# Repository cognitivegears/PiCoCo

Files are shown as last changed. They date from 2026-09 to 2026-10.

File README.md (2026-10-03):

# PiCoCo

A Raspberry Pi Pico 2 (or Waveshare RP2350B-Plus-W) carrier that plugs into
the cartridge slot of a Tandy Color Computer (CoCo 1/2/3). It boots an
HDB-DOS ROM, serves DriveWire disk images through a Becker port at
$FF41/$FF42, and has an output stage for the cartridge sound input (the sound
firmware is not written). Licence: CERN-OHL-S-2.0
(hardware), MIT (firmware), CC-BY-SA-4.0 (docs); see `LICENSE`.

Board revision: **v2.3.1** (98 x 77.2 mm, 2 layers, hard-gold fingers).
Design docs: `docs/hardware-design.md`, `docs/firmware-architecture.md`,
`docs/kicad-workflow.md`. Ordering: `fab/main/READ-BEFORE-ORDERING.txt`.

## If you have a bare board

This is a **bare 98 x 77 mm board with no shell**. It fits no Program Pak
case — the 53.34 x 44.45 mm outline mentioned in the v2.3 spec is the
cased, future-variant footprint, not this board.

1. **Orientation.** The board has no shell and no key. The component side is
   the top; the front silkscreen says `THIS SIDE UP` near the finger tongue
   and the back says `OTHER SIDE UP`. Inserted upside down, +5 V lands on the
   CoCo's /CTS line. There is no reverse protection.
2. **Power off before inserting or removing.** Every insertion.
3. **Module.** Solder a Pico 2 flat on the castellations or on 2x20 headers;
   a Plus-W goes flat (castellations plus the 15 hidden pads; use the
   `stencil-module` paste stencil for the 15 grid pads only and hand-solder
   the castellations). A flat-mounted Pico 2 rests its three underside debug
   pads on grid pads GP29/GP32/GP35: put Kapton tape over those three pads
   first, or use headers. Nothing else goes under the module.
4. **Jumpers (solder bridges, defaults as shipped).**
   - `JP2` 1-2: U10 data-buffer /OE from the hardware decode (default).
     2-3: /OE from firmware GP31 (Plus-W only). Today's firmware holds GP31
     high, so leave JP2 at 1-2 on every build.
   - `JP3` 1-2: audio PWM to header pin 34 (default; sound works on a Pico 2).
     2-3: E clock to header pin 34 instead. Never bridge 2-3 and drive GP34 on
     a Plus-W at the same time.
   - `JP4` open (default): bridge to tie Q to /CART for cartridge autostart of
     ROM images (the classic Program Pak trick). **Bridging JP4 breaks
     HDB-DOS and any DK-signature DOS ROM** — it pulses /CART on every cycle,
     so the CPU jumps to $C000 as code continuously, and a DOS ROM's first
     bytes ("DK") are not a valid instruction. Only bridge it for a
     cartridge-style ROM that expects the classic autostart hookup.
   - `J2` / `J3` (DNP 1x3 pin headers) are twins of JP3 and JP5 on the same
     nets: fit one and use a shunt if you expect to flip the setting often.
     Cut the solder jumper first — a bridged JP and a shunt in the other
     position would short two signals.
   - `JP5` open (default): shares header pin 34 with JP3, so bridge at most
     one of them. 1-2 gives a Pico 2 a firmware-pulsed /CART (the Q4 stage,
     populated); 2-3 gives a firmware-pulsed /NMI instead (the Q3 stage —
     fit R15/R17 too). No firmware drives either position yet.
5. **DNP parts** (not fitted by default): R2 R10 R15 R17 Q3 C12 C15 J1 J2 J3. These
   are all Plus-W provisions or optional stages, by design, not leftover
   indecision — a Pico 2 build works correctly without them. Removing R7
   disables the /HALT boot hold: a blank or dead module then no longer
   halts the CoCo, so a dead Pico presents to the user as a dead CoCo — that
   is the intended failure mode of the hold, not a fault to debug around.
   Fitting C15 (1 uF) and removing R24 gives AC-coupled sound. `J1` ("EXP
   (Plus-W)") breaks out four pad-grid pins that only exist on a Plus-W.
6. **Test points.** TP1 OE_BUS, TP2 RW_BUF, TP3 CTS_BUF, TP4 SCS_BUF, TP5 E_BUF,
   TP6 +3V3, TP7 SND_CART (sound output to the cart), TP8 GND.
7. **Flashing.** Hold BOOTSEL on the module and plug USB in; copy the UF2
   from `firmware/` (see `firmware/README.md`). With the board in the CoCo,
   holding BOOTSEL and pressing the CoCo's own RESET button also enters the
   bootloader, because cart /RESET is tied to the module's RUN pin (R9).
8. **Disk images.** The firmware keeps images in the module's flash and is
   driven from the USB console (`firmware/README.md`). Wi-Fi DriveWire needs
   the Plus-W (`becker net`, `firmware/README.md` "WiFi").
9. **Multi-Pak Interface.** Select the PiCoCo slot for both /CTS and /SCS
   (`POKE &HFF7F` slot value) — the slot register ghosts at `$FF9F` as well
   as `$FF7F`; a CoCo 3 needs the upgraded MPI PAL. The 98 mm body may not
   fit some MPI slot openings; measure first.
10. **Is it alive?** On a CoCo 3, BASIC `PEEK(&HC000)` never reaches the
    cart — check `$FF41`/`$FF42` (the Becker status/data registers) instead.
11. **HDB-DOS.** Not shipped with this board — build it yourself with a
    single `make` from ToolShed's `hdbdos/` tree, or get a prebuilt image
    from Cloud-9 (see `docs/ADDITIONAL_ROADMAP.md` §3 for why binaries
    aren't checked in here). Credit to the DriveWire and HDB-DOS authors and
    maintainers, whose protocol and ROM this board depends on entirely.

## Repository map

```
PiCoCo/        KiCad 10 project (schematic is generated: edit tools/gen_schematic.py)
libraries/     local symbols and footprints (Pico-Carrier, COCO-CART)
tools/         generators and routing/fab tooling (see docs/kicad-workflow.md)
fab/main/      JLCPCB package: Gerber zip, BOM, CPL, module stencil, ordering checklist
breakout/      breadboard-phase boards (cart fingers to 2x20 header, cobbler)
firmware/      RP2350 firmware (host-testable core)
docs/          design documents and roadmap
```

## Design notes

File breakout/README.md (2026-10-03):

# PiCoCo Cartridge Breakout v1.0

A dumb adapter: the 40 fingers of a Tandy Color Computer cartridge slot
brought out 1:1 to a 2x20 0.1" header, so the PiCoCo bus interface can
be breadboarded. It carried the breadboard phase before the main board
existed; `docs/breadboard-plan.md` points to the results.

```
CoCo slot ──[this board]──40-way IDC ribbon──[2x20-to-breadboard adapter]──breadboard
```

Everything here is generated by `tools/gen_breakout.py` (run it with
KiCad's bundled Python). Do not hand-edit the `.kicad_sch`; the `.kicad_pcb`
is also generated, including all routing, and is safe to regenerate.

## What is on the board

| Ref | Part | Purpose |
|---|---|---|
| P1 | 40 gold fingers (`PiCoCo:COCO-CART-FINGERS`) | mates with the CoCo slot |
| J1 | 2x20 shrouded (keyed) IDC box header, vertical | header pin n = cart pin n; the key stops a reversed ribbon |
| F1 | 0.5 A hold polyfuse, 1812 | in series with +5V so a breadboard slip cannot short the CoCo's 5 V rail |
| C1 | 10 uF 0805 X5R, >= 10 V | +5V bulk after the fuse |
| C2 | 100 nF 0805 | +5V bypass |
| R1 + D1 | 1 kΩ 0805 + 0805 LED | power indicator |

Cart fingers 1 and 2 (-12 V and +12 V on CoCo 1/2, unused on CoCo 3) are
**left open**, so ±12 V can never reach the ribbon. Header pins 1 and 2
are tied to GND instead, which gives the ribbon four ground conductors
(1, 2, 33, 34) rather than two.

Board: 52.8 x 99 mm, 2 layer, 1.6 mm. Measured on the CoCo: from the
connector face to the outside of the case is about 1 3/4" (44.5 mm), so
with the 10 mm finger tab the case surface sits about 55 mm from the
finger tip. The header's near row is at 77 mm, its shroud starts at
about 74 mm, so there is a 17 mm bare grip zone outside the case below
the shroud, and the ribbon plugs in with the case on. A silk line at
55 mm marks the approximate case surface. Both copper layers carry a
GND pour that stops 1 mm short of the finger tab.

The shroud of J1 is 58.4 mm long and the board is 52.8 mm wide, so the
plastic overhangs each side edge by about 2.8 mm. That is deliberate:
a keyed header is worth more than a flush one. (An earlier note here
claimed the board could not be wider than the finger tab; measured on
2026-09-18 the CoCo 3 opening is 114.3 x 30.2 mm, so it can.) A
reversed ribbon at an unkeyed header would land +5V on /CTS.

### Finger geometry versus the original cart footprint

Finger width (1.27 mm), pitch (2.54 mm), x positions, layer assignment
(odd on top, even on bottom), and the far end of every pad are identical
to `COCO-CART-2.1X1.75`, the footprint the main PiCoCo board uses. One
thing was changed on purpose: the leading edge of the 39 full-length
fingers was pulled back from 0.44 mm to 1.30 mm from the board edge.
JLCPCB's order form states that a 30° bevel on 1.6 mm stock is 1.13 mm
deep (0.53 mm residual thickness at the tip), so any copper closer than
that sits on the chamfer and gets ground off, leaving bare copper at
the finger tips. 1.30 mm keeps every finger fully on the flat. The
contact wipe zone is millimetres further in, so mating is unaffected.
The +5V finger (9) was already short at the leading edge (mates last)
and is unchanged. The main board's footprint has the same trim.

## Bill of materials

| Ref | Qty | Value | Example part |
|---|---|---|---|
| J1 | 1 | 2x20 shrouded IDC box header, 2.54 mm, vertical, through-hole | any generic "2x20 box header"; overhangs the board edges, see above |
| F1 | 1 | polyfuse 0.5 A hold / 1 A trip, 1812 | Bourns MF-MSMF050-2, Littelfuse 1812L050 |
| C1 | 1 | 10 uF 0805 X5R 10 V | same as the main PiCoCo BOM |
| C2 | 1 | 100 nF 0805 X7R | same as the main PiCoCo BOM |
| R1 | 1 | 1 kΩ 0805 | |
| D1 | 1 | LED 0805, any colour | cathode (pin 1) faces the header |

Off-board, for the breadboard end:

- 40-way IDC ribbon, 15-20 cm, with 2x20 female IDC sockets on both ends
  (sold as "40-pin Raspberry Pi GPIO ribbon cable"). Keep it short; the
  CoCo bus is unterminated.
- The `PiCoCo-Cobbler` board from this directory plus one 2x20 shrouded
  box header and two 1x20 pin headers. Do not substitute a Raspberry Pi
  cobbler; see the note below.

`fab/breakout/PiCoCo-Breakout-BOM.csv` and `-pos.csv` are the machine
readable versions, if you want JLCPCB to place the five SMD parts.

If you would rather not solder SMD: F1 can be replaced by a wire link
(you lose the short-circuit protection), C1/C2/R1/D1 can all be left
off (the board still works, you lose the LED and local bypass).
Everything else is through-hole.

## Ordering

Gerbers, drill and position files are in `fab/breakout/`;
`PiCoCo-Breakout-gerbers.zip` is the upload. Regenerate with:

```
bash tools/gen_fab.sh breakout/PiCoCo-Breakout.kicad_pcb fab/breakout
```

Use the JLCPCB settings in `fab/READ-BEFORE-ORDERING.txt`. The ones that
matter for this board, as the JLCPCB form presents them:

- Layers 2, thickness 1.6 mm (slot fit), 1 oz copper.
- **Surface finish: ENIG.** JLCPCB only offers the gold-finger process
  on an ENIG board; with HASL selected the form warns that the fingers
  will merely be tinned.
- **Gold Fingers: Yes. Beveling: 30°.** The form then shows the bevel
  depth (1.13 mm) and residual thickness (0.53 mm) the finger geometry
  was designed around.
- Confirm Production File: Yes is worth the extra day on a gold-finger
  board; you get to see how they interpreted the fingers and bevel.
- Everything else at defaults: outline tolerance ±0.2 mm, flying-probe
  test, no castellations, no edge plating, no blind slots.
- Minimum quantity is 5. Keep the spares.

Fab-rule check against the published requirements (JLCPCB help
"Gold fingers"; PCBWay "PCB Gold fingers" page):

| Rule | Requirement | This board |
|---|---|---|
| finger to board edge, 30° bevel, 1.6 mm | JLC bevel depth 1.13 mm (order form); help page says >= 0.6 mm; PCBWay >= 0.5 mm | 1.30 mm |
| copper in the bevel zone | none | none: fingers end at 1.30 mm, pours stop 11 mm up, traces leave pads inward |
| pads / plated holes near fingers | >= 1.0 mm | nearest is J1 at ~38 mm |
| board size after bevel | JLC >= 50 x 50 mm, PCBWay width > 45 mm | 52.8 x 99 mm (inside the 100 x 100 mm price tier) |
| fingers on one edge only | yes | yes |

On PCBWay's order form the equivalents are "Gold fingers: Yes",
"Beveling: 30°", surface finish for the fingers is implied by the gold
finger option. The cobbler has no fingers and needs no special options.

When the boards arrive, test-fit one into the slot with the CoCo **off**
before soldering anything.

## Pin map

Header pin n is cart pin n, except 1 and 2 which are GND on the header
and open at the fingers. Odd pins are on the header row nearest the
fingers (top copper), even pins on the far row (bottom copper), which is
also how the fingers are arranged on the card edge. Signal directions
are from the CoCo's point of view.

| Pin | Signal | Dir | Pin | Signal | Dir |
|---|---|---|---|---|---|
| 1 | GND (cart -12 V finger open) | | 2 | GND (cart +12 V finger open) | |
| 3 | /HALT | in, open collector | 4 | /NMI | in |
| 5 | /RESET | out (also driven by reset button) | 6 | E | out |
| 7 | Q | out | 8 | /CART | in (FIRQ) |
| 9 | +5V (after F1) | power | 10 | D0 | bidi |
| 11 | D1 | bidi | 12 | D2 | bidi |
| 13 | D3 | bidi | 14 | D4 | bidi |
| 15 | D5 | bidi | 16 | D6 | bidi |
| 17 | D7 | bidi | 18 | R/W | out |
| 19 | A0 | out | 20 | A1 | out |
| 21 | A2 | out | 22 | A3 | out |
| 23 | A4 | out | 24 | A5 | out |
| 25 | A6 | out | 26 | A7 | out |
| 27 | A8 | out | 28 | A9 | out |
| 29 | A10 | out | 30 | A11 | out |
| 31 | A12 | out | 32 | /CTS | out |
| 33 | GND | | 34 | GND | |
| 35 | SND | in (audio) | 36 | /SCS | out |
| 37 | A13 | out | 38 | A14 | out |
| 39 | A15 | out | 40 | /SLENB | in |

## The cobbler note (read before buying an adapter)

Raspberry Pi "cobbler" style adapters are the obvious 2x20-IDC-to-
breadboard part, and their silkscreen will show Pi names (GPIO2, 5V,
GND...) that mean nothing here; ribbon conductor n still lands on
breadboard position n. The Pi header pin names, for cross-reference when
you are staring at a cobbler:

| Pin | Pi label | Pin | Pi label |
|---|---|---|---|
| 1 | 3V3 | 2 | 5V |
| 3 | GPIO2 | 4 | 5V |
| 5 | GPIO3 | 6 | GND |
| 7 | GPIO4 | 8 | GPIO14 |
| 9 | GND | 10 | GPIO15 |
| 11 | GPIO17 | 12 | GPIO18 |
| 13 | GPIO27 | 14 | GND |
| 15 | GPIO22 | 16 | GPIO23 |
| 17 | 3V3 | 18 | GPIO24 |
| 19 | GPIO10 | 20 | GND |
| 21 | GPIO9 | 22 | GPIO25 |
| 23 | GPIO11 | 24 | GPIO8 |
| 25 | GND | 26 | GPIO7 |
| 27 | ID_SD | 28 | ID_SC |
| 29 | GPIO5 | 30 | GND |
| 31 | GPIO6 | 32 | GPIO12 |
| 33 | GPIO13 | 34 | GND |
| 35 | GPIO19 | 36 | GPIO16 |
| 37 | GPIO26 | 38 | GPIO20 |
| 39 | GND | 40 | GPIO21 |

**The trap, and it is real:** Adafruit's T-Cobbler Plus joins all eight
GND-labelled pins (6, 9, 14, 20, 25, 30, 34, 39) into one net and both
5V pins (2, 4) into another, on the cobbler PCB itself. That is verified
from the Eagle schematic in Adafruit's `Adafruit-Pi-Cobber-PCBs` GitHub
repo. Plugged into this breakout it would short CoCo E, +5V, D4, A1, A6,
A11, GND and A15 together the moment the ribbon is seated. Assume every
Pi cobbler and Pi GPIO breakout does the same unless you have measured
it.

**Use `PiCoCo-Cobbler` instead.** It is the second board in this
directory: a keyed 2x20 IDC box header on top, two 1x20 pin rows
underneath 0.3" apart to straddle the breadboard channel, and forty
straight traces. Nothing is bussed. The shroud key means the ribbon can
only seat one way at that end. Order it in the same JLCPCB batch
(`fab/cobbler/PiCoCo-Cobbler-gerbers.zip`, plain 2-layer, no gold
fingers needed). Parts: one 2x20 shrouded box header, two 1x20 pin
headers, soldered with the pin headers on the bottom.

## Assembly notes

- Cobbler: solder the two 1x20 pin headers on the **bottom** (long pins
  down) and the box header on top. Trim the box header's pin stubs flush
  on the bottom; they sit over the breadboard's centre channel, and on
  breadboards where that channel is not a groove the stubs would rest on
  the plastic.
- Cobbler: the two pin rows are 0.3" apart, so they land in rows e and f
  of a standard breadboard, leaving four free holes per signal on each
  side.
- Breakout: orientation is the same as a Program Pak: component side
  (the side with the "1" finger label and all the parts) faces up in a
  CoCo 3 side slot, i.e. the way the cartridge label would face.
- Ribbon: 40-way, female IDC both ends, red stripe to pin 1 at both
  ends. Shorter is better; 15-20 cm is plenty. The CoCo bus has 5 ns
  TTL edges and only four ground returns in the ribbon, so a 50 cm
  cable will ring.

## Before the first insertion (five minutes with a meter)

1. Breakout, nothing plugged in: no continuity between header pin 9
   (+5V) and any of pins 33/34/1/2 (GND); no continuity between any two
   adjacent header pins except 1-2 and 33-34.
2. Continuity finger 3 to header pin 3, finger 10 to pin 10, finger 39
   to pin 39, finger 40 to pin 40 (spot-check both sides and both rows).
3. Continuity finger 9 to header pin 9 through F1 (a few ohms).
4. Ribbon plus cobbler plugged in: continuity from finger 9 to the
   cobbler pin labelled +5V, and from finger 33 to the cobbler GND pin.
   If +5V lands on /CTS, a ribbon end is reversed.

## Bring-up checks

1. Board alone in the slot, ribbon unplugged: CoCo boots to BASIC, D1
   lights, +5V reads about 5 V at header pin 9.
2. Logic analyzer on E, Q, R/W, /CTS, /SCS at the breadboard:
   `PEEK(&HC000)` pulses /CTS, `PEEK(&HFF41)` pulses /SCS. On a CoCo 3
   BASIC runs from RAM and a `$C000` PEEK never reaches the cart; use the
   `$FF41` PEEK.

Power the CoCo off before inserting or removing the board. The fuse
protects the CoCo's rail from shorts, not the CoCo from hot-plugging.

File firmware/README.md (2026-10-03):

# PiCoCo firmware

Pico 2 <-> Tandy CoCo cartridge firmware. See
`docs/superpowers/specs/2026-09-07-firmware-design.md` for the design.

## Host build (Mac/Linux, for tests and `picoco-host`)

```
brew install cmake ninja
cmake -B build-host -G Ninja -DPICOCO_HOST=ON firmware
ninja -C build-host
ctest --test-dir build-host --output-on-failure
```

## `picoco-host`

A TCP-socket DriveWire server for bring-up/testing on the Mac, built as part
of the host build above.

```
./build-host/picoco-host [--dir DIR] [--port 65504] [--mount N=FILE[,ro]]... \
    [--hdbdos on|off] [--replay FILE]
```

- `--dir DIR`: directory disk images resolve from (default `.`).
- `--mount N=FILE[,ro]`: mount `FILE` (relative to `--dir`) as drive `N`;
  repeat for multiple drives. Add `,ro` to mount read-only.
- `--hdbdos on|off`: HDB-DOS drive-by-LSN addressing (default: whatever
  `dw_init` sets — currently on). The effective value is printed at startup.
- `--replay FILE`: replay a `dw capture` recording (see
  `tests/fixtures/README.md` for the chunk format) — feeds only the dir-0
  (rx) chunks back into the server, ignoring the dir-1 (tx) chunks it
  recorded, prints a stats summary, and exits; no socket is opened. Useful
  for replaying a captured session without XRoar/CoCo hardware attached. A
  malformed (truncated) capture file prints an error and exits 1.
- With no `--replay`, listens on `--port` (default 65504, the standard
  Becker port), serving one client at a time; disconnect and reconnect is
  fine. `Ctrl-C` (SIGINT) prints the stats summary and exits.

### Host integration test

`firmware/tools/dwtest.py` is a stdlib-only DriveWire client that exercises
`picoco-host` end to end: DWINIT, a full-image READEX sector compare, a READ
checksum check, a corrupted READEX/WRITE (expect `E_CRC`), an unmounted-drive
read (expect `E_NOTRDY`), a scratch-drive WRITE/READEX round trip, and TIME.

```
mkdir -p /tmp/pc
python3 -c "open('/tmp/pc/t.dsk','wb').write(bytes([(i>>8)&255 for i in range(161280)]))"
cp /tmp/pc/t.dsk /tmp/pc/s.dsk
./build-host/picoco-host --dir /tmp/pc --mount 0=t.dsk --mount 1=s.dsk --hdbdos off &
python3 firmware/tools/dwtest.py --image /tmp/pc/t.dsk --drive 0 --scratch s.dsk
kill %1
```

Expected: every check prints `ok`, dwtest.py exits 0. Repeat with
`--hdbdos on` on both the server and `dwtest.py --hdbdos` for the second
addressing mode.

A new connection replaces a client already held (log line
`picoco-host: client replaced`), so a rebooted Pico is not blocked by its old
dead socket. The server listens on all interfaces, so any LAN peer can evict
the current client; it is a dev tool.

Note: on macOS under a sandboxed shell, binding the listening socket can
fail with `Operation not permitted`; run the server (and the client) with
the sandbox disabled.

### Manual check: XRoar

Not automated — requires a real HDB-DOS DriveWire ROM, which the user
supplies at `firmware/roms/` (not checked in). With `picoco-host` running
and a drive mounted on 0:

```
xroar -machine coco3 -cart becker -becker-ip 127.0.0.1 -becker-port 65504 \
    -cart-rom firmware/roms/hdbdos_dw.rom
```

(Flags per XRoar's manual for the Becker-port cartridge.) Expected: booting
into HDB-DOS and running `DIR` lists the files on the image mounted on
drive 0.

### `tools/tracedump.py`

Decodes `trace dump [n]` console output (lines of `seq idx R|W data`, e.g.
`1973593 2dc2 R 09`; `seq` counts bus events since boot, there is no
timestamp) into a readable log with CoCo addresses and a running DriveWire
opcode decoder:

```
python3 firmware/tools/tracedump.py trace.txt      # or pipe via stdin
```

Each line becomes `seq  $ADDR  R/W  data  note`, where `$ADDR = 0xC000 +
idx`. Notes: `ROM` for ROM-space reads, `BECKER_STATUS`/`BECKER_DATA` for
Becker-port accesses (status reads add `data avail`/`no data`), and for a
DriveWire request written to `$FF42`, the opcode name plus, once its 4
drive/LSN payload bytes arrive, `drive=N lsn=N` on the completing line.
Non-matching lines (e.g. the console's `ok`/`err ...` replies mixed into the
same log) are skipped.

## Pico build

Cross-builds `build-pico/picoco.uf2` for the Pico 2 (RP2350A) using the Pico
SDK, cloned outside the repo:

```
cd /Users/cognitivegears/projects
git clone --branch 2.3.1 --depth 1 --recurse-submodules --shallow-submodules \
    https://github.com/raspberrypi/pico-sdk.git

cmake -B build-pico -G Ninja -DPICO_SDK_PATH=/Users/cognitivegears/projects/pico-sdk firmware
ninja -C build-pico
```

For a Waveshare RP2350B-Plus-W build instead, add `-DPICOCO_BOARD=plusw`
(default is `pico2`); this selects `firmware/boards/plusw.h` (pin map) and
the SDK board `picoco_plusw` (RP2350B, 48 GPIO, 16 MB flash):

```
cmake -B build-pico-plusw -G Ninja -DPICO_SDK_PATH=/Users/cognitivegears/projects/pico-sdk \
    -DPICOCO_BOARD=plusw firmware
ninja -C build-pico-plusw
```

Both builds run `firmware/tools/check_core1_flash_free.py` as a POST_BUILD
step, failing the build if any code core1's event loop can reach (directly,
or through a read or write hook) lands outside SRAM.

Flash a Pico 2 that's in BOOTSEL mode (hold BOOTSEL while plugging it in):

```
firmware/tools/flash.sh build-pico/picoco.uf2
```

The console appears as the second of two `/dev/tty.usbmodem*` ports; use
`screen /dev/tty.usbmodemXXXX2` or `picocom` to talk to it.

### Console checks

`firmware/tools/pconsole.py` is a stdlib-only serial console driver: it opens
the console port raw at 115200, sends each command, and prints replies until
a line reading `ok` or starting with `err` (or a 6 s timeout). Use the
`/dev/cu.usbmodem*` device, not `/dev/tty.usbmodem*` — opening the `tty`
node non-interactively blocks waiting for carrier detect on macOS.

```
python3 firmware/tools/pconsole.py /dev/cu.usbmodemXXXX2 \
    'fs format' 'fs ls' 'dw selftest'
```

Bus-engine-specific commands: `bus selftest` runs the on-chip fake 6809
self-test (see "Self-test without a CoCo" below); `bus drive on|off`
starts or stops the read path (off = capture-only: nothing is driven, but
writes, the trace and the counters keep working); `bus engine` prints which
PIO state machines and DMA channels the engine and everything else hold;
`cart on|off|auto`
sets the firmware `/CART` pulse policy (`auto`, the default, pulses for
500 ms after `/HALT` release when a loaded ROM is not DK-signature DOS;
Plus-W only today — a Pico 2 build has no `PIN_CART_DRV`, so `cart on`
and `cart off` are refused there with `err cart: needs Plus-W (JP5 on
a Pico 2)`; `auto` and the bare query still work on both boards);
`rom load <file>` accepts a plain
8 KB/16 KB image or a banked Games Master Cartridge image (32 KB, 64 KB
or 128 KB, switched by writes to `$FF40`), refusing any other size with
`err rom load: size must be 8K, 16K, or banked 32K/64K/128K`.

#### Self-test without a CoCo

`bus selftest [stress] [radio] [restarts] [switches]` drives the real PIO
bus engine, core1's event loop and the device hooks from an on-chip PIO1
state machine at 6809 timing — no CoCo needed. Run it on a bare module
only (see `docs/firmware-architecture.md` §3.2.5). **Unplug the Pico from
the CoCo cart edge first; the guard below is a backstop, not a licence to
leave it plugged in.** Before touching any pins the command refuses with
`err bus selftest: bus is live (CoCo attached), refused` if either:
`bus_stats.cycles` moves during a 100 ms sleep (a running CoCo driving
cart cycles), or the address/`R/W` pins (plus `OE_BUS` on a Pico 2, or
`E`/`Q` on a Plus-W) aren't perfectly still for a 10 ms, 50 µs-interval
sample — an idle CoCo running from RAM produces no cart cycles at all, but
those pins still toggle with the CPU clock through always-enabled buffers,
where an unplugged board just sits on its pull-ups.

With no argument it runs every check once (about 2 s) and ends with
`selftest rom cleared; reload with rom load`, then `selftest fast pass`
or `err selftest fast FAIL`. Options:

| Option | Effect |
|---|---|
| `stress` | core0 runs a memcpy load during the bursts |
| `radio` | Plus-W: radio scans and cyw43 polling during the bursts |
| `restarts` | after the first checks, 40 bursts with engine restarts every 50 µs, one summary line, then stop: `fast restarts: 40 bursts, <n> restarts, spurious 0 wrong 0 zero <n>, events missing 0` |
| `switches` | after the first checks, 40 bursts of bank switches at random phases, then stop: `fast switches: <n> in 40 bursts (S=<s>), 0 bursts bad; bad 0, wrong bank 0; next cycle old 0` and a phase histogram |

The gated lines and what a pass shows (`<n>` varies run to run; the
Plus-W differences are in brackets; full verbatim runs per board are in
`TEST_PLAN.md` section K):

| Line starts | Pass |
|---|---|
| `fast drop flag:` | `... RXSTALL yes (set before the drop: no)` |
| `fast 1.79MHz S=36 (240 ns):` x5 [`S=40 (266 ns)`] | `mismatches 0/4096 (zero 0 stale 0 spurious 0 wrong 0) rel_nonzero 4096 lost 0` |
| `fast event rate 1.79MHz:` | `counted 20480 of 20480, lag max 0, drop 0, lap 0` |
| `fast 1.79MHz mixed r/w`, `gaps r/w/unsel`, `writes r/w/io/unsel` | `mismatches 0/4096 ...`, `lost 0` (rel_nonzero 2731, 2048, 3414) |
| `fast writes:` | `0 lost, 0 out of order, 0 wrong data of 1366` |
| `fast events:` (twice) | `0 mismatches of 512 ...; counted 3414 of 3414`, then `... counted 4096 of 4096` |
| `fast 1.79MHz restarts <n> under a gaps burst:` | `spurious 0 wrong 0 (zero <n> = cycles lost to a restart); events 3072 of 3072` |
| `fast 1.79MHz gaps after restarts` | `mismatches 0/4096 ... lost 0` |
| `fast lap:` | `resync 1, next burst events 4096 of 4096` |
| `fast stall:` | `detected 1, pins never driven during the stall, next burst 0 mismatches` |
| `fast 1.79MHz bank switches <n> under a reads burst` / `gaps burst` | `bad 0, wrong bank 0, lost 0; old-bank reads <n>, next cycle old 0` |
| `fast drive off:` | `0 driven, events 3414 of 3414, writes 0 lost` |
| `fast banks:` / `fast io page:` | `8/8 banks read their own pattern, 0 mismatches` / `same in 8 banks` |
| `fast becker 1.79MHz:` and `0.89MHz:` | `2048 bytes, 0 lost, 0 duplicated, 0 phantom; underrun 0, overrun 0, 2049 polls in 12293 cycles, fetches bad 0, stalls 0` |
| `fast event rate with Becker 1.79MHz:` | `counted 12293 of 12293, lag max <n>, drop 0, lap 0` (lag max 1-2) |
| `fast becker back-to-back:` | `ready -> 02,5c; empty -> 00,ff (stable)` |
| `fast bank switch 0.89MHz:` | `new bank at +1 cycles (hook <n>..<n> clk); 512 switches: +0 0, +1 512, ...; bad 0, lost 0` [`+0` on 1-95 of 512, `+1` on the rest]; `+2` or later fails |
| `fast bank switch 1.79MHz:` | as 0.89 MHz, `+1 512`; only `bad`/`lost` are gated |
| `fast 1.79MHz response_clk` | `22 (146 ns after OE_BUS fell)` [`29 after E rose (raw; 193 ns)`, then `corrected 24..24 ...; margin to 36: 12..12`] |
| [`fast 1.79MHz late /CTS`, `late /SCS`, each `+ writes`] | [`mismatches 0/4096 ... lost 0`; `response_clk 33 after E rose (raw; 220 ns)`] |
| `fast 0.89MHz S=72 (480 ns):` [`S=77 (513 ns)`] | `mismatches 0/4096 ... lost 0` |

Information only: the `fast dma`, `fast engine`, `fast test`, `fast
timing`, resource, sweep, `release_clk` (6 clk on a Pico 2, 11 on a
Plus-W), `fast becker data then status` (`02` at both speeds, see
`docs/firmware-architecture.md` §3.4) and, on a Plus-W, `fast fake decode
delay` and `fast realistic point` lines.

**`status` after a full self-test** shows `engine_stall 1`, `event_lap 1`,
`event_dup` around 1000-1100 and Becker `underrun` up by 5. The test causes
all of them on purpose (a forced stall, a forced lap, bursts that re-read an
address back to back, and the empty-port back-to-back reads);
`stats reset` clears them. `restarts` stops before all three checks;
`switches` stops after the lap and stall but before the Becker checks, so
it leaves `underrun` alone.

```
python3 firmware/tools/bench.py [--port /dev/cu.usbmodemXXXX2] [--skip-if-absent]
```

`bench.py` runs `version` then `bus selftest` over the console (auto-
detecting the second `/dev/cu.usbmodem*`/`/dev/ttyACM*` node if
`--port` is omitted), prints every line, and exits 0 on `selftest fast pass`,
1 on any failure or timeout, or 77 with `--skip-if-absent` when no Pico
console is found at all. It is also registered as the `bench` ctest
target, but only opt-in — configure with `-DPICOCO_BENCH=ON` to add it,
since it drives real bus pins and must not run against a plugged-in
board by accident. With `PICOCO_BENCH` off (the default), `ctest
--test-dir build-host` doesn't know about it at all. The self-test
clears whatever ROM was loaded (`rom off`) as part of running, so
`bench.py` sends `reboot` at the end to replay a saved `rom load` from
`picoco.cfg`.

#### `status`: bus counters

```
bus cycles <n> reads <n> writes <n> write_overrun <n>
bus engine_stall <n> event_lag_max <n> event_drop <n> event_lap <n> event_dup <n> start_wait_cap <n>
bus whooks <n>
bus drive on|off
becker reads <n> writes <n> underrun <n> overrun <n>
```

- `cycles`, `reads`, `writes`: selected cycles, counted by core1 as their
  events arrive. Unselected cycles never reach the engine.
- `write_overrun`: writes dropped because core0's write ring was full.
- `engine_stall`: read-path restarts by the stall guard
  (`docs/firmware-architecture.md` §3.3).
- `event_lag_max`: most events waiting for core1, sampled every 256
  events; saturates at 256.
- `event_drop`: 1 ms checks that found the event state machine had
  dropped a cycle (its FIFO was full).
- `event_lap`: times core1 fell a whole ring (2048 events) behind and
  resynced; the events in between are lost.
- `event_dup`: read events identical to the one before them (same
  address, same data). A 6809 never issues the same read twice in a row,
  so on a CoCo each one is an OE_BUS high blip inside a cycle, which splits
  the cycle into two events (a bench CoCo 2 shows ~9 % of reads, a CoCo 3
  none; TEST_PLAN K). The self-test's synthetic bursts do re-read addresses
  back to back, so a full run leaves it at ~1000-1100 by design.
- `start_wait_cap`: Plus-W only, engine starts whose wait for OE_BUS high
  hit its cap. Such a start leaves the read SM stopped, and the next
  millisecond tick retries it.
- `whooks`: write hooks run on core1 (today the `$FF40` bank hook).

After a CoCo session all of `engine_stall`, `event_drop` and `event_lap`
should read 0. `stats reset` clears these, the Becker counters and
`dw stats`. Under traffic it races core1's own counters: `cycles`, `reads`
and the Becker `reads` may miss a reset by a few percent. `engine_stall`,
`event_drop`, `start_wait_cap`, `event_lap` and `underrun` are reliable.

#### Plus-W limits (until the respin)

The PIO engine gives the Plus-W the same bus as a Pico 2 until the next
board revision (`docs/ADDITIONAL_ROADMAP.md` §8):

- JP2 must be at 1-2 (hardware `/OE`, the default). Firmware holds `OE_FW`
  high.
- A14 and A15 are not used: no 32K Program Paks, no Extended BASIC at
  `$8000`.
- No firmware-decoded addresses (`$FF60-$FF7F`): they went with the CPU
  loop (tag `fw-1.4-cpu-loop`).
- `bus selftest net` answers `err bus selftest net: not supported by this
  engine` (a Pico 2 answers `err net: needs Plus-W`).

### Filesystem

The on-flash FAT filesystem (`fs_flash.c`/`dw_store_fatfs.c`) lives at
`PICOCO_FS_OFFSET..` of flash, sized by the board header
(`firmware/boards/*.h`): `0x180000..0x3FFFFF` on a Pico 2 (4 MB flash, 640
FAT12 clusters), `0x180000..0xFFFFFF` on a Plus-W (16 MB flash, 3712
clusters). Reset safety across a CoCo `/RESET` (the Pico reboots on every
one, at any instant) comes
from `dw_server.c` syncing after every successful DriveWire write, and
`fs_flash_write_blocks` skipping the erase/program cycle for any 4 KB block
that didn't actually change (the common case for a resync of the root dir
or FAT). `picoco.cfg` at the root holds the saved console config (see
`save`/`console_run_config`); DriveWire disk images and `dw capture`
recordings also live at the root.

### Export

The on-flash FAT volume can be exported to the Mac (or any USB host) as a
removable drive, e.g. to drag `.dsk` images on/off without a DriveWire
transfer:

1. `dw eject 0`..`dw eject 3` (or whichever drives are mounted) — `fs export`
   refuses with `err eject all drives first` while any DriveWire drive is
   mounted, since FatFS can't be unmounted out from under an open `FIL`.
2. `fs export` — unmounts FatFS and presents the partition over USB MSC as a
   volume named `PICOCO`; the board's LED goes solid while exporting.
3. Drag disk images onto the `PICOCO` volume in Finder, then eject it there
   (or `diskutil eject /Volumes/PICOCO`).
4. `fs import` (or `reboot`) re-mounts FatFS for DriveWire/console use.

macOS writes `.fseventsd/` and `._*` AppleDouble files to the volume; `fs ls`
hides any name starting with `.`, so these don't show up and are harmless.

## Console commands added in 1.2

DW4-compatible disk commands (used by NitrOS-9's `dw` utility and the
`coco/` manager program equally):

- `dw disk show [n]`: with no argument, lists every mounted drive in DW4's
  wire format; with `n`, shows just that drive's file.
- `dw disk insert <n> <file>`: same as `dw mount n file`, but the file
  name is the rest of the line (spaces allowed) and an occupied drive is
  ejected first.
- `dw disk eject <n>`: ejects drive `n`.

`fs new <name>`: creates a blank, formatted 35-track (161,280-byte)
RS-DOS image, byte-for-byte the same as ToolShed's `decb dskini` (all
`$FF` except track 17 sectors 1 and 2, as DSKINI leaves them). Refuses an
existing name, a name 32 characters or longer, a name that fails
`dw_disk_name_ok` (empty, a control byte, a byte $80 and above, or `/`,
`\`, `:`), and `picoco.cfg` (see below).

`rom boot <file>`: records the ROM to load on the *next* boot only (no
live swap under a running DOS); checks the file exists and is 8192 or
16384 bytes. `status` now shows both `rom now` (what's currently driving
`/CTS`) and `rom next` (what `rom boot` + `save` will load at the next
reset).

`rom load manager` loads the manager stub that is built into the firmware
(no file needed). `rom launch <file>` loads a ROM for this session only and
leaves the next-boot choice alone (console only, not available over the
DriveWire command channel); `rom load` also sets the next-boot ROM. `rom off`
is now a saved choice.

A write of `$A5` to `$FF43` hands the Becker port to the manager UI in every
Becker mode, `$5A` returns it; see
`docs/superpowers/specs/2026-10-01-rom-manager-design.md`.

**Upgrading from 1.3.** A `picoco.cfg` with no `rom` line, including one saved
after `rom off` by 1.3 or earlier, now boots the manager. On a machine with
Extended BASIC the manager autostarts. To keep the old behaviour run `rom off`
then `save` once. A config that has a `rom load ...` line is unaffected.

Press RESET twice within 2 seconds to load the manager for that boot only; the
saved ROM is unchanged. On a CoCo 3 nothing needs typing (a hardware RESET
makes the CoCo 3 recopy the cart); on a CoCo 1/2 without Extended BASIC then
type `EXEC 49154`. The marker is a small byte log in one flash sector just
below the filesystem: two single-byte writes per boot and one sector erase
about every 2000 boots. A 150 ms debounce at boot ignores contact bounce. The
boot log shows `boot, reset log N` (odd N means a double RESET was seen) and
`double reset: manager for this boot`. Boot log timestamps are in
microseconds.

`time` now also prints `clock kept|lost`, showing whether the RP2350's
always-on timer carried the clock across the last `/RESET` (see
`docs/superpowers/specs/2026-09-23-coco-manager-design.md` §4.5).

`picoco.cfg` can never be mounted (`dw mount`/`dw disk insert`) or
created (`fs new`) as a disk image, on the console or over DriveWire: it
replays at boot with full USB privilege (`fs format`, `smoke`, `becker
off`, ...), so letting a remote `WRITE` rewrite it would hand that
privilege to whatever wrote the disk. The guard (`dw_disk_name_ok` in
`firmware/src/dw/dw_disk.c`) refuses the name outright rather than
matching only a `picoco.cfg` path component: FatFS's `create_name` ends a
path at any byte below `$20` and silently drops a trailing separator, so
a name like `picoco.cfg\` or `picoco.cfg` followed by a control byte
would still open `picoco.cfg` on the Pico even though a component-based
check sees something else (or nothing) as the last component. Bytes $80
and above are refused too: FatFS's CP437 short-name upcase table (`ff.c`
`TBL_CT437`) folds several of them onto plain ASCII letters (`$A2` folds
to `O`), so `pic\xA2co.cfg` would otherwise open `picoco.cfg` on the Pico
without matching it byte-for-byte. So the guard refuses any name with a
byte below `$20`, `$7F`, or $80 and above, or a `/`, `\`, `:` at all, in
addition to matching `picoco.cfg` itself.

### WiFi (Plus-W)

Firmware 1.3. Plus-W builds only (`PICOCO_HAVE_NET`); a Pico 2 has no radio
and every `net` command that needs one answers `net: needs Plus-W`. The
CoCo reaches a DriveWire server (DriveWire 4, `picoco-host`, FujiNet with
BoIP) over one TCP connection, in place of USB.

Radio pins (verified 2026-09-29 from the Waveshare schematic and a live
scan): WL_ON GP36, WL_D/HOST_WAKE GP37, WL_CS GP38, WL_CLK GP39, LED on
WL_GPIO0, VBUS on WL_GPIO2, VSYS sense GP46.

| Command | Effect |
|---|---|
| `net [status]` | State, SSID, `net psk set\|unset` (never the passphrase), server, IP, bytes, retries, `net radio yes\|no`, `net mode <running> boot <next>`. |
| `net join <ssid>` | Store the SSID (spaces allowed). |
| `net psk [<psk>]` | Store the passphrase; empty clears it (open network). |
| `net server <host> [port]` | Server; port 1-65535, default 65504. DNS names work, `.local` names do not (no mDNS). |
| `net forget` | Clear all settings and stop the radio. |
| `net scan` | One `ssid <name> rssi <n> chan <n>` line per network. Blocks up to 5 s. |
| `net mode net\|native` | Sets the NEXT-BOOT mode only; `save` writes it. |
| `becker net` | Console-only live switch. Refused with `net: needs Plus-W` or `net: set ssid and server first`. |

`save` writes `net join`, `net psk` (if set) and `net server` before the
`becker` line, so replay has them first. Example `picoco.cfg`:

```
net join MyLan
net psk hunter2hunter2
net server 192.168.1.20 65504
becker net
```

Credentials are plain text in `picoco.cfg`. The config-replay error log
redacts `net psk` lines. The remote allowlist has the bare `net` verb.

**Boot.** With `becker net` saved, /HALT stays held until the socket is up
or 10 s pass. Then the board falls back to native mode
(`net failed (<reason>), native fallback`); the saved config still says net
and retries continue every 2 s. `becker net` re-arms after a fallback. After a fallback the link keeps
retrying in the background; `net status` can show `up` while the board is
running native, and `becker net` switches over immediately. A saved
`becker net` on firmware 1.2 is a usage error there and leaves Becker off,
so clear it before downgrading.
Reasons: `no such network`, `bad password`, `dhcp timeout`, `dns failed`,
`refused`, `link lost`, `not configured`, `join rejected`. Rings are cleared on every
reconnect. After joining, WiFi power save is off. Once per boot, on link-up,
SNTP seeds the clock only if none is running (`clock lost`); it never
overwrites a `time set` (SNTP is UTC, `time set` is local).

**Latency rule.** The server must answer within about 200 ms round trip.
Servers abandon a half-finished op after 250 ms (`picoco-host`) or 200 ms
(DW4 `ReadByteWait`). A link drop mid-transfer leaves the CoCo waiting
until reset (accepted limitation; reset reboots the Pico, which reconnects).

**`bus selftest net`** is not supported by the PIO engine: it answers
`err bus selftest net: not supported by this engine`. The WiFi transport is
checked on a CoCo instead (TEST_PLAN G.2); the firmware 1.4 version of the
test (DWINIT and 20 OP_TIME round trips through the fake 6809 and the
socket) is at tag `fw-1.4-cpu-loop` if a bare-module check is ever wanted.

### DriveWire virtual-serial command channel

`firmware/src/dw/dw_vser.c` implements DW4's virtual-serial command mode
(channels 1-13; one session at a time) so any DW4 client — NitrOS-9's
`dw`, DwTerm, or the `coco/` manager program — can run console commands
over the same Becker/DriveWire link used for disk I/O, framed exactly as
DW4 Java 4.3.3p (`OK command successful` / `FAIL nnn <msg>`, both
terminated `\n\r`). Reopening a channel after a reply was already queued
starts a clean session rather than piling onto the stale one.

Remote commands go through a deny-by-default allowlist
(`console_exec_remote` in `firmware/src/console/console.c`); only these
run over DriveWire:

    status version help fs ls fs new dw mount dw eject dw hdbdos
    dw disk rom boot time save

Everything else (`smoke`, `halt`, `bus`, `becker`, `fs
format|rm|export|import`, `rom load|launch|pattern|off`, `trace`, `crash`,
`log`, `stats`, `dw capture|selftest|stats`, `reboot`, `bootsel`, ...)
answers `FAIL 255 console only` — a new console command is USB-only
until someone adds it to the allowlist.

Firmware version is 1.4.

## Bring-up

A new board follows `docs/pcb-bringup.md`; the bench checks are
`TEST_PLAN.md` sections F-K. Before anything else: on macOS, approve the
Pico once under System Settings -> Privacy & Security -> "Allow accessories
to connect", or it enumerates over USB but exposes no serial ports. The
console is the second `/dev/cu.usbmodem*` device, the Becker bridge port is
the first. To reflash: send `bootsel` on the console (see `flash.sh` above,
or `python3 firmware/tools/pconsole.py /dev/cu.usbmodemXXXX2 bootsel`), wait
for `/Volumes/RP2350` to mount, then `cp -X build-pico/picoco.uf2
/Volumes/RP2350/`.

Run commands with `pconsole.py` as shown in "Console checks" above. `fs
export`/`fs import` are the "Export" steps above; use them to move ROM
images and disk images on and off the board.

The quickest check that a board answers, with no ROM needed: `becker loop`,
`bus drive on`, then on the CoCo `POKE &HFF42,65: PRINT PEEK(&HFF41),
PEEK(&HFF41), PEEK(&HFF42)` prints `0 2 65`, and `trace dump` shows
`3f42 W 41` (the first `PEEK(&HFF41)` always returns the pre-POKE status:
core1 refreshes the table only after a read, single-writer rule; the `W`
byte is the bit-order check, a swapped pair still echoes 65).

Three tools to reach for when a check doesn't pass:

- `trace dump [n]` piped through `tools/tracedump.py` (see above): the ring
  freezes by itself at the first Becker underrun (that read is its last
  entry) or DriveWire CRC error; `trace run` thaws it. Reach for
  this when a CoCo-side PEEK/POKE doesn't show the address or data you
  expect.
- `dw capture on <file>` (`dw capture off` stops it) plus
  `picoco-host --replay` (see "picoco-host" above): reach for this when a
  bridge or native DriveWire session is flaky and you want to replay the
  exact byte stream off the CoCo for debugging.
- `status`, and `dw stats`/`stats reset`: a quick health check at any
  point (`engine_stall`, `event_drop`, `event_lap`, `crc_err`, `underrun`).

## Licensing

Firmware code is under the top-level project license. Vendored third-party
code: `third_party/fatfs/` is FatFs R0.15a by ChaN, under the FatFs license
(BSD-style; see `third_party/fatfs/LICENSE.txt`). The Pico build also links
the Raspberry Pi Pico SDK and TinyUSB, each under their own upstream
licenses (BSD-3-Clause and MIT respectively).

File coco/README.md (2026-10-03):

# PiCoCo manager (CoCo side)

Build: `make` (needs CMOC, LWTOOLS, ToolShed `decb`). Host tests: `make test`.

## Toolchain

- **LWTOOLS** (`lwasm`, `lwlink`, `lwar`) and **XRoar** via `brew install lwtools xroar`.
- **CMOC** (0.1.100) built from source from `http://sarrazip.com/dev/cmoc.html`
  and installed to `/opt/homebrew` (`./configure --prefix=/opt/homebrew && make
  && make install`). CMOC's `configure` detects `lwasm`/`lwlink`/`lwar`, so
  LWTOOLS must already be on `PATH`. The tarball's `doc/cmoc-manual.markdown`
  (checked against `--org`, `asm {}`, `inkey()` syntax in later tasks) is kept
  at `/opt/homebrew/share/doc/cmoc/cmoc-manual.markdown`.
- **ToolShed** (`decb`, for building `.DSK` images) built from
  `https://github.com/nitros9project/toolshed.git` via `make -C build/unix`,
  then `decb` and `os9` copied by hand into `/opt/homebrew/bin` (no `sudo`).
  The `cocofuse` and `ToolShed.html` targets fail in that same `make` run
  (missing `fuse_t/fuse.h` and the `markdown` command respectively) — both are
  unrelated to `decb`/`os9` and safe to ignore; the unit tests
  (`librbftest`, `libdecbtest`, `libcecbtest`, `libtoolshedtest`,
  `os9commandtest`, `decbcommandtest`) all pass regardless.

## ROMs

XRoar needs `bas13.rom`, `extbas11.rom` (CoCo 2) and `coco3.rom` (CoCo 3) in
`~/.xroar/roms/` — these are copyrighted and not redistributed with this repo.
HDB-DOS's becker-port ROMs (`hdbdw3bck.rom` for CoCo 2, `hdbdw3bc3.rom` for
CoCo 3) live in `firmware/roms/` (gitignored) and also need copying into
`~/.xroar/roms/`.

### Banked images and `$FF40`

A 32K, 64K or 128K image loads as 2, 4 or 8 banks of 16K; a write to `$FF40`
selects the bank (bits 2-0). The switch takes effect one fetch late at both
CPU speeds: the instruction fetch right after `STA $FF40` still comes from
the old bank, every fetch after that from the new one (firmware
`docs/firmware-architecture.md` §3.2.4). So bank-switching code that runs
from the cart must keep the instruction after the `STA` identical in every
bank — put the switch routine's tail at the same address in each bank, the
usual practice for self-switching paks. Switching from RAM needs nothing.

## Emulate

```
cmake -B build-host -G Ninja -DPICOCO_HOST=ON firmware && ninja -C build-host
mkdir -p /tmp/picoco-pcdisk && cp coco/PICOCO.DSK /tmp/picoco-pcdisk/
build-host/picoco-host --dir /tmp/picoco-pcdisk --mount 0=PICOCO.DSK &
xroar -machine coco2bus -becker -rompath ~/.xroar/roms
```

At the `OK` prompt type `RUN"PICOCO"`. Expect `PICOCO HELLO` then `OK`.

For the CoCo 3 profile, add `-cart-rom hdbdw3bc3` (see below for why):

```
xroar -machine coco3 -cart-rom hdbdw3bc3 -becker -rompath ~/.xroar/roms
```

Same result: `RUN"PICOCO"` prints `PICOCO HELLO` then `OK`. (If a local
sandbox or firewall blocks `picoco-host` or XRoar's becker port from
listening/connecting on localhost, allow local TCP for this session or run
outside it — the exact mechanism depends on your environment.)

Notes on the exact flags, confirmed against this XRoar build (1.12.1):

- There is no cart profile literally named `hdbdos`. The predefined cart
  profile that does what we want is `becker` (`RS-DOS with becker port`,
  `-cart-type rsdos`, ROM list `rsdos_becker` = `hdbdw3bck`).
- **Neither machine needs an explicit `-cart becker`.** Both `coco2bus` and
  `coco3` already default to `machine-cart becker` at runtime (check with
  `xroar -machine coco3 -config-print | grep machine-cart`); the static
  `-machine help`/`-config-print-all` listing doesn't show this because it's
  a runtime default, not a property of the named machine profile itself.
  `-becker` (the boolean "prefer a becker-enabled DOS") is still worth
  passing explicitly for clarity, but isn't strictly required either.
- **CoCo 3 needs its ROM overridden.** The `becker` cart's ROM list
  (`rsdos_becker` = `hdbdw3bck`) is the *CoCo 2* HDB-DOS build regardless of
  which machine you select — nothing switches it automatically for `coco3`.
  Booting `-machine coco3` without an override runs the CoCo 2 ROM under
  CoCo 3 hardware: it happens to still work (boots, becker port answers,
  `RUN"PICOCO"` succeeds), but the banner misleadingly reads "HDB-DOS 1.5
  BECKER COCO 2" and "COLOR BASIC 1.1" on CoCo 3 hardware. Passing
  `-cart-rom hdbdw3bc3` (verified via `xroar -help` → `-cart-rom NAME`, "ROM
  image to load ($C000-)") overrides just the ROM image on whichever cart is
  currently selected (the auto-selected `becker` cart, no explicit `-cart`
  needed first) and correctly boots "COLOR BASIC 2.1" / "HDB-DOS 1.5 BECKER
  COCO 3".
- XRoar's becker port defaults to `127.0.0.1:65504` (`-becker-ip`,
  `-becker-port`), which matches `picoco-host`'s default port — no flags
  needed on either side for the default setup.
- `xroar -machine help` machine names used here: `coco2bus` (Tandy CoCo 2B,
  NTSC, T1 — the CoCo 2 profile) and `coco3` (Tandy CoCo 3).

## Headless XRoar recipe (for scripted/automated verification)

Later tasks need to drive the CoCo and read back the screen without a human
watching a window. Two pieces make that possible:

1. **Keyboard input at startup**: `-type STRING` intercepts ROM keyboard
   calls and types `STRING` into BASIC once it's ready to accept input — no
   window or focus needed. Use `\r` for ENTER, e.g.:
   ```
   xroar ... -type 'RUN"PICOCO"\r'
   ```
   This is a *startup* option only — there is no live "inject these keys into
   the already-running emulator" CLI command. XRoar's own escape table (from
   its texinfo manual, "Escape sequences") covers more than ENTER: `\b`
   (BS/LEFT), `\t` (HT/RIGHT), `\n` (LF/DOWN), `\r` (CR/ENTER), `\f`
   (FF/CLEAR), `\e` (ESC, mapped to BREAK on CoCo/Dragon), `\xHH` / `\uHHHH`
   for an arbitrary byte/codepoint. There's no dedicated UP escape in that
   table; on real CoCo BASIC the up-arrow key is the same code as `^`
   (ASCII 0x5E), so a literal `^` in the `-type` string should produce it —
   not independently verified in this session, sourced from the escape table
   and CoCo keyboard-code convention only. Since `-type` feeds ASCII
   characters (not raw key-down/up events), SHIFT+letter, digits, and
   punctuation just need the right character/case in the string; there's no
   separate "hold shift" step.

   **We could not find a way to send more keystrokes to an already-running
   instance**, including via the GDB stub: this XRoar's GDB target
   (`-gdb`/`-gdb-port`, see its manual's "GDB target" section) implements
   only the standard read-memory/registers/continue/interrupt subset used
   below, with no monitor/`qRcmd`-style custom command and no documented way
   to feed the keyboard through it.

   **Important discovered limitation**: once `xrscreen.py` (or anything
   using the GDB stub) has interrupted the CPU even once, any `-type` text
   still queued past that point reliably never gets typed — confirmed by
   comparing an interrupted run (stuck forever, even given 60+ real seconds)
   against the identical `-type` string left completely undisturbed (finishes
   normally in well under 20s). The safe pattern is: put **everything** the
   session needs typed into the one `-type` string given at launch (e.g. a
   whole numbered BASIC program plus `RUN`, since *storing* program lines
   takes no CPU time worth mentioning), and only start polling with
   `xrscreen.py` once nothing more needs to be typed — from then on you're
   just observing a program that runs and updates the screen on its own,
   which tolerates being repeatedly halted and resumed just fine.

2. **Headless video/audio + screen capture**: `-ui null -ao null` runs XRoar
   with no window and no audio backend (confirmed working on this build,
   1.12.1 macOS/SDL2 build) — no dummy display needed. Combined with `-gdb`
   (default port 65520), `coco/tools/xrscreen.py` (stdlib-only Python 3)
   connects to the GDB remote stub, reads $0400-$05FF (the 32x16 text screen)
   with a `$m400,200#xx` packet, and prints the decoded screen as 16 lines of
   32 characters.

   VDG decode: for each screen byte `b`, `c = b & 0x3F`; the character is
   `chr(c + 0x40)` if `c < 0x20` else `chr(c)`. Bit 6 clear means inverse
   video, marked here by lowercasing the character. Bit 7 set means
   semigraphics, printed as `#`. The blinking text cursor renders as a
   semigraphics block, so a trailing `#` on the last non-blank line is normal
   and just the cursor.

   **One `xrscreen.py` session per XRoar instance — this is not optional.**
   XRoar's GDB stub only tolerates one client connection per run: closing a
   connection (even a clean one that resumed the CPU first with `c`) and then
   opening a second, separate connection from a fresh process reliably hangs
   — the TCP connect succeeds but no reply ever arrives for the first command
   sent. So `xrscreen.py` does all its work — one screenshot, or polling for
   several strings in turn — on a single connection held open for the whole
   invocation, and every exit path (success, timeout, or error) resumes the
   CPU (`c`) before closing that one connection, leaving the emulator running
   for whatever comes next. Never invoke `xrscreen.py` a second time against
   the same still-running XRoar instance; if you need to watch for more than
   one thing, pass `--wait-for` more than once in the same invocation. Also
   note that while `xrscreen.py` is talking to the GDB stub the emulated CPU
   is halted (frozen, including its DriveWire traffic to `picoco-host`) —
   each poll cycle resumes it before sleeping, so it's only paused for brief
   moments, not for the whole invocation.

   Usage:
   ```
   python3 coco/tools/xrscreen.py [--host HOST] [--port PORT]
   python3 coco/tools/xrscreen.py --wait-for TEXT [--wait-for TEXT ...]
                                   [--timeout SECONDS] [--interval SECONDS]
   python3 coco/tools/xrscreen.py --selftest
   ```
   With no `--wait-for`, it connects, takes one screenshot, resumes, and
   prints it — defaults are `127.0.0.1:65520`. With one or more `--wait-for
   TEXT`, it polls (read / continue / sleep / interrupt / read again, all on
   the one connection) until each `TEXT` appears on screen in turn, printing
   the screen at each match, letting the machine keep running between
   matches; exits 0 if every target was found, 1 if any timed out (printing
   the last screen seen for that target first). `--connect-timeout` (default
   5s) retries the initial connect, since a fresh XRoar instance sometimes
   isn't listening on its GDB port for a couple of seconds after launch.
   `--selftest` runs internal checksum/decode asserts with no XRoar
   connection needed — useful as a quick sanity check after editing the
   script.

   Full worked example (CoCo 2, after `picoco-host` is up):
   ```
   xroar -machine coco2bus -becker -rompath ~/.xroar/roms \
         -ui null -ao null -gdb -gdb-port 65520 -type 'RUN"PICOCO"\r' &
   sleep 3
   python3 coco/tools/xrscreen.py
   ```
   Output:
   ```
   DISK EXTENDED COLOR BASIC 1.1
   COPYRIGHT (C) 1982 BY TANDY
   UNDER LICENSE FROM MICROSOFT

   HDB-DOS 1.5 BECKER COCO 2

   OK
   RUN"PICOCO"
   PICOCO HELLO
   OK
   #
   ```

   Worked example of `--wait-for`, watching a self-contained BASIC program
   (typed and `RUN` all in one `-type` string, per the limitation above) run
   two loops and print a distinct, non-literal marker after each — the final
   loop variable value (`PRINT I` after `FOR I=1 TO 2000`, so it prints
   `2001`, a value that doesn't appear anywhere in the source text, unlike a
   literal you `PRINT` yourself):
   ```
   xroar -machine coco2bus -becker -rompath ~/.xroar/roms \
         -ui null -ao null -gdb -gdb-port 65520 \
         -type '10 CLS\r20 FOR I=1 TO 2000:NEXT I\r30 PRINT I\r40 FOR I=1 TO 3000:NEXT I\r50 PRINT I\rRUN\r' &
   sleep 2
   python3 coco/tools/xrscreen.py --wait-for 2001 --wait-for 3001 --timeout 30 --interval 1
   ```
   Output (abridged to the two "found" screens):
   ```
   --- [1/2] wait-for '2001': found ---
    2001
   --- [2/2] wait-for '3001': found ---
    2001
    3001
   OK
   #
   ```
   This demonstrates polling more than once in a single session while the
   machine keeps running unattended, and the screen visibly changing between
   waits. (An earlier attempt at this used two separate top-level commands,
   e.g. `CLS:FOR...\rCLS:FOR...\r`, and hit exactly the limitation described
   above: the second command's text never got typed because the first
   `xrscreen.py` poll had already interrupted the CPU once.)

   Caveat: even with `-ui null -ao null`, XRoar's CPU is *not* dramatically
   faster than a real CoCo's — a 2000-iteration empty `FOR/NEXT` loop takes a
   few real seconds, similar to real hardware. (The near-100% CPU usage you
   see in `ps` while it's running is XRoar's pacing loop spinning, not a sign
   the emulation is running drastically faster than real time.) Size
   `--timeout` accordingly for whatever the target program actually does.

   Caveat: `-ui null` does not react to `SIGTERM` in testing here (it kept
   running); use `kill -9 <pid>` (or `pkill -9 -f 'xroar -machine'`) to stop
   headless instances started this way.

## Manager stub in XRoar

`picoco-host --ui` treats the whole TCP stream as a UI session (XRoar's Becker
cart forwards only `$FF41`/`$FF42`, so the stub's `$FF43` write never arrives).
Install the stub with `cp coco/stub/manager.rom ~/.xroar/roms/manager.rom`,
then (`D` = a scratch dir holding `CARTTEST.ROM` and `HDB.ROM`; add
`-ui null` to run headless). Launch each XRoar with `pkill -9 xroar` first: a
stale instance keeps the GDB port and `xrscreen.py` then hangs. Wait ~12 s
before `xrscreen.py` when `-type` has several keys.

1. No Extended BASIC (proves the first screen, the probe and the diff drawing;
   the highlighted row prints lowercase in `xrscreen.py`, it is inverse video):
   ```
   build-host/picoco-host --dir "$D" --port 65511 --ui &
   xroar -machine coco2bus -no-extbas -becker -becker-port 65511 -cart-rom manager \
         -no-cart-autorun -rompath ~/.xroar/roms -gdb -ao null -type 'EXEC 49154\r' &
   python3 coco/tools/xrscreen.py --wait-for 'PICOCO  32K NO ECB' --wait-for 'carttest.rom'
   ```
2. Keys and launch handshake (`-type 'EXEC 49154\r\n\r'` moves down to `HDB.ROM`
   and ENTER draws `NEEDS EXTENDED BASIC`; `-type 'EXEC 49154\r\r'` runs
   `rom launch CARTTEST.ROM` and the screen returns to the manager). Finding:
   XRoar's `-type` does deliver keys to the stub's `JSR [$A000]` (POLCAT).
3. Extended BASIC autostart (no typing; proves `DK` at `$C000` is found and
   `$C002` called, row 0 reads `32K ECB`):
   ```
   xroar -machine coco2bus -becker -becker-port 65511 -cart-rom manager \
         -rompath ~/.xroar/roms -gdb -ao null &
   python3 coco/tools/xrscreen.py --wait-for 'PICOCO  32K ECB'
   ```

4. CoCo 3 (autostart, no typing; `-machine coco3`, no `-no-cart-autorun`):
   ```
   xroar -machine coco3 -becker -becker-port 65511 -cart-rom manager \
         -rompath ~/.xroar/roms -gdb -ao null -ui null &
   python3 coco/tools/xrscreen.py --wait-for 'COCO 3'
   ```
   Row 0 reads `PICOCO  COCO 3 128K` (`-ram 128`; `512K`, `1M`, `2M` with `-ram 512`, `1024`, `2048`) and the two files are listed. XRoar
   cannot swap its cart ROM, so the `$16`/`$17`/`$18` leave paths are bench
   steps. `-type '\n\r'` (the `$17` restart) was tried but the stub's screen
   never changed (no BASIC prompt exists to take the keys), so that check is
   left to the bench.

   **Super ECB patches a `DK` cart.** On a CoCo 3, Super Extended BASIC copies
   the cart into RAM and patches the copy as if it were Disk BASIC (coco3.rom
   `$C321`): 3 bytes at `$C0D9` and 11 NOPs at `$C8B4`, or at `$C0C6` when the
   byte at `$C004` is `$D6`. The stub therefore keeps only a `jmp` at `$C002`,
   real code from `$C100`, and `coco/stub/Makefile` fails the build if those
   zones are not zero (before this, the patch landed mid-`POLL` and the first
   poll always failed with `PICOCO NOT RESPONDING`).

   Two harness traps: `picoco-host` exits when its stdin hits EOF, so run it
   as `(sleep 3000 | build-host/picoco-host --dir "$D" --port 65511 --ui &)`;
   and XRoar's GDB stub on `coco3` often never answers the first read (a
   timed-out client also uses up the single connection), so restart XRoar
   until `xrscreen.py` gets through.

## On the bench (real hardware)

1. Copy `PICOCO.DSK` to the PiCoCo's flash: `fs export`, drag it onto the
   `PICOCO` volume, `fs import` (see `firmware/README.md` "Export").
2. `dw mount 3 PICOCO.DSK`, then `save`.
3. Needs firmware 1.2 or later, and `becker native` (`becker native` then
   `save` if the board isn't already in that mode).
4. On the CoCo: `DRIVE 3:RUN"PICOCO"`. The `DRIVE 3:` prefix matters —
   the `PICOCO.BAS` loader `LOADM`s from BASIC's default drive.

## Using the manager

On startup the program runs `version` to check the link; if it times out,
it shows `PICOCO NOT RESPONDING` and `(BECKER NATIVE? FIRMWARE >= 1.2?)`,
then `R=RETRY  BREAK=EXIT` — press `R` to try again (e.g. after switching
the board to `becker native`) or `BREAK` to give up and return to BASIC.

Main screen keys:
- `0`-`3`: mount the selected image in that drive.
- `E` then `0`-`3`: eject that drive.
- `N`: prompt for a name (`.DSK` appended if there's no extension),
  `fs new` a blank image. Refused (with the firmware's error text) if the
  name already exists, is 32 characters or longer, is `picoco.cfg`, or
  holds a `/`, `\`, `:` or control byte.
- `B`: boot the selected image (see Boot below).
- `S`: settings screen.
- `V`: save (`save`) — persists mounts, next-boot ROM choice, and
  HDB-DOS drive mode.
- Up/Down arrows: move the selection; `SHIFT`+arrows: page up/down.
- `G` then a letter: jump to the first file name starting with that
  letter (`G`+letter again within a second narrows to the two-letter
  prefix, up to four). Letters are case-folded, so the bindings work in
  either keyboard mode.
- `BREAK`: exit to BASIC (warm start, no hardware reset). If anything
  changed since the last save, offers save-then-exit or stay.

The file list excludes `*.ROM` and `picoco.cfg`. If the firmware's reply
was too big to fit (its `...` truncation marker) or the flash holds more
than 128 matching files, the program shows `LIST TRUNCATED` once after
loading — not every file may be listed.

A CoCo reset after `V` (save) keeps the mounts; a reset without
saving drops them, since every `/RESET` reboots the Pico, which replays
`picoco.cfg` from scratch. `save` writes a `dw disk insert <n> <file>`
line for each read-write mount (so a name with spaces, e.g. "my
disk.dsk", survives the round trip — `dw mount` only takes one token) and
a `dw mount <n> <file> ro` line for each read-only mount.

### Settings screen (S)

- `R`: pick a `.ROM` file for the *next* boot (`rom boot`) — does not
  swap the ROM currently driving `/CTS`. Shows `SAVE, THEN RESET`
  afterward. Hides any `.ROM` file whose name contains a space, since
  `rom boot` takes a single token and couldn't be sent one.
- `Z`: timezone for SNTP (`+HH:MM`, `-HH`, or `OFF`), sent as `net tz <minutes>`.
  With a zone set, WiFi SNTP sets the clock on every update instead of only
  seeding a stopped one. The row shows `OFF` or e.g. `UTC-05:00`.
- `H`: toggle HDB-DOS drive-by-LSN addressing (`dw hdbdos on|off`).
- `T`: set the clock (`YYYY-MM-DD HH:MM`), converted to Unix seconds and
  sent as `time set`. Shows `(LOST AT RESET)` under the current time if
  the firmware reports `clock lost` (see
  `docs/superpowers/specs/2026-09-23-coco-manager-design.md` §4.5; the
  AON bench check is still pending).
- `W`: WiFi screen (below).
- `V`: save. `BREAK`: back to the main screen.

#### WiFi screen (W)

Rows: SSID, PSK (shown as `********` when set), SERVER, MODE (`NET` or
`NATIVE`), then the link STATE, IP and any error.

- `S`: scan and pick a network, then type its passphrase (empty for an
  open network).
- `P`: set the passphrase.
- `H`: server host, then port (empty keeps the default 65504).
- `M`: toggle the NEXT-BOOT DriveWire transport between net and native
  (`net mode` sets the boot mode only). The row shows `(SAVE, THEN RESET)`
  while it differs from the running mode. Press `V`, then reset. Leaving
  net mode live is a USB-console action (`becker native`).
- Entries (SSID, PSK, host) run over two rows, about 57 characters.
- `V`: save. Settings do not survive a reset until saved.
- `BREAK`: back.

`SHIFT+0` toggles lowercase, which SSIDs and passphrases need. On a
Pico 2 board (`net radio no`) the screen shows `NO RADIO ON THIS BOARD` and returns.

### Boot (B)

1. Mounts the selected image to drive 0.
2. Reads track 34 sector 1 (LSN 612).
3. If it starts with `OS`: loads all 18 sectors of track 34 to
   $2600-$37FF and jumps to $2602, as Disk BASIC's `DOS` command does
   (OS-9 boot; not exercised in XRoar — no Becker OS-9 boot disk
   available there — so this path is bench-only).
4. Otherwise: reads the RS-DOS directory (track 17, sectors 3-11), lists
   the `.BAS`/`.BIN` entries, and hands the picked one to BASIC as
   `DRIVE0:RUN"NAME"` or `DRIVE0:LOADM"NAME":EXEC`. Always `DRIVE0:`:
   the booted image is in drive 0, but the manager itself may have been
   launched from another drive (step 4 of "On the bench" above uses
   drive 3), which would otherwise be BASIC's default drive for the
   handoff command.

## Memory layout

- The 2-line `PICOCO.BAS` loader sits at $2601: line 10
  (`CLEAR200:IF PEEK(65534)=140 THEN WIDTH32`) pins string space to 200
  bytes and sets 32-column mode on a CoCo 3,
  line 20 (`LOADM"PICOCO":EXEC`) loads and runs the program.
- The `fs ls` reply buffer (`LSBUF`, 3096 bytes: a 23-byte `OK` header
  plus a 3072-byte body plus a NUL) lives at a fixed $2700-$3317 instead
  of BSS, between the loader and the program. The firmware's `...`
  marker is lost for bodies of 3073-4096 bytes (roughly 100 files at
  30-char names); `ls_cut` drops the cut last line and the list shows
  `LIST TRUNCATED` whenever the buffer fills. Right after it, in the same window, sit `files[]`
  (128 entries x 4 bytes, $3318-$3517) and the command reply buffer
  (736 bytes, $3518-$37F7). All three share one lifetime: they are dead
  by the time boot.c overwrites the window. `ui_run()` refuses to start
  (`BASIC PROGRAM TOO BIG`) if BASIC's array-end pointer (`ARYEND`,
  $001F) already reaches past $2700.
- `PICOCO.BIN` loads at $3800 (`ORG` in `coco/Makefile`) and must end
  below $7B80; the Makefile passes `--limit=7B80`, so an overrun fails the
  build. The loader's `CLEAR 200` pins BASIC's string space to the top 200
  bytes, leaving about 0.9 KB of stack above the program. Current end:
  $7B80. (The $7A00 target did not fit once the timezone row landed.)
- OS-9 boot (track 34 -> $2600-$37FF) and the `RUN"X"`/`LOADM"X"`
  handoff both overwrite $2700-$37FF, but only after the picked file's
  name has already been copied out of `LSBUF`, so the overlap is safe.

## Developer notes

- **CMOC 0.1.100 miscompiles `!func(...)` used as a value** (verified
  on-device): `if (!f())` is fine, but assigning the negation of a
  direct function-call result (e.g. `keep = !ends_with_ci(...)`) is not.
  Write `f() == 0` instead. See the `ponytail:` comment in
  `coco/parse.c`'s `parse_ls`.
- **`cls` clashes with CMOC's `coco.h`**, which already declares one;
  this program's screen-clear function is named `clear_screen` instead.
- Keep using the headless XRoar recipe above for anything that doesn't
  need real hardware. `picoco-host` doesn't exercise the OS-9 boot
  branch or go past what the RVEC4 handoff spike already covers — see
  `docs/superpowers/specs/2026-09-23-coco-manager-design.md` §5.5, which
  passed in XRoar on both the CoCo 2 and CoCo 3 profiles.

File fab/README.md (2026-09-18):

# PiCoCo — Fab Outputs

This directory holds the machine-generated outputs used to order PCBs
from a board house. All artifacts here are produced by
`tools/gen_fab.sh` from the KiCad project in `../PiCoCo/`.

## Regeneration

```bash
bash tools/gen_fab.sh
```

Main board outputs land in `main/` (breakout/cobbler boards keep their
own `breakout/` and `cobbler/` subdirectories). Produces, under `main/`:

- `PiCoCo-*.gbr`/`.gtl`/`.gbl`/etc. — one Gerber per copper/silk/mask layer.
- `PiCoCo-*.drl` — Excellon drill file.
- `PiCoCo-pos.csv` — full pick-and-place (position) file.
- `PiCoCo-gerbers.zip` — zipped Gerbers + drill, ready to upload.
- `PiCoCo-BOM-jlc.csv` / `PiCoCo-CPL-jlc.csv` — JLCPCB assembly BOM and
  CPL (DNP parts and non-BOM footprints excluded).
- `stencil-module/PiCoCo-stencil-module-F_Paste.gbr` — standalone paste
  stencil for U1's 15 hidden grid pads only (Plus-W builds). The 40
  castellation apertures sit over plated holes and paste falls through
  them, so hand-solder the castellations regardless of module.

DRC is **not** run by the script because `kicad-cli pcb drc` crashes
on the current macOS build with a Swift runtime error. Run DRC in the
KiCad GUI before ordering: `Inspect → Design Rule Checker`.

## Ordering

See `main/READ-BEFORE-ORDERING.txt` for the JLCPCB order-form checklist.
The hard-gold finger / 30° bevel / 1 µm plating settings are not
optional — ignoring them will damage the CoCo slot on the first
insertion.

## Zipping for upload

`tools/gen_fab.sh` zips the Gerbers + drill into `main/PiCoCo-gerbers.zip`
automatically. The BOM/CPL CSVs and the module stencil are uploaded
separately for assembly services.

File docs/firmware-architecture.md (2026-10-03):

# PiCoCo — Firmware Architecture

Raspberry Pi Pico 2 (RP2350) firmware that turns the PiCoCo board
into a combined **ROM emulator** and **DriveWire Becker‑port
peripheral**.

This document explains how the firmware is structured. For the
hardware it runs on, see [`hardware-design.md`](hardware-design.md).

---

## 1. Goals

1. Respond to every `/CTS` read cycle (the $C000–$FEFF window; `rom.c`
   serves an 8 KB or 16 KB image, or a banked one, out of idx
   `0x0000-0x3EFF` of it) in ≤ 1 bus cycle — data on D0–D7 before E falls.
2. Respond to Becker‑port reads on $FF41 (status) and $FF42 (data),
   and accept Becker‑port writes to $FF42 (data), implementing the
   DriveWire protocol.
3. Never drive the data bus when the cart is not selected — enforced
   by U15, a 74LVC00 wired NAND-NAND (`OE_BUS` low only while `/CTS` or
   `/SCS` is low and E is high), which enables U10. The engine never
   re-checks the select; it drives only inside an `OE_BUS`-low cycle.
4. Hold the CoCo's `/HALT` low during Pico boot until the PIO
   state machines are armed, so the CoCo's first HDB‑DOS `DOS`
   command can't race the Pico.
5. Keep the ARM cores free of per‑bus‑cycle work: PIO + DMA handle
   the bus, ARM handles DriveWire state and USB/UART diagnostics.

## 2. Toolchain

- **SDK**: Raspberry Pi Pico SDK ≥ 2.1.0 (Pico 2 support).
- **Compiler**: `arm-none-eabi-gcc` ≥ 13.
- **Build**: CMake + Ninja.
- **Flash**: UF2 over BOOTSEL (`bootsel` on the console), or
  `picotool load -x`. The board has no SWD header.
- **Language**: C11 throughout, the DriveWire protocol layer included.

Repo layout. `host/` and the platform-independent parts of `src/` are
covered by `ctest` (14 suites):

```
firmware/
├── CMakeLists.txt          # -DPICOCO_HOST=ON builds host lib + tests + picoco-host
├── pico_sdk_import.cmake
├── boards/                 # pico2_breadboard.h (Pico 2), plusw.h + picoco_plusw.h (Plus-W)
├── ld/                     # linker additions: bus_events + bus_mem region (section 5.1)
├── src/
│   ├── main.c              # Pico target: init, /HALT release, main loop
│   ├── plat.h              # platform functions, resolved at link time
│   ├── plat_pico.c         # RP2350 implementation of plat.h
│   ├── ring.h              # SPSC byte ring, shared by bus and becker
│   ├── log.h / log.c       # ring-buffered leveled logging
│   ├── bus/
│   │   ├── bus.h / bus.c   # response table, write ring, read hooks, trace ring, stats
│   │   ├── bus_engine.pio / bus_engine.c   # PIO + DMA bus engine (section 3.3)
│   │   ├── bus_core1.c     # core1 event loop (section 3.4)
│   │   └── fake6809.pio / fake6809.c       # `bus selftest` (section 3.2.5)
│   ├── dev/
│   │   ├── device.h / device.c   # device registry, write-event dispatch
│   │   ├── rom.h / rom.c         # ROM device
│   │   └── becker.h / becker.c   # Becker port device
│   ├── dw/
│   │   ├── dw_util.h / dw_util.c       # checksum, LSN pack/unpack
│   │   ├── dw_store.h                  # storage ops struct
│   │   ├── dw_store_posix.c            # host implementation (also used by picoco-host)
│   │   ├── dw_store_fatfs.c            # Pico implementation (flash FAT volume)
│   │   ├── dw_disk.h / dw_disk.c       # image format detection, LSN mapping
│   │   ├── dw_vser.h / dw_vser.c       # virtual-serial command channel (section 7.3)
│   │   └── dw.h / dw_server.c          # DriveWire protocol state machine
│   ├── console/
│   │   ├── console.h / console.c  # line parser + commands
│   │   └── mode.h / mode.c        # mode switch (diag/loop/bridge/native/net) + pump
│   ├── net/                # WiFi transport, Plus-W only; net_stub.c elsewhere (section 7.3.1)
│   ├── ui/                 # ROM manager screens; manager_rom.h is the built-in stub
│   ├── fs_flash.c          # FatFS diskio over the flash partition; USB MSC glue
│   ├── crash.c             # hard fault + panic record in noinit RAM
│   └── usb/                # usb_descriptors.c, tusb_config.h
├── host/
│   ├── plat_host.c         # POSIX implementation of plat.h
│   ├── picoco_host.c       # TCP 65504 server + stdin console around dw_server
│   └── sim_bus.h / sim_bus.c   # virtual CoCo for host-side tests
├── tests/
│   ├── test.h              # ~30-line TEST/ASSERT macros
│   ├── test_*.c            # one file per module
│   └── fixtures/           # synthetic images, captured byte streams, trace dumps
├── tools/
│   ├── dwtest.py           # DriveWire client exerciser (TCP)
│   ├── tracedump.py        # decodes `trace dump` output
│   └── ...                 # check_core1_flash_free.py, bench.py, pconsole.py, flash.sh,
│                           # becker_relay.py, eou_becker.py (see firmware/README.md)
└── roms/                   # user-supplied ROM images, gitignored
```

## 3. Runtime architecture

### 3.1 Core split

Reversed from the original proposal: the bus service is the
time-critical job, so it gets its own core with nothing else running
on it.

- **core1** — the bus event loop only (`src/bus/bus_core1.c`).
  Flash-free: never executes from or reads flash, runs with interrupts
  disabled from SRAM (`BUS_HOT` section attribute), so the build sets
  `PICO_FLASH_ASSUME_CORE1_SAFE` (`firmware/CMakeLists.txt`; not
  `PICOCO_FLASH_ASSUME_CORE1_SAFE` — that name never existed in the
  build). Reads are served by PIO and DMA with no CPU in the path
  (section 3.3); core1 walks the event ring after each cycle, runs the
  hooks and pushes write events into the write ring (section 3.4).
- **core0** — everything else: USB (2x CDC + MSC), the console, the
  DriveWire server, storage (flash/FatFS or the host POSIX
  equivalent), and device write dispatch (`device_dispatch_writes()`
  in `mode_pump()`). Core0 is free to touch flash; core1 never is.

Communication is the response table, write ring and read hooks in
`src/bus/bus.h` (SPSC, no locks) — not the Pico SDK `queue_t` mentioned
in the original proposal. The one lock is the engine's spin lock
(`elock`, `bus_engine_lock()`), which serialises bank switches, `rom
load`'s unbank/publish and the engine's start/stop.

### 3.2 Pin map (Pico 2 header numbering)

| GPIO | Header pin | Role |
|---|---|---|
| GP0–GP7 | 1,2,4,5,6,7,9,10 | D0–D7 (bidi via U10) |
| GP8–GP21  | 11,12,14–27 | A0–A13 (input from U11+U12) |
| GP22 | 29 | /R/W (input from U12; also drives U10 DIR) |
| GP26 | 31 | **OE_BUS** — cart‑selected (U15 output) |
| GP27 | 32 | **HALT_GATE** — output; drives Q2 → /HALT |
| GP28 | 34 | AUDIO_PWM by default (JP3 1-2, v2.3.1); E (input from U13) if JP3 is cut to 2-3. Firmware does not initialise this pin (no sound firmware yet, `docs/ADDITIONAL_ROADMAP.md` §5 item 4) — neither driven nor pulled. |
| RUN | 30 | CoCo /RESET (via R9 series; R10 pull‑up footprint is DNP by default) |
| VSYS | 39 | +5V via D2 Schottky |

`OE_BUS` is asserted whenever the cart is selected — i.e., whenever
`/CTS` OR `/SCS` is low AND the E clock is high (E qualifies the
address‑valid window). Firmware disambiguates by **A13**:

- `OE_BUS` low with `A13=0` ⇒ ROM read in the full $C000–$FEFF `/CTS`
  window (`rom.c` covers idx `0x0000-0x3EFF`).
- `OE_BUS` low with `A13=1` ⇒ Becker access in $FF40–$FF5F window.

### 3.2.1 Plus-W pin plan (board v2.3, implemented)

The v2.3 board (`docs/superpowers/specs/2026-09-17-main-board-v2.3-design.md`
§3.2) adds 15 hidden underside pads to the `PiCoCo:Pico-Carrier`
footprint, wired only when a Waveshare RP2350B-Plus-W is soldered flat
instead of a Pico 2 — NC on a Pico 2 build. `firmware/boards/plusw.h`
(select with `-DPICOCO_BOARD=plusw`) implements this table. OE_BUS is
GP40 on this board, outside PIO0's GPIO window, so the bus engine watches
it from a helper state machine in PIO2 (section 3.2.2), and `main.c`'s
`gpio_setup()` inits exactly the pins below plus D0-7/A0-13//R/W/OE_BUS,
from a board-header pin mask. Of GP24-GP30 the engine reads only GP26
(E), the Plus-W event state machine's end-of-cycle pin.

Header pins 31/32/34 carry the same nets on both modules, but the
GPIO number differs: on a Pico 2 those pins are `GP26`/`GP27`/`GP28`;
on a Plus-W the same physical header pins are `GP40`/`GP41`/`GP42`.
`E_BUF` also arrives separately on the Plus-W's own pad-grid `GP26` pin
(a different, lower-numbered GPIO than the header's GP40) — see the
"same net also reaches..." note in the table below.

| Pad-grid pin | Net | Purpose (Plus-W only) |
|---|---|---|
| GP24 | CTS_BUF | capture |
| GP25 | SCS_BUF | capture |
| GP26 | E_BUF | capture (also reaches the module's header pin 34 only if JP3 is cut to 2-3 — header pin 34 carries AUDIO_PWM by default as of v2.3.1; GP40/41/42 mapping: header 31/32/34 = GP40/41/42) |
| GP27 | Q_BUF | capture |
| GP28 | SLENB_BUF | capture |
| GP29 | A14_BUF | capture |
| GP30 | A15_BUF | capture |
| GP31 | OE_FW | Firmware U10 `/OE`, reached only with JP2 at 2-3. The PIO engine holds it high, so **JP2 must stay at 1-2** (hardware `/OE`) until the respin (`docs/ADDITIONAL_ROADMAP.md` §8) |
| GP32 | NMI_DRV | Q3 gate (DNP stage — R15/R17 also DNP); also reachable from a Pico 2 via JP5 2-3 (shares header pin 34, see below); no firmware drives this pin yet |
| GP33 | CART_DRV | Firmware-driven `/CART` pulse (bus-engine spec, §4.5-equivalent in `main.c`): toggled ~500 Hz for 500 ms after `/HALT` release when `rom_cart_wanted()` is true; also reachable from a Pico 2 via JP5 1-2, but no Pico 2 board header defines `PIN_CART_DRV` today, so the pulse is Plus-W only |
| GP34 | AUDIO_PWM | sound output stage |
| GP35 | EXP_GP35 → J1 pin 1 | Plus-W only; on a Pico 2 this is where the module's own SWDIO pad lands instead (see the debug-pad note in `hardware-design.md` §7) |
| GP43, GP44, GP45 | EXP_GP43/44/45 → J1 pins 2-4 | Plus-W only |

GP24..GP30 are contiguous, but A14/A15 (GP29/GP30) are not next to
A13 (GP21), so one PIO `in pins` cannot take A0-A15. The engine uses
A0-A13 on both boards: no 32K paks and no `$8000` window until the
respin.

**JP5** (`docs/hardware-design.md` §4.4a) is the header-pin-34 solder
jumper for the Q3/Q4 drive stages above: pad 1 = `CART_DRV`, pad 2 =
`PICO_P34` (module header pin 34), pad 3 = `NMI_DRV`. Open by default,
and mutually exclusive with JP3 (both bridge onto header pin 34) — a
Pico 2 build picks at most one of audio (JP3), a firmware `/CART` pulse
(JP5 1-2), or a firmware `/NMI` drive (JP5 2-3, needs R15/R17 fitted).
No firmware for either JP5 position exists yet (item 5 of the firmware
backlog, `docs/ADDITIONAL_ROADMAP.md` §5).

**Plus-W board header trap, avoided:** `PICO_DEFAULT_LED_PIN` is `GP25` on
a Pico 2. On a Plus-W, pad-grid `GP25` is `SCS_BUF` — a U13 **output**,
not an LED. The Plus-W has two user LEDs: LED1 on the radio's `WL_GPIO0`
(needs the CYW43 driver) and LED2 on `GP23`, which the module does not bring
out. `firmware/boards/plusw.h` uses LED2 (`PIN_LED 23`). The radio itself
uses GP36-GP39 (REG_ON, DATA/IRQ, CS, CLK), clear of the pad grid,
verified 2026-09-29 from the Waveshare schematic and a live scan
(`firmware/README.md` "WiFi").

### 3.2.2 Plus-W differences

Both state machines sit in PIO0 (GPIO base 0), as on a Pico 2. The read
program is the same, with its three waits patched at load (§4.1); the
event state machine runs its own program, `bus_event_pw` (§4.2), which
starts on helper flag 1 and ends when E falls. OE_BUS (GP40) is outside PIO0's window, so a helper, `bus_sel_pw`
(section 4.3), runs in PIO2 with GPIO base 16. The cyw43 driver puts its
own state machine in PIO2 sm0 and sets that base; `bus_engine_init()`
runs after `net_init()` and sets the base itself only if the driver has
not. On OE_BUS low the helper raises PIO0 flag 0 (read SM: cycle start)
and flag 1 (event SM) with `irq next set`; on OE_BUS high, flag 2 (read
SM: cycle end). PIO2's "next" block is PIO0, which is why the helper must
stay in PIO2. It adds about 3 clk to the read path.

The helper runs from `bus_engine_init()` on and is never stopped, by
`bus drive off` or by a restart, so the event SM never misses a cycle.
While the read SM is stopped, flags 0 and 2 pile up unread. `engine_start`
clears them only between cycles: it waits for OE_BUS (read through SIO)
to be high for 16 clk, clears flags 0 and 2, reads the IRQ register back
so the clear has landed, and checks OE_BUS is still high, else it goes
round again. A start flag cleared while its end flag is still to come
would leave that end flag pending and release every later read at once.
The wait is capped at 64 passes (about 3 µs). At the cap it counts
`start_wait_cap` and leaves the read SM stopped; `bus_engine_tick`
retries the start on its next millisecond while `bus drive` is on.

The radio holds DMA channels 0-1; the engine claims its channels and state
machines through the SDK allocators, never by number (`bus engine` prints
who holds what). Until the respin (`docs/ADDITIONAL_ROADMAP.md` §8) a
Plus-W has the Pico 2's limits: `OE_FW` (GP31) is held high and JP2 must
be at 1-2, A14/A15 are not used, and there are no firmware-decoded
addresses (`$FF60-$FF7F` went with the CPU loop, tag `fw-1.4-cpu-loop`).

### 3.2.3 Write hooks

```c
int bus_add_write_hook(uint16_t idx, void (*fn)(uint8_t data));  /* 0 ok, -1 full */
```

Same shape as the existing read-hook table (`bus_add_read_hook`):
`BUS_MAX_HOOKS` (4) fixed entries, matched by `idx` with a linear scan —
cheap at four entries, no map needed. core1 calls the matching hook from
`bus_event()` when the write's event arrives, after the cycle, as the
first thing it does with it: before the trace store, the counters and
the core0-facing write ring. The `$FF40` bank hook races the next
cycle's `in x, 3` (section 3.2.4), so nothing goes in front of it, and
core0 sees a hook's effect no later than the write itself. core0 still
sees every write; the hook is an early look, not a replacement for the
queued event. `bus whooks` in `status` counts hook invocations. Hooks
are `BUS_HOT` — SRAM-resident, no libc, no flash — the same rule core1's
own loop follows.
`firmware/tools/check_core1_flash_free.py` discovers hook functions by
grepping for `bus_add_(read|write)_hook(...)` call sites (one regex
covers both), so a write hook that branches into flash fails the Pico
build the same way a read hook or the core1 loop itself would.

### 3.2.4 Table and banked ROM

The engine serves `bus_mem[8][16384]` (`bus.h`): eight 16 KB banks in one
128 KB-aligned block, in its own linker region at `0x20060000`
(`firmware/ld/`, section 5.1). Bank 0 is `bus_table`. The read SM builds
the address of the byte as `Y << 17 | X << 14 | A13..A0`, `Y` being
`&bus_mem >> 17` and `X` the bank (section 3.3), so a bank switch is one
register update. The I/O page (`$FF00-$FFFF`, idx `0x3F00-0x3FFF`) comes
from the current bank too. The entries devices own, `0x3F40-0x3F5F`, are
written only through `bus_io_set()`, which stores into all eight banks, so
a device read never changes with the bank; ROM loaders leave them alone.
`bus_peek(idx)` returns `bus_mem[bus_bank][idx]`.

`rom.c` loads three shapes:

- **8192 or 16384 bytes**: unbanked, into bank 0 (the 16 KB case skips
  `0x3F40-0x3F5F`, per the single-writer rule in §6.3).
- **32768, 65536 or 131072 bytes** (2/4/8 x 16 KB, the largest Games
  Master Cartridge size MAME's `coco_gmc` supports): banked, straight into
  banks 0..n-1 of `bus_mem`. `unbank()` (count 0, bank 0) runs first, so
  the `$FF40` hook is inert while banks fill; `rom_publish_banks()` then
  sets bank 0, the mask and the count in one step. Both take the engine
  lock that the hook takes, so a switch racing the loader sees "unbanked"
  or "fully loaded", never a half-filled table.
- Any other size is refused with `-2` and the previous ROM stays loaded;
  the console prints `rom load: size must be 8K, 16K, or banked 32K/64K/128K`.

`rom_init()` registers a `$FF40` write hook (`rom_bank_hook`) once, for
the life of the firmware; it is a no-op while no banks are loaded. On a
write it takes the engine lock and calls `bus_engine_set_bank_locked(data
& mask)`, which stores `bus_bank` and execs `set x, n` into the read SM.
No pause, no PC read, no jump: an exec'd instruction runs at an
instruction boundary, a state machine stalled in a `wait` or `pull` runs
it and stays stalled, a running one loses 1 clk. The read program takes
the bank (`in x, 3`) right after its start trigger, so a switch takes
effect for every cycle whose `in x, 3` has not yet run.

The hook lands 82-93 clk after the write's OE_BUS rises, which is after
the next cycle's `in x, 3` at both speeds. So the first cart fetch after
a `STA $FF40` comes from the old bank and every later one from the new:
`+1` on 512 of 512 switches at both speeds in the self-test. On a Plus-W
at 0.89 MHz the hook sits on the boundary and 1-95 of 512 switches land
at `+0`. No read is ever served from a wrong address. The later fix, if a
real pak needs it, is a PIO decode of `$FF40`
(`docs/ADDITIONAL_ROADMAP.md` §5 item 7).

`rom_is_dos()` (loaded and the first two bytes are `DK`) feeds
`rom_cart_wanted()`'s AUTO mode (the `/CART` pulse in `main.c`).

### 3.2.5 Self-test: fake 6809

`bus selftest` (`firmware/src/bus/fake6809.c`, PIO program in
`fake6809.pio`) runs the real engine, event loop and hooks against
synthetic 6809 bus cycles generated by a PIO1 state machine, clk-exact
(84 clk per cycle at 1.79 MHz, 168 at 0.89 MHz), so the bus path can be
exercised with no CoCo attached. It is the engine's regression gate.

**Unplug the board from the CoCo before running this — the guard below is
a backstop, not a licence to leave it plugged in.** Before touching a
single pin, it samples `bus_stats.cycles`, sleeps 100 ms, and re-checks
it: if the count moved, a CoCo is actually driving the bus, and the test
refuses immediately (`-2`, "bus is live (CoCo attached), refused"). That
check alone misses an idle CoCo: one running from RAM produces no cart
cycles at all, so the count never moves even with the board live. A
second guard covers that case: for 10 ms, sampled every 50 µs, the
address and `R/W` pins (plus `OE_BUS` on a Pico 2, or `E`/`Q` on a
Plus-W) must not move at all — those pins come through always-enabled
buffers and toggle with the CPU clock whenever anything is running them,
where an unplugged board just sits on its pull-ups. Only after both
checks pass does it hand the address/control pins to PIO1 (and back to
SIO when it is done). Write data comes from a test-only state machine in
PIO0, since D0-D7 belong to the engine. `firmware/tools/bench.py`
(below) is registered as the `bench` ctest target only when configured
with `-DPICOCO_BENCH=ON` — it is opt-in, not part of the default `ctest
--test-dir build-host` run, because it drives real bus pins.

On a Pico 2 the fake drives A0-A13 and R/W with `OE_BUS` as a side-set.
A bare Plus-W has no decode chip, so the fake drives E and the selects
and a fake decode generates `OE_BUS`; its own delay (5 clk, against about
1.5 for the real 74LVC00) is measured and taken out (`corrected`).

What it checks, in one run of about 2 s: 4,096-cycle back-to-back bursts
at the realistic sample point (36 clk after OE_BUS falls at 1.79 MHz,
72 at 0.89 MHz), mixed reads and writes, unselected gaps, write capture
with data, event content and rate, engine restarts under a burst, a lap
of the event ring, a forced stall, bank switches at random phases,
capture-only (`bus drive off`), all eight banks, the I/O page across
banks, a Becker byte stream at both speeds, Becker status and data on
consecutive cycles, where a `$FF40` switch first shows, sample-point
sweeps (`response_clk`), the release (`release_clk`), and on a Plus-W
late `/CTS` and `/SCS`. Options: `stress` (core0 memcpy load), `radio`
(Plus-W: scans and cyw43 polling), `restarts` (40 restart bursts, then
stop), `switches` (40 switch bursts with a phase histogram, then stop).
It prints `selftest fast pass` only if every gated line passed; the
expected lines per board are in `firmware/README.md` and
`firmware/TEST_PLAN.md` section K.

By design it should be safe on a PCB powered from USB alone: with no cart
+5 V present the board's +3.3 V rail (an LDO off +5 V) is off, so
U10/U11/U12/U13/U15's outputs sit in their unpowered high-impedance state
(LVC "partial-power-down" `Ioff`) and cannot drive against the PIO. That
has never been run; until someone checks it on a scope, run the self-test
on a bare module only, and never with a CoCo attached (the engine would
drive into a live bus). On success (or failure) it calls `rom_off()` and
prints `selftest rom cleared; reload with rom load` — the synthetic image
does not survive a run either way, which is why `firmware/tools/bench.py`
sends `reboot` at the end of its own run, to replay a saved `rom load`
from `picoco.cfg`. With +5 V on the board (a bench supply or a CoCo),
U11-U13 are powered and their outputs would fight PIO1; the measured
figures in section 8 all come from bare modules.

### 3.3 Bus engine: the read path

Reads are served by PIO and DMA alone (`bus_engine.pio`, `bus_engine.c`):
no CPU sits between OE_BUS falling and the byte on D0-D7, on either
board. The CPU loop of firmware 1.4 is tagged `fw-1.4-cpu-loop`; there is
no build switch back to it. Design spec:
`docs/superpowers/specs/2026-10-02-pio-bus-engine-design.md`.

| Resource | Pico 2 | Plus-W | Role |
|---|---|---|---|
| PIO0 sm0 | read | read | serves the byte (section 4.1) |
| PIO0 sm1 | event | event | one word per selected cycle (section 4.2) |
| PIO2 sm1 | — | helper | watches OE_BUS on GP40 (section 4.3) |
| DMA A | ch 0 | ch 2 | read SM RX (the pointer) → DMA B `READ_ADDR_TRIG`; 32-bit, endless |
| DMA B | ch 1 | ch 3 | that one byte → read SM TX; 8-bit, count 1, re-armed by every A write |
| DMA C | ch 2 | ch 4 | event SM RX → `bus_events`; 32-bit, endless, 8 KB write ring |

The numbers are what `bus engine` printed on the bench modules; every
state machine and channel comes from the SDK allocators. All three DMA
channels are high priority and DMA has bus priority (reads and writes).
Input synchronisers are bypassed on A0-A13 and R/W only; OE_BUS (an
asynchronous strobe) and D0-D7 keep theirs.

**Per read.** On the start trigger the read SM tests R/W (`jmp pin`); a
write is never driven. For a read it shifts the bank (`in x, 3`) and
A0-A13 (`in pins, 14`) into an ISR that already holds `Y`, so the ISR is
the address of the byte, `Y << 17 | X << 14 | A13..A0` (section 3.2.4).
`push noblock` hands it to DMA A, which writes it into DMA B's trigger
register; B copies the byte into the TX FIFO. An 8-bit DMA write reaches
the FIFO replicated across the word (measured), so `out pins, 8` takes the
right byte. The SM sets the output latch and only then enables the
outputs (`mov pindirs, ~null`): a stalled DMA leaves the pins released,
never driving. At the end of the cycle it drives D0-D7 low for 2 clk and
then releases them (RP2350-E9: a pad left high on the pull-down alone
stays high).

Every instruction between the start wait and `push`, or between `pull`
and `mov pindirs`, costs 1 clk of read latency; `in x, 3` is the one
added beyond the minimum (it costs every read 1 clk and saves a bank
switch from touching the program counter). Change either stretch only
with a self-test run on both boards.

**Start and stop.** `engine_stop` and `engine_start` run from SRAM: from
flash, a cache miss once left the pins driven for two cycles. `engine_stop`
runs whole with interrupts off, under the engine's spin lock;
`engine_start` takes the lock only from the `X` load on. Its drain, FIFO
clear, restart and `Y` load run with interrupts on and no lock, which is
harmless because the read SM is stopped. Stop disables the read SM and
execs `mov pins, null` then `mov pindirs, null`. Start waits until the
read SM's RX FIFO is empty and DMA B is idle (a pointer still in flight
would land after the FIFO clear and serve every later read one cycle
late), clears the FIFOs, restarts the SM, loads `Y`, jumps to `top`, sets
`X` to `bus_bank` under the lock, runs the Plus-W flag sequence (section
3.2.2) and enables.

**Capture-only (`bus drive off`).** Only the read SM stops, its pins
discharged and released. The event SM, DMA C and the Plus-W helper keep
running, so writes, the trace and every event still arrive. `bus drive
on` stops and restarts the read path.

**Stall guard.** `bus_engine_tick` runs in core0's main loop once a
millisecond and checks five things: the read SM is enabled, its PC is at
`pull`, DMA B is idle, OE_BUS is high, and the read SM's RX FIFO is
empty. Seen on two ticks in a row, it runs `engine_stop` and
`engine_start` and counts `engine_stall`. A served read also waits at
`pull` with B idle (12-20 % of samples under a reads burst), so without
the OE_BUS term a busy bus restarted the engine on a few per cent of tick
pairs. Detection takes 1-2 ms on an idle bus and about 6 ticks with
OE_BUS cycling, bounded in practice but not hard-bounded. Because the
outputs are enabled only after the pull, a stall means "not answering",
never "driving". The guard covers a lost pointer; a dead DMA A is not
covered.

### 3.4 Event stream and the core1 loop

The event SM samples D0-D7, A0-A13 and R/W (23 pins from GP0) from the
same trigger as the read path (Pico 2: OE_BUS low; Plus-W: flag 1) until
the cycle ends, keeps the last sample taken while the cycle was still on,
and pushes that one word: `[7:0]` data (on a read, what the engine
drove), `[21:8]` index, `[22]` R/W (1 = read), `[31:23]` always 0. Its RX
FIFO is joined (8 deep) and the push is `noblock`: a push into a full
FIFO drops the event and sets `FDEBUG.RXSTALL`, which core0 counts as
`event_drop` on each 1 ms tick. DMA C drains it into `bus_events[2048]`,
whose write address wraps. The event SM and DMA C start once in
`engine_init` and never stop, so DMA C's position and core1's index stay
in step.

core1 (`bus_core1_main`, SRAM, interrupts off) walks the ring by a
sentinel: every empty slot holds `BUS_EV_NONE` (`0xFFFFFFFF`), which no
selected cycle can produce (bits 23-31 read 0, and it would be index
`0x3FFF`, never selected). It reads its next slot until it is not the
sentinel, writes the sentinel back and calls `bus_event(w)`. It never
reads a DMA register per event: a core reading DMA registers back to back
delays DMA A by 1 clk now and then.

`bus_event()` is also what the host simulator calls, so the host tests run
the same hook and queue code. A write runs its hooks first, then the
trace store, the counters and the write ring; a read runs the trace
store, the counters, then its read hook (Becker status and data). The
read path is kept separate and short on purpose: at 1.79 MHz with every
cycle from the cart there are 84 clk per event, and estimates from the
disassembly put a ROM fetch event at about 45-50 clk and a `$FF41`/`$FF42`
read at about 110-120 clk, so the self-test's six-cycle Becker client
pattern costs about 72 of 84 clk. That leaves about 10-15 clk per event;
a shared write/read path once cost enough to lap the ring. Any change to
the read event path or the hooks must re-run the self-test's Becker
event-rate line.

**Lag and laps.** Every 256 events core1 counts the unread slots ahead,
up to 256 (`event_lag_max`, which saturates there). At the cap it checks
for a lap: DMA C's write position, read twice and unchanged, points at a
slot that still holds an unread event. On
a lap it empties every slot forward from the writer, then the ones DMA C
wrote meanwhile, jumps to DMA C's position and counts `event_lap`. A real
lap costs about 12k clk, about 146 events dropped with no hooks run for
them. Before a check finds the lap, up to 255 stale slots (256 more for
each check that leaves a moving writer to the next) are served out of
order. The resync relies on DMA C's `WRITE_ADDR` advancing on write
completion (datasheet wording), so the slot it clears last has landed.

**Hook deadline.** A hook must finish before the CoCo next touches that
device. Two accesses to one device on consecutive cycles see the table as
it was before the first one's hook ran. Measured on both boards: status
then data on consecutive cycles gives `02,5c` with a byte ready and
`00,ff` when empty, stable; a `$FF41` poll on the cycle straight after the
`$FF42` that took the last byte still sees `02` (a phantom `0xFF` read
would follow). HDB-DOS and DW4 leave at least five cycles between the two
reads (inferred from instruction timings, not yet seen on a CoCo).

**Trace.** core1 also stores every event in a separate 512-word trace
ring. `trace dump [n]` prints `seq idx R|W data`, `seq` being the event
count since boot (no timestamp). A Becker underrun freezes it from the
data hook, with that read as the last entry; a DriveWire CRC error
freezes it from core0. `trace run` thaws it.

**Launch order** (`main.c`). `bus_engine_init()` runs after `net_init()`
(the cyw43 driver claims PIO2 first) with the read SM stopped, since
`bus drive` is off until the config replays `bus drive on`. core1 is
launched straight after, before the config replay and the `becker net`
hold, so no event waits unread (more than 2048 would lap the ring). Every
hook is registered before the launch.

## 4. PIO programs

All in `firmware/src/bus/bus_engine.pio`, clock divider 1 (150 MHz).
The listings below drop the source comments; the file has them.

### 4.1 `bus_read` (PIO0)

`in_base` GP8 (A0), `out_base` GP0 (D0, 8 pins), `jmp_pin` GP22 (R/W), ISR
shifting left with no autopush. `Y` and `X` are loaded by `engine_start`
while the SM is stopped; `X` again by every bank switch.

```
.wrap_target
top:   mov isr, y              ; y = &bus_mem >> 17
trig:  wait 0 gpio 26          ; OE_BUS low.   Plus-W: wait 1 irq 0
       jmp pin rd              ; R/W high = CoCo read
wend:  wait 1 gpio 26          ; a write: never driven.   Plus-W: wait 1 irq 2
       jmp top
rd:    in x, 3                 ; bank, as it is now
       in pins, 14             ; isr = &bus_mem[x][A13..A0]
       push noblock            ; -> DMA A -> DMA B
wbyte: pull block              ; the byte from DMA B (stall guard: stuck here)
       out pins, 8
       mov pindirs, ~null      ; drive only once the byte is in the latch
rend:  wait 1 gpio 26          ; end of cycle.   Plus-W: wait 1 irq 2
       mov pins, null [1]      ; RP2350-E9: drive low two clk...
       mov pindirs, null       ; ...then release
.wrap
```

On a Plus-W `engine_init` rewrites the three waits at `trig`, `wend` and
`rend` in instruction memory to the helper's flags (section 4.3).

### 4.2 `bus_event_p2` / `bus_event_pw` (PIO0)

`in_base` GP0 with an input count of 23, so `mov isr, pins` is D0-D7,
A0-A13 and R/W and bits 23-31 read 0. `jmp_pin` is OE_BUS (GP26) on a
Pico 2 and E (GP26) on a Plus-W.

```
.program bus_event_p2               .program bus_event_pw
.wrap_target                        .wrap_target
      wait 1 gpio 26                      wait 1 irq 1     ; helper: cycle start
      wait 0 gpio 26                smp:  mov isr, pins
smp:  mov isr, pins                       jmp pin keep     ; E still high
      jmp pin done  ; OE_BUS high         jmp done
      mov x, isr                    keep: mov x, isr
      jmp smp                             jmp smp
done: mov isr, x                    done: mov isr, x
      push noblock                        push noblock
.wrap                               .wrap
```

A sample that finds the cycle over may be from after its end, so it is
dropped and the one before it (`x`) is pushed.

### 4.3 `bus_sel_pw` (PIO2, Plus-W only)

GPIO base 16, so `gpio 40` is reachable; `irq next` lands in PIO0.

```
.wrap_target
    wait 1 gpio 40          ; a start while OE_BUS is low skips that cycle
    wait 0 gpio 40          ; OE_BUS low: selected and E high
    irq next set 0          ; read SM: cycle start
    irq next set 1          ; event SM
    wait 1 gpio 40          ; OE_BUS high: cycle over
    irq next set 2          ; read SM: release
.wrap
```

## 5. Memory map

### 5.1 RAM layout (relevant sections)

| Address range | Size | Use |
|---|---|-----|
| `0x20000000-0x2005DFFF` | 376 KB | code in SRAM (`BUS_HOT`, engine start/stop), `.data`, `.bss`, heap, stacks |
| `0x2005E000-0x2005FFFF` | 8 KB | `bus_events[2048]` — DMA C's write ring (section 3.4) |
| `0x20060000-0x2007FFFF` | 128 KB | `bus_mem[8][16384]` — the table the engine serves (section 3.2.4) |

The last two are a linker region of their own (`firmware/ld/`,
NOLOAD), so the 128 KB alignment does not pad `.bss`; the linker script
asserts both addresses. SRAM left free below them: 212.6 KB on a Pico 2
and 164.4 KB on a Plus-W (from the ELF when the event stream went in,
2026-10-02).

### 5.2 Flash layout

- Bootloader at the reset vector (Pico SDK stage2).
- Application code + constant ROM images (the manager stub) in flash (XIP).
- The FAT filesystem from `PICOCO_FS_OFFSET` (`0x180000`) to the end of
  flash, and one sector just below it for the double-RESET marker
  (`firmware/README.md` "Filesystem").

**Config:** `picoco.cfg` is a plain list of console commands, replayed
line by line at boot by `console_run_config()`; `save` writes the current
state back out as that command list. Same information, no separate config
parser. On the host it lives at `<dir>/picoco.cfg` next to the disk
images; on the Pico at the root of the flash FAT volume.

## 6. Becker port protocol

The Becker port convention, per CoCo3FPGA / XRoar and used by
DriveWire client code:

| Addr | R/W | Meaning |
|---|-----|---|
| `$FF41` | R | Status byte. Only bit 1 is defined: **1 = byte available to read**. |
| `$FF41` | W | Ignored (write‑through to a "any byte" to trigger something, but per spec, writing does nothing). |
| `$FF42` | R | Next byte from server. Always safe to read; if no byte available, implementation‑defined (we return 0xFF). |
| `$FF42` | W | Byte to server. Pushed into the outgoing queue. |

As built, the filter is not the 5-bit `/SCS` window (A0..A4) described
in earlier drafts of this section — it is the full 14-bit `bus_table`
index, since every device shares one 16384-entry table indexed by
A0..A13. `$FF41` is index `BUS_IDX_BECKER_STATUS` (0x3F41) and `$FF42`
is `BUS_IDX_BECKER_DATA` (0x3F42); the becker device claims the whole
`0x3F40..0x3F5F` range for write dispatch but only reacts to 0x3F42.

### 6.1 Response-table model

There is no per-device state struct or bus snapshot callback. Instead
(spec section 5, `firmware/src/bus/bus.h` and `bus/bus.c`):

- `bus_mem` (section 3.2.4) holds the byte the engine drives for any
  cart-selected read, indexed by bank and A0..A13. Devices call
  `bus_set_read(idx, byte)` (or `bus_io_set` for their I/O entries) to
  publish a value; nothing computes a response inside the cycle.
- `read_hooks[]` run on core1 when the event of a read at a registered
  index arrives, after the cycle (section 3.4). The becker device registers hooks on
  **both** 0x3F41 and 0x3F42 (not just 0x3F42) — see the single-writer
  rule below.
- A single-producer/single-consumer write-event ring carries
  `(idx, data)` pairs from core1 to core0; core0 drains it in its main
  loop (`device_dispatch_writes()`) and calls the owning device's
  `on_write`.

The move from the CPU loop to the PIO + DMA engine changed no device
code beyond the all-banks writer.
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

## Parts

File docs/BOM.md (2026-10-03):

# PiCoCo — Bill of Materials (v2.3.1)

Source of truth: symbol properties (`LCSC`, `MPN`) in `tools/gen_schematic.py`,
looked up 2026-09-17 (revised 2026-09-18 and 2026-09-19, "v2.3.1" in code
comments — see spec §11) and reproduced here from spec §3.3/§11
(`docs/superpowers/specs/2026-09-17-main-board-v2.3-design.md`). If this table
and the generator ever disagree, the generator wins — regenerate this file's
numbers from it, don't hand-patch around a mismatch.

## Active components

| Ref | MPN | Package | LCSC | JLC library | Lifecycle | Notes |
|-----|-----|---|---|---|---|---|
| U1  | Raspberry Pi Pico 2, or Waveshare RP2350B-Plus-W | SMD+TH module | (not stocked — order from authorized resellers: adafruit.com / pishop.us / waveshare.com) | n/a | Active | Not placed by JLC assembly; solder it yourself last |
| U10–U13 | SN74LVC245ADWR (or Nexperia 74LVC245AD if cheaper at order) | SOIC-20W | C571201 | Extended | Active | Same part x4: U10 data bidi (A=Pico, B=cart), U11–U13 address/control in |
| U14 | AMS1117-3.3 | SOT-223 | C6186 | Basic | Active | +5V → +3.3V LDO |
| U15 | SN74LVC00ADR (TI; alt Nexperia 74LVC00AD) | SOIC-14 | C485072 | Extended | Active | NAND-NAND decode, 2 of 4 gates used |
| Q2, Q4 | 2N7002 | SOT-23 | C8545 | Basic | Active | Q2 (/HALT drive), Q4 (/CART drive, reachable from a Pico 2 via JP5 1-2) — both populated |
| Q3 | 2N7002 | SOT-23 | C8545 | Basic | Active | /NMI drive (JP5 2-3 on a Pico 2, or the Plus-W pad grid) — **DNP**, needs R15/R17 fitted too |
| D2  | SS14 | SMA | C2480 | Basic | Active | +5V → VSYS_PICO |

## Passives (all 0805 unless noted)

| Ref | Value | Package | LCSC | JLC library | Notes |
|-----|---|---|---|---|---|
| R1  | 4.7 kΩ 1% | 0805 | C17673 | Basic | /HALT pull-up (required) |
| R2  | 4.7 kΩ 1% | 0805 | C17673 | Basic | /NMI pull-up — **DNP** |
| R3  | 4.7 kΩ 1% | 0805 | C17673 | Basic | /RESET pull-up — populated (no floating /RESET buffer input on the bench) |
| R4  | 10 kΩ 1% | 0805 | C17414 | Basic | 3V3_EN pull-up |
| R7  | 10 kΩ 1% | 0805 | C17414 | Basic | Q2 gate pull-up — 10 k (was 100 k; the RP2350's own reset pull-down beat 100 k) |
| R8, R9 | 100 Ω 1% | 0805 | C17408 | Basic | Q2 gate series, Pico RUN series |
| R10 | 10 kΩ 1% | 0805 | C17414 | Basic | Pico RUN pull-up — **DNP** (held RUN low when the board was USB-only) |
| R11, R12 | 33 Ω 1% | 0805 | C17634 | Basic | OE_BUS / RW_BUF series termination |
| R15 | 100 Ω 1% | 0805 | C17408 | Basic | Q3 gate series — **DNP** |
| R16 | 100 Ω 1% | 0805 | C17408 | Basic | Q4 gate series (populated, v2.3.1) |
| R17 | 100 kΩ 1% | 0805 | C149504 | Basic | Q3 gate pull-down — **DNP** |
| R18 | 100 kΩ 1% | 0805 | C149504 | Basic | Q4 gate pull-down (populated, v2.3.1) |
| R19, R20 | 470 Ω 1% | 0805 | C17710 | Basic | Audio stage (v2.3.1: was 1 kΩ, see hardware-design §4.6) |
| R21, R22 | 1 kΩ 1% | 0805 | C17513 | Basic | Audio level divider (v2.3.1: R21 was 2.2 kΩ, see hardware-design §4.6) |
| R23 | 10 kΩ 1% | 0805 | C17414 | Basic | SLENB_CART pull-up to +5V (pin 40 is cart->CoCo; nothing else drives U13 A5) |
| R24 | 0 Ω | 0805 | C17477 | Basic | AUDIO_F2 -> AUDIO_AC bypass (DC-coupled default; remove + fit C15 for AC coupling) |
| R25 | 10 kΩ 1% | 0805 | C17414 | Basic | U10_OE pull-up to +3V3 (guards an unprogrammed module with JP2 in the firmware position) |
| C1, C2 | 10 µF X5R ≥10V | 0805 | C15850 | Basic | +5V edge bulk / LDO input |
| C3 | 22 µF X5R ≥6.3V | 0805 | C45783 | Basic | LDO output — MLCC-compatible AMS1117 variant required |
| C4, C6–C10 | 100 nF X7R 50V | 0805 | C49678 | Basic | Per-IC decoupling (C5 intentionally unused) |
| C13, C14 | 10 nF X7R | 0805 | C1710 | Basic | Audio 2-pole RC filter |
| C16 | 10 µF X5R ≥10V | 0805 | C15850 | Basic | Local +3V3 bulk at the buffer row, next to U11/U12 (v2.3.1) |
| C12 | 1000 µF 6.3V SMD electrolytic | D8x10 mm | pick at order (C970711 had stock 2026-09-17) | n/a | VSYS_PICO Wi-Fi burst cap — **DNP** on a Pico 2 |
| C15 | 1 µF | 0805 | C28323 | Basic | AC-coupling series cap, AUDIO_F2 -> AUDIO_AC ahead of R21 (fit + remove R24 for AC coupling) — **DNP** |

## Connectors and mechanical

| Ref | Part | Footprint | Notes |
|-----|---|---|---|
| P1  | (custom COCO-CART edge fingers) | `PiCoCo:COCO-CART-2.1X1.75` | PCB fingers only; no connector part |
| JP2 | Solder jumper, 3-pad bridged 1-2 | `Jumper:SolderJumper-3_P1.3mm_Bridged12_RoundedPad1.0x1.5mm` | U10 /OE source select |
| JP3 | Solder jumper, 3-pad bridged 1-2 | (same footprint) | Header pin 34: audio (default, v2.3.1) or E |
| JP4 | Solder jumper, 2-pad open | `Jumper:SolderJumper-2_P1.3mm_Open_RoundedPad1.0x1.5mm` | Q_CART <-> CART_CART autostart tie — open by default |
| JP5 | Solder jumper, 3-pad open | `Jumper:SolderJumper-3_P1.3mm_Open_RoundedPad1.0x1.5mm` | Header pin 34 drive select: 1=CART_DRV (Q4), 2=PICO_P34, 3=NMI_DRV (Q3, DNP) — open by default, mutually exclusive with JP3 (v2.3.1) |
| J1  | 1x5 pin header, 2.54 mm (DNP) | `Connector_PinHeader_2.54mm:PinHeader_1x05_P2.54mm_Vertical` | "EXP (Plus-W)": EXP_GP35/GP43/GP44/GP45 + GND — Plus-W only (v2.3.1) |
| TP1–TP8 | `TestPoint:TestPoint_Pad_1.0x1.0mm` | — | OE_BUS, RW_BUF, CTS_BUF, SCS_BUF, E_BUF, +3V3, SND_CART, GND |
| FID1–FID3 | `Fiducial:Fiducial_1mm_Mask2mm` | — | SMT assembly fiducials, no net, excluded from BOM |

There is no `J_SWD` header and no mounting hole (`MTG1`) on this board — both
were removed in v2.3 (see `CLAUDE.md` and `docs/hardware-design.md` §7, §9).

DNP by default: R2, R10, R15, R17, Q3, C12, C15, J1. Everything else,
including the JP5-reachable /CART stage (Q4/R16/R18), is populated.

## Hobbyist substitutions

- **D2 Schottky**: any 1 A Schottky in SMA/DO-214AC works (SS14, SS24,
  SS34, B150-E3, 1N5819HW). The ~0.3 V drop is what matters; higher-Vf
  parts leave less VSYS_PICO headroom.
- **AMS1117-3.3**: LM1117-3.3 and NCP1117-3.3 drop in on the same
  SOT-223 footprint. If C3 oscillation appears at bring-up, switch to
  TLV755P-33 (SOT-23-5, slightly different footprint) which is
  unconditionally stable with MLCC.
- **2N7002**: any small-signal N-FET with Vgs(th) ≤ 2 V and
  Id ≥ 100 mA in SOT-23: BSS138, ZVN3306A, PMV40UN2. Required: can be
  turned on by a 3.3 V gate drive.
- **SN74LVC245A**: any 3.3V-tolerant octal transceiver in the same
  SOIC-20W pinout (74HCT245 works electrically but is not 5V-tolerant
  on its 3.3V side at speed — stick to the LVC family).
- **SN74LVC00A**: any quad 2-input NAND in SOIC-14, e.g. 74HC00 for a
  3.3V-tolerant bench substitute (used during breadboard bring-up).

## Non-board parts

- **HDB-DOS ROM image (8 KB, Becker build)**: users supply their own
  binary (`hdbdw3bck.rom`, or `hdbdw3bc3.rom` for a CoCo 3). Sources:
  Cloud-9, or build it from ToolShed's `hdbdos/` tree
  (`docs/ADDITIONAL_ROADMAP.md` §3). The firmware's built-in ROM manager
  needs no file.
- **USB cable for the module's port**: for the console, bridge mode and
  flashing (BOOTSEL).
- **DriveWire host software**: optional; the firmware serves disk images
  from flash itself (`becker native`). For bridge or WiFi mode:
  DriveWire 4 (Java, Cloud-9), `picoco-host` (this repo) or FujiNet-PC.

## Ordering

See `fab/main/READ-BEFORE-ORDERING.txt` for the exact JLCPCB order
settings (base material, gold fingers, bevel, DNP list, SMT assembly
files) and the budget variant for bare boards.

## Cost estimate (2026 pricing, 5 PCBs + 2 assembled)

- **Hard gold fingers + 30° bevel (recommended)**: about $90–$130
  shipped, PCB + SMT assembly included, module and hand-soldered
  passives (Q3/R15/R17/C12/C15/J1 DNP by default) not included.
- **ENIG, no gold fingers, no bevel (budget/bare-board variant)**:
  subtract roughly $30–$50 from the above — fine for a lightly used
  cart, but the fingers will wear faster in a well-used CoCo slot.

The LCSC numbers were used for the first JLCPCB-assembled board (v2.3.1
#1, 2026-09-30), which works. The 100 kΩ LCSC number changed from C17407
(discontinued 2026-09) to C149504. Prices drift; check DigiKey/Mouser/LCSC and JLCPCB's
current quote before ordering. Substitute equivalents freely on the
generics (0805 passives, SOIC logic) — the part numbers above are one
known-good source each.

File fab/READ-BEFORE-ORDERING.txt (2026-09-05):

================================================================
PiCoCo — PCB Fabrication Checklist
READ THIS BEFORE SUBMITTING TO ANY BOARD HOUSE
================================================================

The cartridge edge fingers insert into a 40-year-old CoCo slot. Using
JLCPCB's or PCBWay's default plating options WILL destroy the slot's
bronze wipers over time. The settings below are not optional.

-----------------------------------------------------------------
JLCPCB ORDER SETTINGS (verified 2026-04; re-check before ordering)
-----------------------------------------------------------------

  Base material:         FR-4
  Layers:                2
  Dimensions:            ~98 x 55 mm (see Gerber outline)
  PCB thickness:         1.6 mm       (*** critical — matches CoCo slot width)
  PCB color:             Any (green is cheapest)
  Silkscreen:            White (on green) or Black (on other colors)
  Surface finish:        HASL with lead, or ENIG — does NOT affect fingers
  Outer copper weight:   1 oz
  Gold fingers:          YES          (*** critical)
  Gold finger bevel:     30°          (*** critical)
  Gold thickness:        1 µm minimum (*** critical; 2 µm is better)
  Impedance control:     No
  Castellated holes:     No
  Remove order number:   User's choice

-----------------------------------------------------------------
WHY THESE SETTINGS MATTER
-----------------------------------------------------------------

* Hard gold plating on fingers: the CoCo slot uses bronze wipers.
  HASL or ENIG plating will abrade within tens of insertion cycles,
  leaving oxide that ruins signal integrity on /CTS, /SCS, and data.
  Hard gold lasts thousands of cycles.

* 30° bevel on leading edge: a square-cut edge will scrape and lift
  pad material on insertion. The bevel glides into the slot.

* 1 µm gold minimum: thinner plating wears through quickly,
  especially on older CoCo slots where the wipers may already be
  worn to an abrasive surface.

* 1.6 mm board (= 0.062"): the CoCo slot is spec'd for 0.062"
  boards. 1.2 mm is too thin (loose fit, intermittent contact).
  2.0 mm is too thick and won't insert.

-----------------------------------------------------------------
ASSEMBLY (OPTIONAL)
-----------------------------------------------------------------

If ordering JLCPCB PCBA (SMT assembly):
- Enable SMT Assembly, top side only.
- Upload the BOM.csv and CPL.csv from this fab/ directory.
- Confirm U15 (SN74LVC1G11) is available in JLC Extended Library;
  if not, substitute with an equivalent 3-input AND gate in SC-70-6.
- DNP parts (do-not-populate): R2, R3, J_CART, J_LVC. Mark these as
  "Do not place" in the JLC order form or they will be soldered
  unnecessarily.
- Through-hole parts (P1 edge connector, JP1 header, J_SWD header)
  must be hand-soldered after JLC assembly.

-----------------------------------------------------------------
POST-ORDER VERIFICATION
-----------------------------------------------------------------

When boards arrive:
1. Verify edge fingers are plated gold, not silver-tinted (HASL).
2. Verify 30° bevel is present (feel with a fingernail — should
   slope, not square).
3. Test-fit into a CoCo slot BEFORE soldering anything. If the
   board doesn't seat, a light sand on the bevel usually fixes it.

If a board was shipped with HASL fingers or no bevel, CONTACT THE
FAB HOUSE for a replacement — do not insert it into a real CoCo.

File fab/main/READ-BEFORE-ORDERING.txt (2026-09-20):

================================================================
PiCoCo — PCB Fabrication Checklist (main board, v2.3.1)
READ THIS BEFORE SUBMITTING TO ANY BOARD HOUSE
================================================================

The cartridge edge fingers insert into a 40-year-old CoCo slot. Using
JLCPCB's or PCBWay's default plating options WILL destroy the slot's
bronze wipers over time. The settings below are not optional.

-----------------------------------------------------------------
JLCPCB ORDER SETTINGS (v2.3.1, 2026-09)
-----------------------------------------------------------------

  Base material FR-4 / Layers 2 / Dimensions 98 x 77.2 mm overall (67.0 mm body + 10.2 mm finger tongue) / Thickness 1.6 mm (critical)
  Surface finish: ENIG (all pads gold; fingers get hard gold below, never HASL)
  Outer copper 1 oz
  Gold fingers: YES (critical) / Bevel: 30 deg (critical) / Gold thickness: 1 um min (2 um better)
  Order remark: Gold fingers / 30 deg bevel on the protruding bottom tongue edge only (52.8 mm
  wide), not the full board edge.
  Mark on PCB: "Remove Mark" (no order-number placeholder on the board since v2.3.1)
  Castellated holes: No / Impedance: No
  SMT assembly: Top side, Economic. Files: fab/main/PiCoCo-BOM-jlc.csv, fab/main/PiCoCo-CPL-jlc.csv
  Extended parts on this board: SN74LVC245A x4 (one part number), SN74LVC00A x1. Confirm stock.
  Parts NOT placed (by design): U1 module (yours), R2 R10 R15 R17 Q3 C12 C15 J1 J2 J3 (DNP). Q4/R16/R18
  (the JP5-reachable /CART drive stage) ARE placed regardless of module.
  JP2 ships bridged 1-2 (hardware /OE default); JP3 ships bridged 1-2, which now routes
  AUDIO_PWM to header pin 34 by default (Pico 2 sound out of the box) — cut 1-2/bridge 2-3 to
  put E on header pin 34 instead; JP4 (Q_CART<->CART_CART autostart tie) ships open by default;
  JP5 (header-pin-34 /CART or /NMI drive select) ships open by default and shares that header
  pin with JP3 — never bridge both JP3 and JP5. J1 ("EXP (Plus-W)" header) and J2/J3 (1x3 pin-header twins of JP3/JP5) are DNP.
  Check the placement preview: every SOIC/SOT pin-1 dot matches the silkscreen. If any part is
  rotated, fix the ROT table in tools/jlc_post.py, rerun tools/gen_fab.sh, re-upload.
  Look hardest at D2 (SMA diode: cathode band must face U1/VSYS, reversed = board never powers)
  and U14 (SOT-223 AMS1117: tab/pin 2 is +3V3 output; reversed = +5V on the 3.3V rail and every
  logic IC dies). JLCPCB's SMA and SOT-223 zero angles often differ from KiCad's by 180 deg.
  Unverified LCSC numbers, confirm value/voltage in the parts step: C17710 (470R, R19/R20),
  C1710 (10nF), C17513 (1k), C17477 (0R, R24), C28323 (1uF, C15). C45783 (C3, 22uF 25V) was
  verified 2026-09-17 and is no longer on this list. The rest were checked 2026-09-17.
BUDGET VARIANT (bare boards, hobbyist): same Gerbers, ENIG, gold fingers NO, bevel NO.
  ENIG fingers wear after tens of insertions; fine for a lightly used cart.
PLUS-W INSTALL: fab/main/stencil-module/*F_Paste.gbr is a paste stencil for the 15 grid pads
  only — the 40 castellation apertures sit over plated holes and paste falls through them, so
  hand-solder the castellations (hot air or a paste syringe for the 15 grid pads); or mount on
  2x20 headers and forgo the 15 pads.
FIT (measured 2026-09-18 on a CoCo 3): opening 114 x 30 mm, connector face 43 mm inside the case,
  connector slot depth ~6 mm, so the case surface is ~49 mm from the finger tip; the shoulders
  (10.2 mm from the tip) never touch the connector and the USB-C port is ~16 mm outside the case.
MODULE: solder the Pico 2 flat on the castellations, or on 2x20 headers. Nothing under it.
  Pico 2 flat mount: its three underside SWD/debug pads sit on the carrier's GP29/GP32/GP35
  grid pads (they overlap by ~0.05 mm). Put Kapton tape over those three grid pads first, or
  mount the Pico 2 on headers. Not an issue for the Plus-W, which uses the grid.

-----------------------------------------------------------------
WHY THESE SETTINGS MATTER
-----------------------------------------------------------------

* Hard gold plating on fingers: the CoCo slot uses bronze wipers.
  HASL or ENIG plating will abrade within tens of insertion cycles,
  leaving oxide that ruins signal integrity on /CTS, /SCS, and data.
  Hard gold lasts thousands of cycles.

* 30° bevel on leading edge: a square-cut edge will scrape and lift
  pad material on insertion. The bevel glides into the slot.

* 1 µm gold minimum: thinner plating wears through quickly,
  especially on older CoCo slots where the wipers may already be
  worn to an abrasive surface.

* 1.6 mm board (= 0.062"): the CoCo slot is spec'd for 0.062"
  boards. 1.2 mm is too thin (loose fit, intermittent contact).
  2.0 mm is too thick and won't insert.

-----------------------------------------------------------------
POST-ORDER VERIFICATION
-----------------------------------------------------------------

When boards arrive:
1. Verify edge fingers are plated gold, not silver-tinted (HASL).
2. Verify 30° bevel is present (feel with a fingernail — should
   slope, not square).
3. Test-fit into a CoCo slot BEFORE soldering anything. If the
   board doesn't seat, a light sand on the bevel usually fixes it.

If a board was shipped with HASL fingers or no bevel, CONTACT THE
FAB HOUSE for a replacement — do not insert it into a real CoCo.

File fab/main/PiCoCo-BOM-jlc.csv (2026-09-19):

Comment | Designator | Footprint | LCSC Part # | MPN
10uF | C1,C2,C16 | C_0805_2012Metric | C15850 | 0805 10uF
22uF | C3 | C_0805_2012Metric | C45783 | 0805 22uF
100nF | C4,C6,C7,C8,C9,C10 | C_0805_2012Metric | C49678 | 0805 100nF
10nF | C13,C14 | C_0805_2012Metric | C1710 | 0805 10nF
SS14 | D2 | D_SMA | C2480 | SS14
2N7002 | Q2,Q4 | SOT-23 | C8545 | 2N7002
4.7k | R1,R3 | R_0805_2012Metric | C17673 | 0805 4.7k 1%
10k | R4,R7,R23,R25 | R_0805_2012Metric | C17414 | 0805 10k 1%
100 | R8,R9,R16 | R_0805_2012Metric | C17408 | 0805 100 1%
33 | R11,R12 | R_0805_2012Metric | C17634 | 0805 33 1%
100k | R18 | R_0805_2012Metric | C149504 | 0805 100k 1%
470 | R19,R20 | R_0805_2012Metric | C17710 | 0805 470 1%
1k | R21,R22 | R_0805_2012Metric | C17513 | 0805 1k 1%
0 | R24 | R_0805_2012Metric | C17477 | 0805 0 1%
SN74LVC245A | U10,U11,U12,U13 | SOIC-20W_7.5x12.8mm_P1.27mm | C571201 | SN74LVC245ADWR
AMS1117-3.3 | U14 | SOT-223-3_TabPin2 | C6186 | AMS1117-3.3
SN74LVC00A | U15 | SOIC-14_3.9x8.7mm_P1.27mm | C485072 | SN74LVC00ADR

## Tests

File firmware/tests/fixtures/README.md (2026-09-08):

# Replay fixtures

Files here are `dw capture` recordings ("console.c" `console_capture`) of a
real DriveWire transaction: a stream of length-prefixed chunks, one per
`dw_feed`/`dw_send` call while the capture was on:

```
byte 0    dir       0 = bytes the server received (rx), 1 = bytes it sent (tx)
byte 1-2  len       chunk length, little-endian u16
byte 3.. len bytes  the chunk contents
```

`test_replay.c` reads every `*.cap` file in this directory, feeds the dir-0
(rx) chunks through a fresh `dw_server` (mounting `raw.dsk`, a 630-sector
image where sector `n`'s byte 0 is `n & 0xFF` and byte 1 is `n >> 8`, same as
`test_stack.c`), and checks the bytes the server sends back match the dir-1
(tx) chunks recorded in the file, byte for byte. It also requires
`stats.timeouts == 0` and `stats.unknown_op == 0`. This is a regression test:
if a protocol change alters the reply for a request captured here, the test
fails.

`picoco-host --replay <file>` (see `host/picoco_host.c`) plays a capture
file the same way: it feeds the dir-0 chunks into a live `dw_server` (with
`dw_tick` between each) and ignores the dir-1 chunks, then prints stats.

## Fixtures

- `readex_boot.cap`: one READEX (`0xD2`) of drive 0, LSN 9, against
  `raw.dsk`, mounted with `hdbdos off` (matches `coco_readex_sector` in
  `test_stack.c`).
- `trace_readex.txt`: not a capture file, a `trace dump 64` text log (see
  `tools/tracedump.py`) taken right after `coco_readex_sector` sends the
  READEX opcode + drive/LSN bytes (before the 256-byte data phase, whose
  hundreds of status/data polls would otherwise scroll the 5-byte request
  out of a 64-entry dump).

## Adding a fixture

1. In `test_stack.c`, temporarily bracket the transaction you want to
   capture with `console_exec("dw capture on NAME.cap")` /
   `console_exec("dw capture off")`.
2. Build and run `test_stack`; find the temp directory it used (printed by
   `mkdtemp`, or the newest `$TMPDIR/stackXXXXXX` directory) and copy
   `NAME.cap` from there into `tests/fixtures/`.
3. Remove the temporary capture calls from `test_stack.c`.
4. Rebuild; `test_replay.c` picks up any `*.cap` file in this directory
   automatically.

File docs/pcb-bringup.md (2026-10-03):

# PiCoCo v2.3.1 PCB bring-up checklist

First assembled boards arrived 2026-09-30 (JLC assembly, module not fitted).
Do the phases in order; each one is cheap to undo and the next one is not.
Record results in the table at the end.

Bench power: +5 V into finger 9 (front side, 5th from the pin-1 end; silk
"2" is on the back), GND at TP8. Set the supply to 5.0 V, current limit
100 mA for phase 2, 500 mA once the module is on. No bench supply
(2026-09-30): a Mac USB port through a breakout works, or use the CoCo
itself as the supply. The module's USB does not feed +5V (D2 blocks it).
In the CoCo the top 28 mm of the board is outside the case, so TP6, TP8
and the module pads are reachable; finger-side checks (finger 3, 5) move
to the console phase.

## Phase 1: no power, DMM only (10 min)

1. Fingers: gold, not silver; bevel slopes under a fingernail. Test-fit in
   the CoCo slot with the CoCo unplugged, then pull it out.
2. DNP list matches the board: R2 R10 R15 R17 Q3 C12 C15 J1 J2 J3 empty,
   Q4/R16/R18 fitted.
3. No shorts (resistance mode, expect > 1 kΩ, capacitors may ramp):
   finger 9 to TP8, TP6 to TP8, module pad 39 (VSYS) to TP8.
4. D2 polarity, diode mode: red on finger 9, black on module pad 39 reads
   ~0.2-0.3 V; reversed reads open. Reversed D2 = the module never powers.
5. Jumpers: JP2 1-2 and JP3 1-2 read 0 Ω; JP4 open; all three JP5 pads open.

## Phase 2: bench power, no module (10 min)

Clip finger 6 (E) to GND for every bench test without a CoCo. E low forces
OE_BUS high (TP1), so U10 stays disabled while the other cart inputs float.

1. Apply 5.0 V. Current under ~30 mA and steady.
2. TP6 = 3.3 V (3.2-3.4). U14 stays cool after a minute. Reversed U14 would
   put +5 V on TP6: cut power at once.
3. Module pad 39 = ~4.7 V (5 V minus D2). Pad 36 (3V3_OUT) reads 0 V, it
   is NC by design.
4. TP1 (OE_BUS) high with E clipped low. Finger 3 (/HALT) low: R7 pulls Q2
   on with no module, that is the boot-hold default working.
5. Finger 5 (/RESET) ~5 V via R3; module RUN pad (pin 30) ~3.3 V behind
   U13. Short finger 5 to GND: RUN pad falls to 0 V.

## Phase 3: fit the module

Board #1 carries a Pico 2 (results below). Put the Plus-W on the second
board.

- Pico 2 flat mount: Kapton over the carrier grid pads under the Pico's
  three SWD/debug pads (GP29/GP32/GP35) first. See
  fab/main/READ-BEFORE-ORDERING.txt "MODULE".
- Plus-W: paste the 15 grid pads with fab/main/stencil-module, hand-solder
  the 40 castellations.
- Repeat phase 1 step 3 after soldering (a bridged castellation shows up
  as a rail short now).

## Phase 4: bench power + USB, no CoCo (20 min)

Keep the E-to-GND clip on. Bench 5 V on finger 9 plus USB to the Mac.
Do not run `bus selftest` on the PCB: U11-U13 outputs would fight PIO1.

1. USB only first: two serial ports enumerate, `version`, `status`.
   `log dump` shows `core1 up, halt released`.
2. Add bench 5 V: total edge current at idle (expect < 100 mA for a
   Pico 2). This is the number the 300 mA cart budget starts from.
3. /HALT electrical check: finger 3 is high after boot (R1 to +5 V),
   `halt on` pulls it to 0 V, `halt off` releases.
4. RUN path: short finger 5 to GND for a second. The console drops and
   comes back, `status` shows a fresh boot.
5. Cold boot from the edge, no USB: power-cycle the bench 5 V with USB
   unplugged, watch finger 3 on a scope or DMM. It must be low from t=0 and
   go high once (firmware release, ~1.2 s). Never high before that.
6. Plus-W only: `net join` + `net scan` while scoping module pad 39
   (`bus selftest net` is not supported by the PIO engine).
   Log the VSYS droop during the WiFi burst; that decides whether C12 gets
   fitted (TEST_PLAN G.2 "VSYS scope trace", done on the bench first).

## Phase 5: in the CoCo 3

Remove the E clip. CoCo off, insert the board, USB to the Mac for the
console, then power the CoCo on. Boot a saved native HDB-DOS config
(`rom load hdbdw3bck.rom`, `becker native`, `bus drive on`, `save`).

1. HDB-DOS banner on the CoCo screen; `status` shows read cycles and
   `engine_stall 0`, `event_drop 0`. Any garbage or no banner: `status` counters first,
   then TP1/TP5 on a scope (OE_BUS low only inside E high).
2. DIR, LOADM+EXEC DINORUN, SAVE, `DRIVE 3:RUN"PICOCO"` manager.
3. CoCo RESET button: Pico reboots (console reconnects) and HDB-DOS comes
   back. Then a full CoCo power cycle with USB unplugged: the cold-boot
   race for real.
4. Audio: JP3 1-2 default puts AUDIO_PWM on the CoCo speaker; play a
   sound from the console or a game and check TP7.
5. Plus-W: TEST_PLAN G.2 rows (WiFi boot hold, DW4/FujiNet-PC over WiFi,
   fallback, manager WiFi screen) and the K.2 rows.

## Read-path timing: PIO engine (2026-10-02)

Reads are now served by PIO and DMA with no CPU in the path, on both
boards. Measured on bare modules: OE_BUS falls to the byte on D0-D7 in
22 clk (146 ns) on a Pico 2, 14 clk inside the 36 clk realistic sample
point at 1.79 MHz; on a Plus-W 24 clk (corrected for the self-test's fake
decode), 12 clk of margin. The full table is in
`docs/firmware-architecture.md` §8 and the expected self-test lines in
`firmware/TEST_PLAN.md` section K. They are bare-module figures: the
self-test is not run on a PCB (phase 4), so the PCB results are the
TEST_PLAN K.2 bench rows.

The "1.79 MHz fault" section below and items 1 and 4 of "NitrOS-9
bring-up" (with the bare-module follow-ups after them) describe the core1
CPU loop of firmware 1.3 and 1.4 (tag `fw-1.4-cpu-loop`). They are kept
as history; the counters they name (`addr_resample`, `late_precompute`,
`oe_glitch`) and the `pad_hold` line no longer exist.

## 1.79 MHz fault found on the PCB (2026-09-30, CPU loop, history)

Symptom: with hdbdw3bc3.rom (CoCo 3, 1.79 MHz during transfers) a DIR or
SAVE intermittently returned ?IO ERROR and every DriveWire op after it
failed its checksum until the Pico rebooted. Counters: one Becker
underrun, pushes = reads + 1, so the CoCo had taken one phantom byte
while the server was still fetching the sector and the stream was shifted
by one from then on. The trace (now frozen at the first underrun or CRC
error) showed the request bytes, a few not-ready polls, then a $FF42 read
the Pico never announced.

Cause, two parts:
1. The Pico 2 core1 read path drove the data pins ~245 ns after E rose
   (sample, 70 ns resample, lookup). At 1.79 MHz E is high for 279 ns, so
   the drive sat in the 6809E's latch window on timing tails. Adding 33 ns
   (+5 nops) made the very first poll fail, which confirmed the margin.
2. D0-D7 idled with pull-ups, so a late or missed $FF41 poll showed the
   CoCo 0xFF through the hardware-enabled U10, and 0xFF has the Becker
   "ready" bit set. That turned a rare late poll into a phantom byte.

Fix (firmware, uncommitted at the time of writing): core1 precomputes the
response while OE_BUS is high and drives within ~100 ns of it falling
(mismatches redrive and count as addr_resample; back-to-back cycles with
no idle sample count as late_precompute, 4097 per boot from the CoCo 3
ROM copy, benign); D0-D7 idle pulled down so a late poll reads "not
ready" and is retried. The breadboard never showed this because it ran
firmware 1.2 with the lookup inline and with the same pull-ups; the PCB
exposed it on firmware 1.3.

## Results

| Check | Result | Date |
|---|---|---|
| 1 fingers/bevel/slot fit | pass, fits the CoCo 3 slot, bevel good | 2026-09-30 |
| 1 DNP list | pass | 2026-09-30 |
| 1 rail shorts | pass, all open | 2026-09-30 |
| 1 D2 polarity | pass, 0.240 V red finger 9 / black pad 39 | 2026-09-30 |
| 1 jumper defaults | pass, JP2/JP3 1-2, JP4/JP5 open | 2026-09-30 |
| 2 TP6, pad 39, pad 36 (powered from the CoCo, no module) | pass: TP6 3.3 V, pad 39 ~4.7 V, pad 36 0.2-0.4 mV (floating, NC); current not measured, no bench supply | 2026-09-30 |
| 2 /HALT low with no module | | |
| 2 RUN follows /RESET | | |
| 4 USB enumerate + core1 up | pass: Pico 2 flat-mounted, firmware 1.3 flashed via BOOTSEL, two CDC ports, `core1 up, halt released`; files + config loaded (hdbdw3bck.rom, DINORUN.DSK drive 0, PICOCO.DSK drive 3, native) | 2026-09-30 |
| 4 edge current with module | | |
| 4 halt on/off at finger 3 | pass functionally: boot hold works on cart power (row below); no DMM reading taken | 2026-09-30 |
| 4 RUN reboot from finger 5 | pass by inference: Pico uptime restarted when the CoCo powered on with USB already attached (CoCo /RESET pulsed RUN through U13/R9) | 2026-09-30 |
| 4 cold-boot hold from edge power | pass: CoCo power-up with USB unplugged boots straight into HDB-DOS (R7 10k hold wins) | 2026-09-30 |
| 4 Plus-W VSYS droop | | |
| 5 HDB-DOS boots in the CoCo | pass, first try: banner + DIR of DINORUN.DSK. status: 11869 cycles, addr_resample 0, becker 1799 reads underrun 0 overrun 0, dw 7 reads crc_err 0, halt released 2.6 s after boot | 2026-09-30 |
| 5 1.79 MHz ROM (hdbdw3bc3) | FAILED on firmware 1.3 as merged, then fixed (see below): SAVE gave ?IO ERROR, then every sector failed its checksum (crc_err 5, underrun 1, one byte left in the ring = permanent one-byte desync). 0.89 MHz ROM and the write path were clean throughout. After the fix: 4 LOADMs + SAVE at 1.79 MHz, crc_err 0 underrun 0 | 2026-09-30 |
| 5 DIR/LOADM/SAVE/manager | pass: DIR, LOADM+EXEC DINORUN, `DRIVE 3:RUN"PICOCO"` manager (exit is BREAK). SAVE not yet tried. After: 46450 cycles, addr_resample 0, 72 dw reads crc_err 0, becker 18752 reads underrun/overrun 0 | 2026-09-30 |
| 5 RESET button + cold power cycle | pass: RESET reboots the Pico (uptime restarts) and the CoCo warm-starts back into DINORUN, which hooks the reset vector (CoCo behaviour, not the board); cold power cycle boots HDB-DOS | 2026-09-30 |
| 5 audio at TP7 / speaker | open: nothing drives AUDIO_PWM until the sound plan lands | |
| 5 G.2 WiFi rows | | |

## NitrOS-9 bring-up (2026-10-01)

Bench: PCB v2.3.1 #1, Pico 2, CoCo 3 with a 6309 and 2 MB. Test plan
section H. Four faults, in the order they showed up.

1. **Phantom Becker byte after a write (stock NitrOS-9 boot hung at `i2x`).**
   The trace froze on a `$FF41` poll the table answered `00`, 36 us after a
   `$26` write, followed by a `$FF42` read: the CoCo saw bit 1. Working
   explanation: RP2350-E9, a pad left high with only the internal pull-down
   sits near 2.2 V, so the written byte was still on D0-D7 when U10 enabled
   for the next read and a late drive showed it. Fix: core1 drives D0-D7 low
   and releases after every cycle. The E9 thresholds were not verified.
2. **EOU hung after "Coco SDC - Not detected".** Its SDC/GIME-X detection
   writes `64 64 00 64 00 ...` to `$FF42`. The server parsed that as
   SERWRITEM and ate the next ops as payload. Fix: `dw_feed` drops SERWRITEM
   whose channel byte is 0 or `$64`. `COCO3FPGA=1` in EOU's env.file is
   meant to skip the detection but did not on this image.
3. **Bridge mode dropped bytes with no listener.** HDB-DOS reads drive 0 at
   power-on and has no timeout, so a request sent before the relay attached
   hung it at the banner. Fix: the bridge pump takes from the Becker ring
   only what CDC0 can accept.
4. **Bytes read as 0x00 at 1.79 MHz (0.7-4 % of sectors re-read).** Every
   failed checksum was low by the value of one or more bytes. The rate moved
   with unrelated code changes, and a three-sample filter on OE_BUS with a
   counter (`oe_glitch`, since removed) read 0, which ruled out a spike
   on OE_BUS. Cause: the 2026-09-30 loop recomputed on every idle pass
   (~20 clk_sys cycles) and then did three stores, so the drive landed an
   estimated 125-260 ns after OE_BUS fell; E is high for 279 ns. Fix: the
   idle loop keeps the answer in the output latch (outputs off), recomputes
   only when address or R/W change, and enables with one store: estimated
   60-115 ns. Result on an EOU boot: 1 re-read in 1,888 sectors, was 80 in
   1,966. The figures are instruction counts, not scope measurements.

First cut of 4 had `addr_resample` at ~5 % of reads: A7 arrives a few ns
after the other address lines, a sample landed in that gap, the recompute
pass (~33 cycles) ran on it and the next sample was already OE-low. The loop
now looks at the pins a second time before committing a recompute;
`addr_resample` read 0 in 280k reads afterwards.

Review findings applied: the idle loop loads the latch only for a read it
will drive (`bus selftest` keeps its write data there), and the capture-only
branch releases the outputs. `bus selftest` on a bare Pico 2 has not been
rerun since. The bridge pump replays whatever sat in the Becker ring when a
listener attaches; fine for HDB-DOS, untested for a client that retries.

Bare Pico 2 follow-up, same day (`bus selftest`, chip revision A2):

- E9 is confirmed, not just a working explanation: D0-D7 driven high and
  released onto the internal pull-downs still read `ff` after 51 ms; driven
  low and released they read `00`. The CPU-loop self-test printed this as `pad_hold`.
- The self-test now measures three read latencies after OE_BUS falls. Idle
  bus (a Becker poll): 139-146 ns; the 2026-09-30 loop measured 264-286 ns in
  the same sweep, against a 230 ns budget at 1.79 MHz. Back-to-back reads:
  256-286 ns. A read straight after a write: 366-396 ns. The last two only
  occur when the CPU executes from the cart ROM, which a CoCo 3 in fast mode
  does not do; their budget is the 0.89 MHz one (480 ns).
- The old `response_within_300ns` check measured the back-to-back path, and
  the old loop passed "write `$FF40`=1, read back 1" partly because the
  written byte was still on the pads when the PIO sampled.
- The idle loop reloads the latch only when address/RW change, so a table or
  ROM change by core0 while the bus sat on one address left it stale (second
  self-test in one boot read `ff`). The read path now checks the enabled
  value against the table after the fast-path enable and redrives if needed.

Plus-W, same day, bare module (`bus selftest`, chip revision A4, three
fresh boots, all pass): the loop now preloads the latch at Q time (fast path
is two stores) and drives the pads low at the end of every cycle; after a
write it waits for OE_BUS before discharging. Response from idle 132 ns
after E rises (was 139-154), back-to-back burst 381 ns (was 352-366,
budget 480). A three-sample end-of-cycle filter as on the Pico 2 cost too
much there (burst 425-454 ns) and was left out. The A4 chip does not show
E9: `pad_hold` reads `00` 10 us after release. Not covered by a bare
module: anything that depends on JP2 or on a real OE_BUS.

A second `bus selftest` in one boot failed `read_bank0_marker` on the
Plus-W, with the old loop too; `bench.py` reboots after each run.

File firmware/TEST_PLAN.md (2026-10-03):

# PiCoCo firmware bench test plan

Checklist for the manual tests that need hands on the hardware. Run it
with Claude: you do the wiring and meter readings, Claude drives the
console over USB and records results. Each step says what to do, what
Claude will run, and what "pass" looks like.

The console port is the second `/dev/cu.usbmodem*`. The bench board is
PCB v2.3.1 #1 (Pico 2); the Plus-W PCB has not run in a CoCo.

## Already verified on this Pico 2 (no CoCo)

| Check | Result |
|---|---|
| USB enumerates: two serial ports + storage interface | pass (after allowing the accessory in macOS Privacy & Security) |
| `version`, `status`, `log dump`, `help` | pass |
| `smoke` (GP0..GP7 + LED), `halt on` / `halt off` accepted | pass (GP27's electrical check: PCB phase 4, pcb-bringup) |
| `fs format`, `fs ls`, `save`, reboot, config replay | pass |
| `dw selftest` (create, mount, READ, WRITE, READEX, eject) | pass |
| `fs export` mounts as `PICOCO` on the Mac, copy a `.dsk`, eject, `fs import`, file persists across reboot | pass |
| Guards: export/format refused with a drive mounted or capture open; fs/dw commands refused while exporting; import refused before host eject | pass |
| `crash` and `crash panic` leave a record that `status` shows after reboot | pass |
| `reboot` reports `last reset reboot`, hard fault reports `hardfault pc=...` | pass |
| core1 running: `log dump` shows `core1 up, halt released` | pass |
| Address decode, data byte on the pins, /HALT drive | `bus selftest` (K.1) and the PCB rows (F) cover them |

## F. PCB bring-up (v2.3.1): two boards, real CoCo hardware

One board built with a Pico 2, one with a Waveshare RP2350B-Plus-W
(`-DPICOCO_BOARD=plusw`). Test both on CoCo 1, CoCo 2, CoCo 3, bare and
through a Multi-Pak Interface (MPI).

### F.1 Pre-power checks (both boards)

- JP2 at 1-2 (hardware /OE), JP3 at 1-2 (audio on header pin 34), JP4 open
  (no autostart tie), JP5 open (no firmware /CART or /NMI drive yet).
- R7 = 10 kΩ (the v2.3.1 value; 100 kΩ loses to the RP2350's own reset
  pull-down and never releases /HALT).
- Plus-W builds only: the radio's GP36-GP39 are verified (2026-09-29,
  `firmware/README.md` "WiFi"). Firmware blinks LED2 on GP23; after
  flashing, check the LED blinks. Also confirm 16 MB flash on the module (no
  runtime JEDEC ID check exists; `PICO_FLASH_SIZE_BYTES` in
  `firmware/boards/picoco_plusw.h` is a build-time assumption, not verified
  against the part actually on the board).

### F.2 Per-build bring-up steps

1. Build and flash:
   - Pico 2: `cmake -B build-pico -G Ninja -DPICO_SDK_PATH=... firmware &&
     ninja -C build-pico`, then `flash.sh build-pico/picoco.uf2`.
   - Plus-W: same with `-DPICOCO_BOARD=plusw` into `build-pico-plusw`.
2. Power up with the cart seated; /HALT should hold (CoCo dead) until
   `log dump` shows `core1 up, halt released`.
3. `status`: check cycle counts are moving and `bus engine_stall 0`,
   `event_drop 0`, `event_lap 0`.
4. Becker loop, no ROM needed: `becker loop`, `bus drive on`, then on the
   CoCo `POKE &HFF42,65: PRINT PEEK(&HFF41), PEEK(&HFF41), PEEK(&HFF42)` →
   `0 2 65`.
5. `rom load <rom>` (see F.3 for which file), `save`, power-cycle: HDB-DOS
   boots, `DIR` lists the test disk, `LOADM"DINORUN":EXEC` runs it.
6. `SAVE` a program from BASIC, power-cycle, `DIR` still lists it.
7. `dw stats`: `crc_err 0` throughout.

### F.3 ROM notes

- CoCo 1 and CoCo 2: `hdbdw3bck.rom` (`rom load hdbdw3bck.rom`, then `save`).
  `hdbdw3bc3.rom` (bc3, 1.79 MHz during transfers) is CoCo 3 only.
- CoCo 1 needs Extended Color BASIC (not plain Color BASIC) for HDB-DOS to
  hook in.
- On CoCo 1/2, BASIC `PEEK(&HC000)` reaches the cart directly (unlike a
  CoCo 3, which runs BASIC from RAM) — they execute the DOS ROM as code from
  the cart, so an address-decode error crashes immediately instead of
  showing up as a stray PEEK. Watch `engine_stall` and `event_drop` closely
  on these two.
- Confirm the test disk image is readable from CoCo 1/2 DOS before blaming
  the hardware for a failed `DIR`.

### F.4 Through an MPI

- Set both the /CTS and /SCS slot-select switches to PiCoCo's slot.
- An unmodified Tandy 26-3024 MPI needs the CoCo 3 upgrade to work with a
  CoCo 3; a 26-3124 works as shipped.
- The MPI's own buffers add delay, so the CoCo 3 fast-mode (bc3) row through
  the MPI is the read path's timing-margin test.
- A working MPI row is also the first data point for the unverified /SLENB
  item in `docs/hardware-design.md` §9 (deferred to v2.4).
- Also try a second cart in another MPI slot, and switch PiCoCo between
  slots, to rule out a slot-specific fault.

### F.5 Test matrix

Rows: CoCo model / mode. Columns: board. Cells: pass/fail + date, or blank
until run.

| CoCo | Pico 2, bare | Pico 2, MPI | Plus-W, bare | Plus-W, MPI |
|---|---|---|---|---|
| CoCo 1 (`hdbdw3bck`) | | | | |
| CoCo 2 (`hdbdw3bck`) | electrical pass 2026-10-01 (section I); cart test ROM 55 min clean after the read-path fix (I.5); HDB-DOS not run, the 26-3026 has no ECB | | | |
| CoCo 3, 0.89 MHz (`hdbdw3bck`) | | | | |
| CoCo 3, 1.79 MHz (`hdbdw3bc3`) | | | | |

## G. WiFi (Plus-W)

Firmware 1.3, Plus-W build. Server: `picoco-host` on the Mac unless noted.

### G.1 Bare module over USB (no CoCo)

Run 2026-09-30, results in G.3 (scan, join, errors, fallback, SNTP).
`bus selftest net` is not supported by the PIO engine: it answers `err
bus selftest net: not supported by this engine`.

### G.2 On the PCB with a CoCo

- Boot hold with a real CoCo: HDB-DOS boots over WiFi with /HALT released at link-up.
- DIR and LOADM from DW4 over WiFi.
- DIR and LOADM from FujiNet-PC over WiFi (BoIP).
- Fallback with the server stopped: CoCo boots native after 10 s.
- Manager WiFi screen end to end (scan, PSK, server, mode, save).
- VSYS scope trace during a LOADM over WiFi, against the 300 mA cart budget.

### G.3 Results

| Check | Result | Date |
|---|---|---|
| G.1 join + DHCP + connect at boot | 5.3 s (`net up in 5327 ms`) | 2026-09-30 |
| G.1 OP_TIME round trip | 8-13 ms typical, worst 23-30 ms over 20 | 2026-09-30 |
| G.1 `bus selftest net` | pass (CPU loop, firmware 1.3). Not supported by the PIO engine (G.2 on a CoCo covers the transport) | 2026-09-30 |
| G.1 bad SSID / closed port / bad DNS name | `no such network` / `refused` / `dns failed`, ~10 retries in 22 s each | 2026-09-30 |
| G.1 server down at boot | `net failed (refused), native fallback` after 10 s; `becker net` re-arms | 2026-09-30 |
| G.1 `net scan` | 21 networks | 2026-09-30 |
| G.1 cold-boot SNTP seeding | pass 2026-09-30: after a USB power cycle the boot log shows `net: sntp seeded 1790778946`, `time` reports it with `clock kept`, `net up in 8329 ms` | |
| G.1 `net tz` (firmware 1.3, 25517de) | pass 2026-09-30: `net tz -240` + `save` + reboot logs `net: sntp set 1790765675 (utc 1790780075 tz -240)`, exactly Mac UTC minus 14400; `net tz 0` then `net tz -240` move `time` at once, no hourly wait | |
| G.1 reconnect after a Pico reboot with picoco-host (af12f4d) | pass 2026-09-30: the server replaces the stale client on the new accept; `bus selftest net` passes right after the reboot (dwinit 5 ms, worst 19 ms) without restarting the server. `bus selftest net` is not supported by the PIO engine | |
| G.2 boot hold with CoCo | | |
| G.2 DIR/LOADM from DW4 | | |
| G.2 DIR/LOADM from FujiNet-PC | | |
| G.2 fallback, server stopped | | |
| G.2 manager WiFi screen | | |
| G.2 VSYS scope trace | | |

## H. NitrOS-9 over Becker

CoCo 3 only (Level 2). Two disks, easiest first: a stock NitrOS-9 Becker
boot floppy served from flash, then Ease of Use (EOU) from a server.
NitrOS-9 L2 runs the CoCo 3 at 1.79 MHz, so every row here is also a
fast-mode Becker test whichever HDB-DOS ROM started it.

### H.0 What is needed

- **CPU match.** The EOU zip in the repo root is the 6309-only build. On a
  stock 68B09E CoCo 3 it will not boot; that needs the 6809
  build (`68SDC.VHD`) instead. Same rule for the stock disk (`6809l2` vs
  `6309l2`).
- **512 K RAM** for EOU. The stock disk runs in 128 K.
- **Stock disk:** a `*coco3_becker.dsk` from a NitrOS-9 release (here
  `nos96309l2v030300coco3_becker.dsk`; the `_headless` variant puts the
  console on a DriveWire virtual terminal and is not wanted). Its kernel track carries
  `boot_dw_becker` and `/DD` is `/X0`, so it boots with nothing but
  DriveWire. Small enough for the flash filesystem on either board.
- **EOU:** `63SDC.VHD` (or `68SDC.VHD`) does **not** boot on PiCoCo as
  shipped: its kernel track is `boot_sdc` and every boot set has the CoCo
  SDC as `/DD`; `OS9Boot.dw` uses the bitbanger `dwio`. `63EMU.DSK` is the
  emulator hard-disk boot and has no DriveWire at all. Everything for a
  Becker boot is on the VHD, so H.1 remasters it.
- **EOU needs a server.** The VHD is 128 MB; the flash filesystem is 2.5 MB
  (Pico 2) or 14.5 MB (Plus-W). Serve it from `picoco-host` over
  `becker bridge` + `tools/becker_relay.py` (either board) or `becker net`
  (Plus-W). Round trip must stay under 200 ms.

### H.1 Prep: EOU Becker image

`python3 firmware/tools/eou_becker.py 63SDC.VHD 63BECKER.VHD` (needs
toolshed `os9`). It copies the image, then:

- Kernel track (LSN 612): `KERNEL_TRACKS/kernel.dw` with `Boot` swapped for
  `boot_dw_becker`.
- Boot file: `BOOTS/OS9Boot.dw` with `dwio` -> `dwio_becker.sb`, `DD` ->
  `ddx0.dd`, and `RBSuper`, `llcocosdc`, `H1` removed (the SDC registers
  overlap the Becker port at `$FF41/$FF42`). Written over `OS9Boot.dw`'s
  own extent (`os9 gen` fragments a new file there) and LSN 0
  `DD.BT`/`DD.BSZ` pointed at it.

So SWAPBOOT's "dw" set is now the Becker one; picking any other set
un-does the boot pointer (re-run the script).

**HDB-DOS translation must be off before `DOS`** on any hard-disk image:
`picoco-host --hdbdos off`, or `dw hdbdos off` for a native mount. The
NitrOS-9 Boot module sends no DWINIT, and with translation on its boot-file
reads (LSN 47253 here) resolve to an unmounted drive 75: the screen shows
`KREL Boot Krn tb0....bt*j` then `NITROS9 6309 FAILED`, and the server
counts `notrdy`. The stock floppy is unaffected (everything below LSN 630).

### H.2 Emulator gate (no hardware)

1. `./build-host/picoco-host --dir <dir> --mount 0=<image> --hdbdos off`
   (pick another `--port` if 65504 is taken, and match `-becker-port`).
2. `xroar -machine coco3 -machine-cpu 6309 -ram 512 -cart becker
   -becker-ip 127.0.0.1 -becker-port 65504 -cart-rom firmware/roms/hdbdw3bc3.rom
   -type 'DOS\r'` (drop `-machine-cpu` for a 6809 image).
3. Pass: stock disk reaches the shell prompt; EOU reaches its banner with
   `DriveWire - (Installed) (Active)`. `Ctrl-C` on `picoco-host`: no CRC
   errors, `notrdy=0`.

`picoco-host` answers OP_TIME with Mac local time (since 2026-10-01; the
XRoar runs above predate that and stopped at EOU's `Time ?` prompt).

### H.3 Stock disk on the CoCo (native, from flash)

`fs export`, copy the `.dsk`, `fs import`, `dw mount 0 <file>`, then:

1. `DOS` from HDB-DOS: "NITROS9 BOOT", module list, shell prompt.
   `status`: `crc_err 0`, `becker underrun 0`, `dw hdbdos off` (DWINIT
   cleared it).
2. `date -t` matches the Pico's `time` (Clock2 over OP_TIME).
3. `dir -e /dd`; `dir /x1` with a second image on drive 1.
4. Write: `copy /dd/startup /dd/t1`, `list /dd/t1`, `del /dd/t1`. `status`
   writes count moves, no error; file survives a reboot if left in place.
5. `dw disk show` inside NitrOS-9 lists the mounts (virtual channel,
   `dw_vser.c`); `dw disk insert 1 <file>` then `dir /x1`.
6. Tick loss (`docs/ADDITIONAL_ROADMAP.md` §5 item 2): note `date -t`, run
   `dir -e -r /dd >/nil` in a loop for 10 minutes, compare with the Pico's
   `time`. Record the drift in seconds.
7. CoCo RESET returns to HDB-DOS and `DOS` boots again; same after a
   power cycle with `dw mount` saved in `picoco.cfg`.
8. Manager: `B` on the OS-9 disk boots it (never bench-tested; the plan
   skipped it for lack of a disk).

### H.4 EOU on the CoCo (served)

Transport per H.0; `picoco-host --mount 0=63BECKER.VHD --hdbdos off`.

1. `DOS`: boots to the EOU prompt; `startup` loads all fonts with no
   retry stall. Record the boot time.
2. `date -t` matches the server (with `picoco-host`: answer `Time ?` by
   hand, see H.2); `free /dd` and `dir -e /dd/cmds` work.
3. `gshell`: desktop draws, mouse or keyboard moves, launch one app and
   quit back.
4. Write: copy a >100 K file, `dcheck /dd` reports no errors.
5. 30-minute soak in gshell with a second window running `dir -e -r /dd`:
   `status` still `crc_err 0`, `underrun 0`; relay or `net status` shows
   no reconnect.
6. `swapboot` runs and lists the sets; quit without selecting (only the
   current boot works here, see H.1).
7. Plus-W: repeat 1, 2 and 5 over `becker net`.

Not in scope until the sound/MIDI work lands: `/MIDI`, `/P`, `/N` channels.

### H.5 Results

Firmware fixes that came out of this section (2026-10-01), details in
`docs/pcb-bringup.md` "NitrOS-9 bring-up":
- core1 Pico 2 read path: latch preloaded during idle, one store on OE_BUS
  low; pad discharge after every cycle. Sector checksum failures over the
  bridge went from 80 in 1,966 to 1 in 1,888 on an EOU boot.
- DriveWire server drops the CoCo SDC probe (`64 64 00 64 00 ...` on `$FF42`).
- Bridge mode holds the CoCo's bytes until CDC0 has a listener (HDB-DOS
  reads drive 0 at power-on with no timeout).
- `bus selftest` on a bare Pico 2 (chip rev A2), six runs in one boot, all
  pass: read answered ~139-146 ns after OE_BUS falls from idle (the
  2026-09-30 loop measured 264-286 ns with the same sweep, budget 230),
  256-286 ns back to back, 366-396 ns straight after a write.
- RP2350-E9 confirmed on that Pico: D0-D7 driven high then released onto the
  internal pull-downs still read `ff` after 51 ms; driven low then released
  read `00` (`selftest pad_hold` line).
- `bus selftest` on a bare Plus-W (chip rev A4), three fresh boots, all
  pass with the ported loop (latch preload at Q time, pad discharge):
  response 132 ns after E rises, burst 381 ns (old loop 139-154 / 352-366).
  `pad_hold` reads `00`: no E9 on A4.
- Open: Plus-W on a PCB with a CoCo (section G.2 and F.5), including a
  scope look at JP2 2-3; a second `bus selftest` in one boot fails
  `read_bank0_marker` on the Plus-W (old loop too).
  Closed 2026-10-02: the JP2 2-3 scope look is moot (the PIO engine needs
  JP2 at 1-2), and `read_bank0_marker` went with the old self-test.

Bench CoCo 3 CPU: 6309  RAM: 2 MB

| Check | Pico 2 | Plus-W | Date |
|---|---|---|---|
| H.1 EOU Becker image built | n/a | n/a | 2026-10-01: `63BECKER.VHD`, 64 modules, boot file 35361 bytes at LSN 47253 |
| H.2 XRoar, stock disk | n/a | n/a | pass 2026-10-01: shell prompt (6309, hdbdw3bc3) |
| H.2 XRoar, EOU | n/a | n/a | pass 2026-10-01 to the `Time ?` prompt: 512k, 6309 native, DriveWire active; `reads=1383 crc_err=0 notrdy=0`. gshell not run |
| H.3.1 stock boot | pass 2026-10-01 after the E9 discharge fix in `bus_core1.c`: shell prompt, `dw reads 308 crc_err 0`, `becker reads 79457 underrun 0`, `dw hdbdos off`. Before the fix: hung at `i2x`, underrun 1, crc_err 84 (phantom byte after a `$26` write) | | 2026-10-01 |
| H.3.2 clock | pass: startup prints the 2014 build date (before the first OP_TIME is applied), `date -t` then shows 2026-10-01 10:38:51 matching the Pico | | 2026-10-01 |
| H.3.3 read, two drives | `dir -e /dd` pass; `/x1` not run | | 2026-10-01 |
| H.3.4 write | pass: copy, list, del; `dw reads 364 writes 16 crc_err 0`, `underrun 0` | | 2026-10-01 |
| H.3.5 `dw` utility | | | |
| H.3.6 tick loss in 10 min | | | |
| H.3.7 reset / power cycle | RESET inside NitrOS-9 restarts the NitrOS-9 boot, not HDB-DOS; power cycle returns to HDB-DOS (mounts need `save`) | | 2026-10-01 |
| H.3.8 manager `B` | | | |
| H.3 through an MPI | | | |
| H.4.1 EOU boot (bridge) | pass 2026-10-01 (third try): 2048k, 6309 native, boots to the prompt; 2409 sectors, 21 re-read after a checksum failure (0.9 %, open). Needed: the server dropping EOU's SDC probe (`64 64 00 64 00 ...` on `$FF42`), `COCO3FPGA=1` in the image. Still prompts for the time: root `startup` is the `.sdc` one | | 2026-10-01 |
| H.4.2-4 clock, gshell, write | gshell loads and launches apps (trackpad), no time prompt with the `.dw` startup, saved `becker bridge` survives a power cycle; ~7935 sectors, 42 re-reads (0.5 %, open), 0 phantom reads. `dcheck` not run | | 2026-10-01 |
| H.4.5 30 min soak | pass: copy + `dcheck /dd` + del over the bridge, no reconnect, no phantom reads. dcheck reports 117 lost and 129 shared clusters: both are in the untouched `63SDC.VHD` as shipped (kernel track, old boot extents; 5 files with two directory entries), so no damage from this session | | 2026-10-01 |
| H.4.6 swapboot | | | |
| EOU boot after the read-path rework | 1 re-read in 1,888 sectors (was 80 in 1,966), `oe_glitch 0`, `addr_resample` 70,314 of 1.3 M reads, `underrun 52` (all the SDC probe) | | 2026-10-01 |
| Re-sample before recompute (final build, 370603b) | EOU boot: 0 re-reads in ~1,880 sectors, `addr_resample 0` in 1.3 M reads, `oe_glitch 0`, `underrun 52` (the SDC probe) | | 2026-10-01 |
| H.4.7 EOU over WiFi | n/a | | |

## I. CoCo 2 (PCB v2.3.1 #1, Pico 2)

First run on a machine that executes the DOS ROM straight from the cart:
a CoCo 3 copies `$C000-$FEFF` to RAM once at boot, a CoCo 2 fetches every
HDB-DOS opcode through U10 at 0.89 MHz. One wrong ROM read crashes instead
of showing up as a retry. Bare slot only; the MPI rows stay in F.4.

### I.0 Before the board goes in (USB only, no CoCo)

The config saved after section H is wrong for a CoCo 2. Fix it first:

1. `status`: note `rom next` and the `becker` mode.
2. `becker native`. A saved `becker bridge` holds the CoCo at power-on
   until CDC0 has a listener.
3. `rom load hdbdw3bck.rom`. `hdbdw3bc3` pokes `$FFD9`, which on a CoCo 2 is
   the SAM rate bit: 1.79 MHz on a machine that cannot run it.
4. `dw mount 0 DINORUN.DSK`, `dw hdbdos on`, `bus drive on`, `save`,
   `reboot`, `status` again: `rom now hdbdw3bck.rom`, `becker` native.
5. Record the CoCo 2 in I.4: model number (26-3026/3027, 26-3127, 26-3134
   ...), RAM (16K/64K), BASIC versions from the power-on banner without the
   cart. Extended BASIC is required; 16K is enough for HDB-DOS but not for
   the manager or DINORUN.
6. Optional emulator pre-check, same ROM and disk:
   `xroar -machine coco2bus -becker -rompath ~/.xroar/roms` against
   `picoco-host` (`coco/README.md`).

### I.1 Boot and ROM path

CoCo off, board in, USB to the Mac, CoCo on.

1. Banner `HDB-DOS 1.5 BECKER COCO 2` over `EXTENDED COLOR BASIC`.
   `log dump` has `core1 up, halt released`. No banner: `status` first
   (cycles moving? `engine_stall`, `event_drop`), then TP1/TP5 on the scope.
2. `PRINT PEEK(&HC000);PEEK(&HC001)` → `68 75` ("DK"). On a CoCo 2 this
   reads the cart itself.
3. ROM checksum from BASIC, twice, same number both times:
   `S=0:FOR A=&HC000 TO &HDFFF:S=S+PEEK(A):NEXT:PRINT S`
   Expected `903857` (byte sum of `firmware/roms/hdbdw3bck.rom`). Takes
   about a minute.
4. `status`: `engine_stall 0`, `event_drop 0`, `event_lap 0`. (The
   2026-10-01 row below used the CPU loop's counters.)

### I.2 Becker and DriveWire

1. `POKE &HFF42,65:PRINT PEEK(&HFF41);PEEK(&HFF41);PEEK(&HFF42)` under
   `becker loop` → `0 2 65`; back to `becker native` after.
2. `DIR`, `LOADM"DINORUN":EXEC`, a `SAVE` + power cycle + `DIR`.
3. `DRIVE 3:RUN"PICOCO"`: manager draws in uppercase (no inverse-video
   garbage), E/N/V/S/B keys work, BREAK exits. First real-hardware run of
   the CoCo 2 path; only XRoar so far.
4. `status` / `dw stats`: `crc_err 0`, `underrun 0`, `event_drop 0`.
5. Soak: `10 DIR:GOTO 10` for 10 minutes, counters unchanged.

### I.3 Reset and power

1. RESET button: Pico reboots, HDB-DOS banner returns.
2. Cold power cycle with USB unplugged, five times: banner every time
   (the /HALT hold against a different power-on reset circuit).
3. `+5V` at the cart (TP or pad 39) with the board running: record it. The
   CoCo 2 supply is the weakest of the three.

Not in scope today: MPI, Plus-W board, NitrOS-9 Level 1 (needs 64K and a
`nos96809l1...coco1_becker.dsk`), 1.79 MHz (CoCo 3 only).

### I.4 Results

CoCo 2 model: 26-3026  RAM: 16K (`PRINT MEM` 14631)  BASIC: Color BASIC 1.2  ECB: none

No Extended BASIC, so HDB-DOS cannot start on this machine (only ECB looks
for `DK` at `$C000`): I.1.1 is the plain Color BASIC banner, and I.2.2-I.2.5
wait for an ECB ROM or another CoCo 2. Color BASIC has no `&H`; the decimal
forms are `PEEK(49152)`, `FOR A=49152 TO 57343`, `POKE 65346,65`,
`PEEK(65345)`, `PEEK(65346)`.

| Check | Result | Date |
|---|---|---|
| I.0 config: bck ROM, native, DINORUN on drive 0 | done: firmware 1.3; saved config had `hdbdw3bc3.rom` (mode already native), now `rom now load hdbdw3bck.rom`, drive 0 DINORUN.DSK, drive 3 PICOCO.DSK, `bus drive on`, `dw hdbdos on` after reboot | 2026-10-01 |
| I.1.1 banner, halt released | pass: `COLOR BASIC 1.2` banner and `OK` with the cart in (no HDB-DOS, see above); `core1 up, halt released` at 2.7 s | 2026-10-01 |
| I.1.2 `PEEK(&HC000)` = 68 75 | pass: `68 75` four times. One earlier `68 196` not reproduced (49193 holds 196; taken as a typo) | 2026-10-01 |
| I.1.3 ROM checksum x2 | pass: `903857` twice | 2026-10-01 |
| I.1.4 `addr_resample` / `oe_glitch` / `late_precompute` | 0 / 0 / 0; `bus reads 8205 writes 2`, exactly the PEEKs and POKEs typed (Color BASIC never touches the cart on its own) | 2026-10-01 |
| I.2.1 Becker loop `0 2 65` | pass | 2026-10-01 |
| I.2.2 DIR / LOADM / SAVE | | |
| I.2.3 manager | | |
| I.2.5 10 min DIR soak | | |
| I.3.1 RESET | pass: CoCo back to `OK`, Pico rebooted (uptime restarted, counters zeroed, `core1 up, halt released` at 2.7 s) | 2026-10-01 |
| I.3.2 cold boot x5, no USB | pass: banner and `OK` five of five; `PEEK(49152)`/`(49153)` = `68 75` on cart power alone | 2026-10-01 |
| I.3.3 +5V at the cart | pass: module pad 39 (VSYS, after D2) 4.8 V, TP6 3.27 V, measured against TP8. No +5V test point; finger 9 is inside the slot | 2026-10-01 |

### I.5 Without Extended BASIC: the cart test ROM

`coco/carttest.asm` (`make -C coco carttest.rom`, 8 KB) stands in for
HDB-DOS on a machine with no ECB. It runs from the cart, so every opcode is
a ROM read, and reads drive 0 LSN 0-629 with DriveWire OP_READ in a loop.

1. Copy `carttest.rom` to the flash volume (`fs export` / `fs import`),
   `rom load carttest.rom`. Never swap the ROM under a running test: power
   the CoCo off first (RESET is a warm start and keeps scribbled RAM).
2. Sum to expect, from the copy on the board (it changes with every SAVE):
   `python3 -c "print('%04X' % (sum(open('/Volumes/PICOCO/DINORUN.DSK','rb').read()) & 0xFFFF))"`
   while the volume is exported.
3. `EXEC 49152`. One line per pass (~14 s): `PASS nnnn SUM ssss ERR eeee`.
   A bad sector prints `Ecc llll` and the test carries on after a 0.5 s
   quiet wait. Any key stops it within one sector (a warm restart, back to BASIC).
4. `status` after: `underrun 0`, `engine_stall 0`, `event_drop 0`,
   `dw stats` clean. `trace dump` is frozen at the first underrun.
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

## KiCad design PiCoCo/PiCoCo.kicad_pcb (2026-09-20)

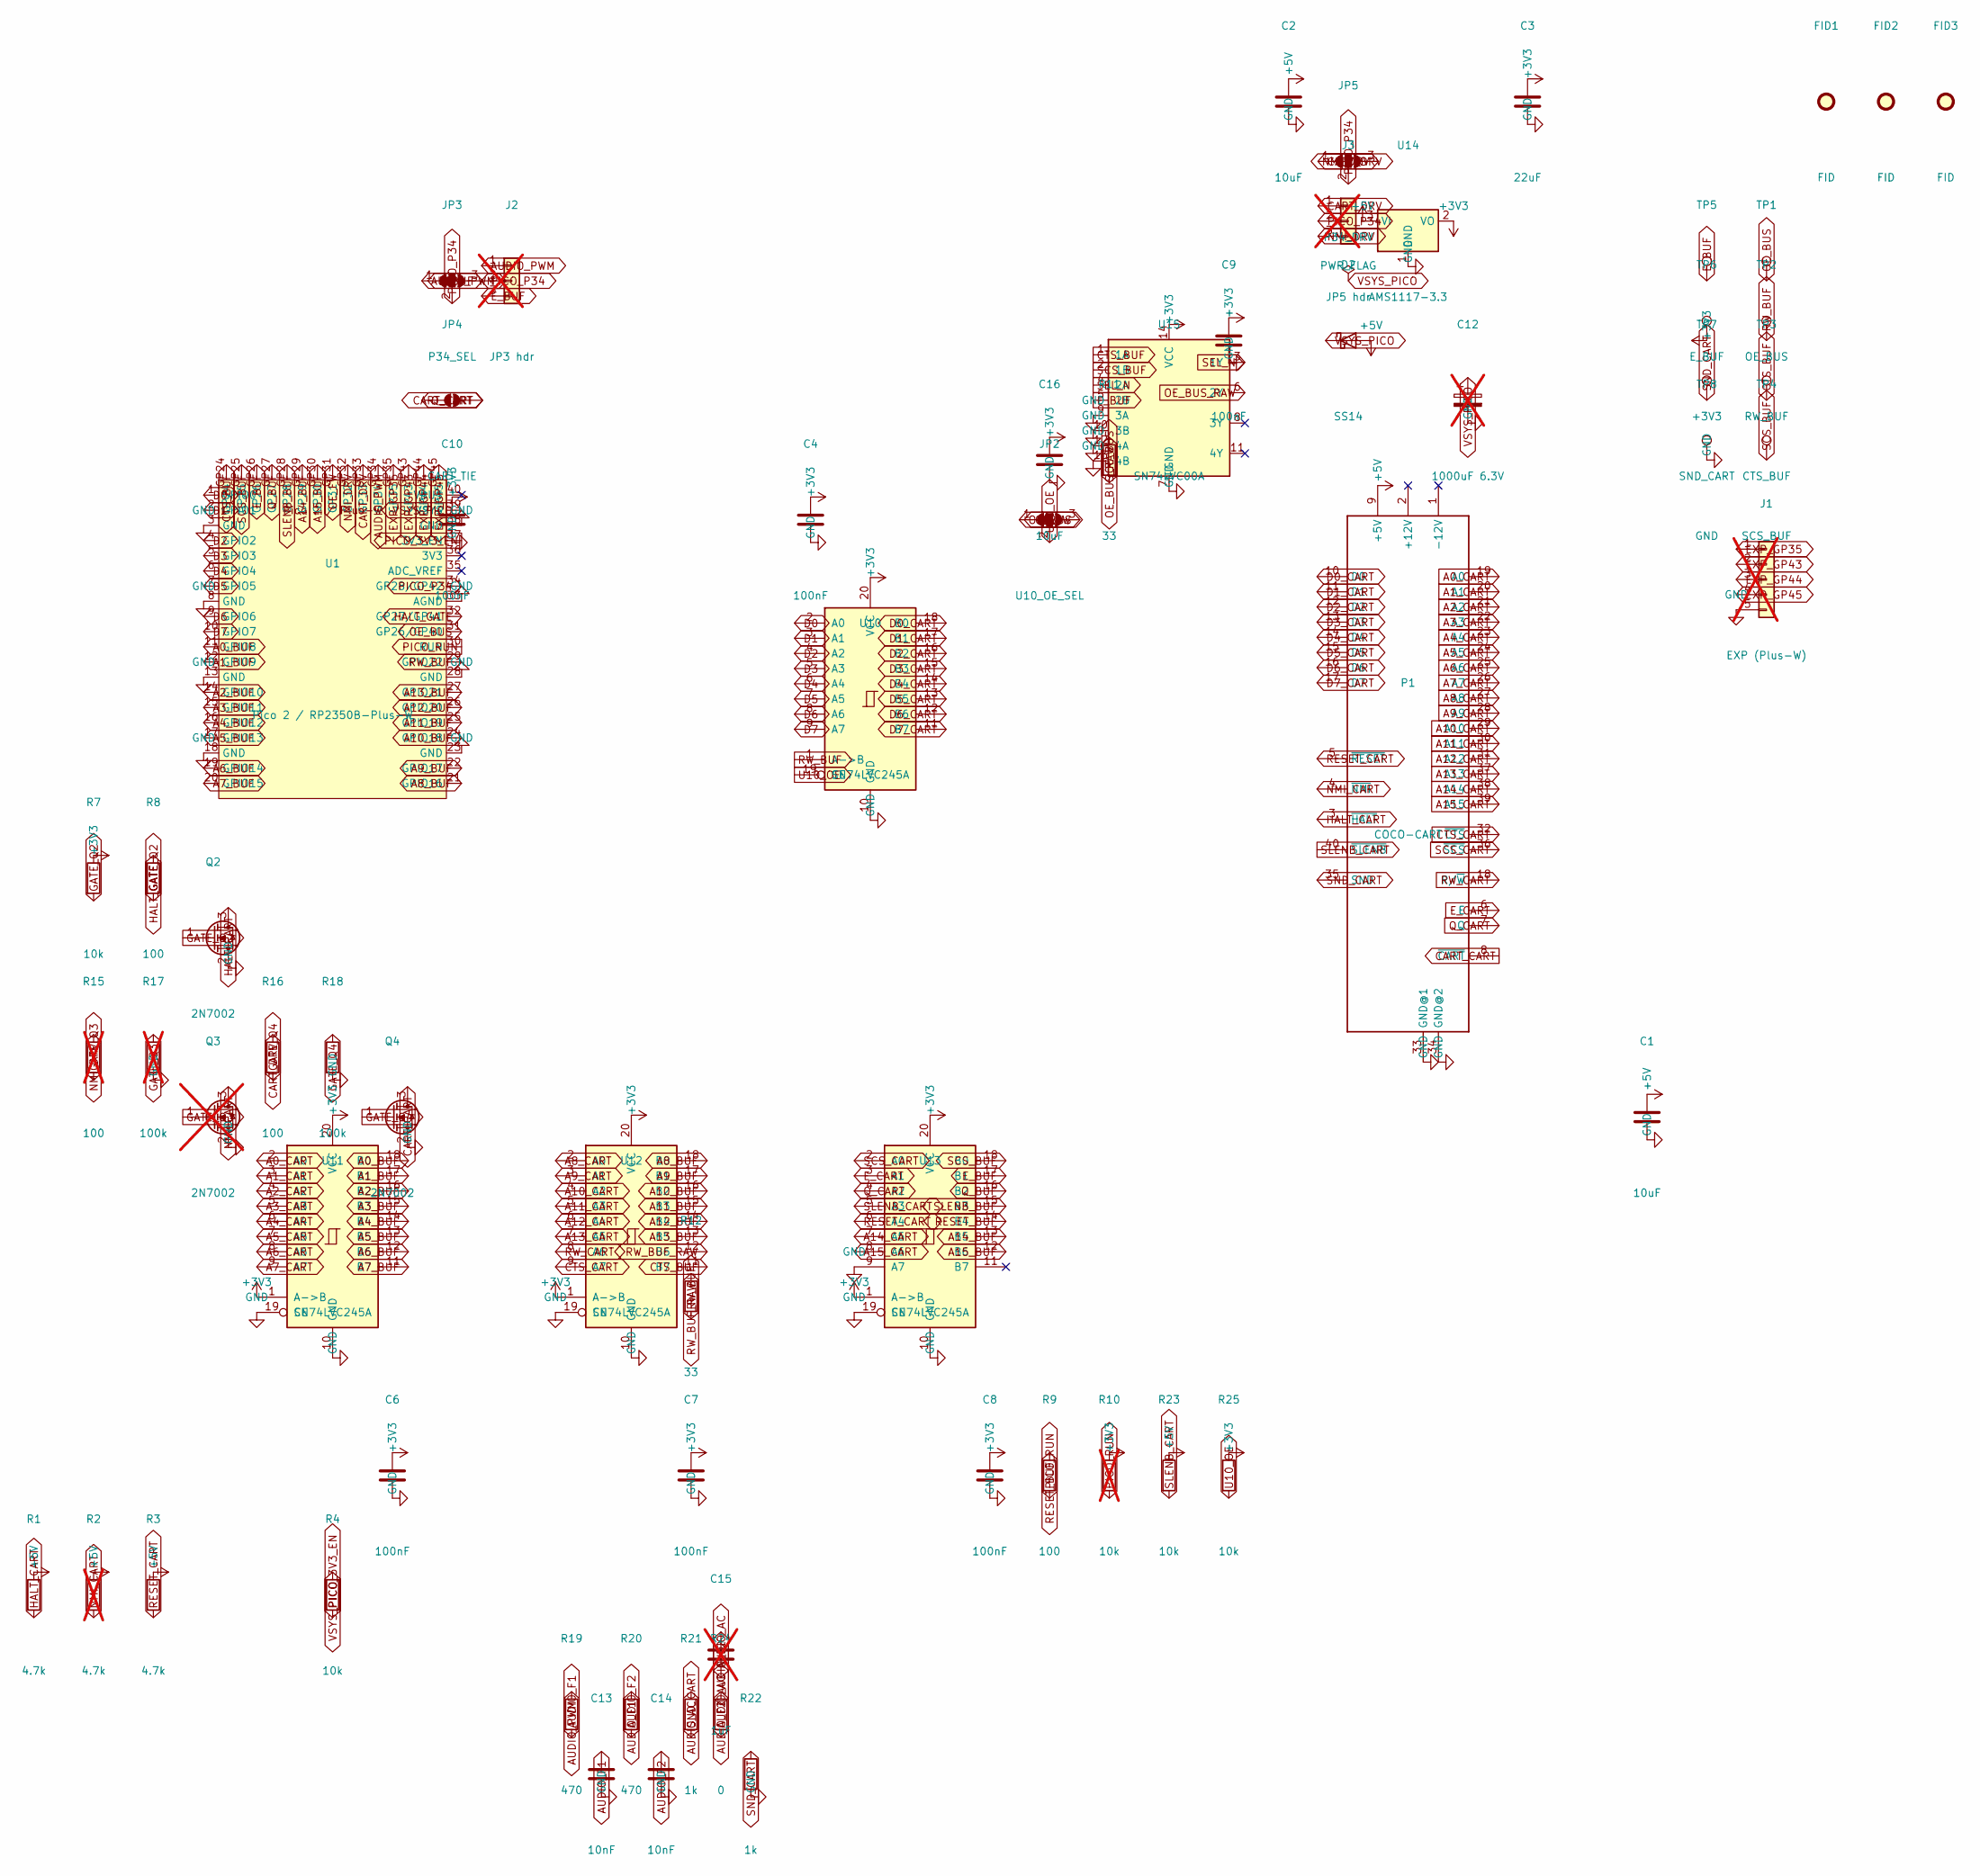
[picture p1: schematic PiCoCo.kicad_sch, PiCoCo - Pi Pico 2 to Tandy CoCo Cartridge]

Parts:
C1, C2, C16: 10uF; C_0805_2012Metric; MPN 0805 10uF; LCSC C15850
C3: 22uF; C_0805_2012Metric; MPN 0805 22uF; LCSC C45783
C4, C6, C7, C8, C9, C10: 100nF; C_0805_2012Metric; MPN 0805 100nF; LCSC C49678
C12: 1000uF 6.3V; CP_Elec_8x10; MPN 1000uF 6.3V SMD electrolytic D8x10; not fitted
C13, C14: 10nF; C_0805_2012Metric; MPN 0805 10nF; LCSC C1710
C15: 1uF; C_0805_2012Metric; MPN 0805 1uF; LCSC C28323; not fitted
D2: SS14; D_SMA; MPN SS14; LCSC C2480
FID1, FID2, FID3: FID; Fiducial_1mm_Mask2mm
J1: EXP (Plus-W); PinHeader_1x05_P2.54mm_Vertical; not fitted
J2: JP3 hdr; PinHeader_1x03_P2.54mm_Vertical; not fitted
J3: JP5 hdr; PinHeader_1x03_P2.54mm_Vertical; not fitted
JP2: U10_OE_SEL; SolderJumper-3_P1.3mm_Bridged12_RoundedPad1.0x1.5mm
JP3: P34_SEL; SolderJumper-3_P1.3mm_Bridged12_RoundedPad1.0x1.5mm
JP4: CART_TIE; SolderJumper-2_P1.3mm_Open_RoundedPad1.0x1.5mm
JP5: P34_DRV; SolderJumper-3_P1.3mm_Open_RoundedPad1.0x1.5mm
P1: COCO-CART; COCO-CART-2.1X1.75
Q2, Q4: 2N7002; SOT-23; MPN 2N7002; LCSC C8545
Q3: 2N7002; SOT-23; MPN 2N7002; LCSC C8545; not fitted
R1, R3: 4.7k; R_0805_2012Metric; MPN 0805 4.7k 1%; LCSC C17673
R2: 4.7k; R_0805_2012Metric; MPN 0805 4.7k 1%; LCSC C17673; not fitted
R4, R7, R23, R25: 10k; R_0805_2012Metric; MPN 0805 10k 1%; LCSC C17414
R8, R9, R16: 100; R_0805_2012Metric; MPN 0805 100 1%; LCSC C17408
R10: 10k; R_0805_2012Metric; MPN 0805 10k 1%; LCSC C17414; not fitted
R11, R12: 33; R_0805_2012Metric; MPN 0805 33 1%; LCSC C17634
R15: 100; R_0805_2012Metric; MPN 0805 100 1%; LCSC C17408; not fitted
R17: 100k; R_0805_2012Metric; MPN 0805 100k 1%; LCSC C149504; not fitted
R18: 100k; R_0805_2012Metric; MPN 0805 100k 1%; LCSC C149504
R19, R20: 470; R_0805_2012Metric; MPN 0805 470 1%; LCSC C17710
R21, R22: 1k; R_0805_2012Metric; MPN 0805 1k 1%; LCSC C17513
R24: 0; R_0805_2012Metric; MPN 0805 0 1%; LCSC C17477
TP1: OE_BUS; TestPoint_Pad_1.0x1.0mm
TP2: RW_BUF; TestPoint_Pad_1.0x1.0mm
TP3: CTS_BUF; TestPoint_Pad_1.0x1.0mm
TP4: SCS_BUF; TestPoint_Pad_1.0x1.0mm
TP5: E_BUF; TestPoint_Pad_1.0x1.0mm
TP6: +3V3; TestPoint_Pad_1.0x1.0mm
TP7: SND_CART; TestPoint_Pad_1.0x1.0mm
TP8: GND; TestPoint_Pad_1.0x1.0mm
U1: Pico 2 / RP2350B-Plus-W; Pico-Carrier
U10, U11, U12, U13: SN74LVC245A; SOIC-20W_7.5x12.8mm_P1.27mm; MPN SN74LVC245ADWR; LCSC C571201
U14: AMS1117-3.3; SOT-223-3_TabPin2; MPN AMS1117-3.3; LCSC C6186
U15: SN74LVC00A; SOIC-14_3.9x8.7mm_P1.27mm; MPN SN74LVC00ADR; LCSC C485072

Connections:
+3V3: C3.1, C4.1, C6.1, C7.1, C8.1, C9.1, C10.1, C16.1, R7.1, R10.1, R25.1, TP6.1 (1_1), U10.20 (VCC), U11.1 (A->B), U11.20 (VCC), U12.1 (A->B), U12.20 (VCC), U13.1 (A->B), U13.20 (VCC), U14.2 (VO), U15.14 (VCC)
+5V: C1.1, C2.1, D2.2 (A), P1.9 (+5V), R1.1, R2.1, R3.1, R23.1, U14.3 (VI)
A0_BUF: U1.11 (GPIO8), U11.18 (B0)
A0_CART: P1.19 (A0), U11.2 (A0)
A1_BUF: U1.12 (GPIO9), U11.17 (B1)
A1_CART: P1.20 (A1), U11.3 (A1)
A2_BUF: U1.14 (GPIO10), U11.16 (B2)
A2_CART: P1.21 (A2), U11.4 (A2)
A3_BUF: U1.15 (GPIO11), U11.15 (B3)
A3_CART: P1.22 (A3), U11.5 (A3)
A4_BUF: U1.16 (GPIO12), U11.14 (B4)
A4_CART: P1.23 (A4), U11.6 (A4)
A5_BUF: U1.17 (GPIO13), U11.13 (B5)
A5_CART: P1.24 (A5), U11.7 (A5)
A6_BUF: U1.19 (GPIO14), U11.12 (B6)
A6_CART: P1.25 (A6), U11.8 (A6)
A7_BUF: U1.20 (GPIO15), U11.11 (B7)
A7_CART: P1.26 (A7), U11.9 (A7)
A8_BUF: U1.21 (GPIO16), U12.18 (B0)
A8_CART: P1.27 (A8), U12.2 (A0)
A9_BUF: U1.22 (GPIO17), U12.17 (B1)
A9_CART: P1.28 (A9), U12.3 (A1)
A10_BUF: U1.24 (GPIO18), U12.16 (B2)
A10_CART: P1.29 (A10), U12.4 (A2)
A11_BUF: U1.25 (GPIO19), U12.15 (B3)
A11_CART: P1.30 (A11), U12.5 (A3)
A12_BUF: U1.26 (GPIO20), U12.14 (B4)
A12_CART: P1.31 (A12), U12.6 (A4)
A13_BUF: U1.27 (GPIO21), U12.13 (B5)
A13_CART: P1.37 (A13), U12.7 (A5)
A14_BUF: U1.GP29, U13.13 (B5)
A14_CART: P1.38 (A14), U13.7 (A5)
A15_BUF: U1.GP30, U13.12 (B6)
A15_CART: P1.39 (A15), U13.8 (A6)
AUDIO_AC: C15.2, R21.1, R24.2
AUDIO_F1: C13.1, R19.2, R20.1
AUDIO_F2: C14.1, C15.1, R20.2, R24.1
AUDIO_PWM: J2.1, JP3.1 (A), R19.1, U1.GP34
CART_CART: JP4.2 (B), P1.8 (~CART), Q4.3 (D)
CART_DRV: J3.1, JP5.1 (A), R16.1, U1.GP33
CTS_BUF: TP3.1 (1_1), U1.GP24, U12.11 (B7), U15.1 (1A)
CTS_CART: P1.32 (~CTS), U12.9 (A7)
D0: U1.1 (GPIO0), U10.2 (A0)
D0_CART: P1.10 (D0), U10.18 (B0)
D1: U1.2 (GPIO1), U10.3 (A1)
D1_CART: P1.11 (D1), U10.17 (B1)
D2: U1.4 (GPIO2), U10.4 (A2)
D2_CART: P1.12 (D2), U10.16 (B2)
D3: U1.5 (GPIO3), U10.5 (A3)
D3_CART: P1.13 (D3), U10.15 (B3)
D4: U1.6 (GPIO4), U10.6 (A4)
D4_CART: P1.14 (D4), U10.14 (B4)
D5: U1.7 (GPIO5), U10.7 (A5)
D5_CART: P1.15 (D5), U10.13 (B5)
D6: U1.9 (GPIO6), U10.8 (A6)
D6_CART: P1.16 (D6), U10.12 (B6)
D7: U1.10 (GPIO7), U10.9 (A7)
D7_CART: P1.17 (D7), U10.11 (B7)
EXP_GP35: J1.1, U1.GP35
EXP_GP43: J1.2, U1.GP43
EXP_GP44: J1.3, U1.GP44
EXP_GP45: J1.4, U1.GP45
E_BUF: J2.3, JP3.3 (B), TP5.1 (1_1), U1.GP26, U13.17 (B1), U15.5 (2B)
E_CART: P1.6 (E), U13.3 (A1)
GATE_Q2: Q2.1 (G), R7.2, R8.2
GATE_Q3: Q3.1 (G), R15.2, R17.1
GATE_Q4: Q4.1 (G), R16.2, R18.1
GND: C1.2, C2.2, C3.2, C4.2, C6.2, C7.2, C8.2, C9.2, C10.2, C12.2, C13.2, C14.2, C16.2, J1.5, P1.33 (GND@1), P1.34 (GND@2), Q2.2 (S), Q3.2 (S), Q4.2 (S), R17.2, R18.2, R22.2, TP8.1 (1_1), U1.3 (GND), U1.8 (GND), U1.13 (GND), U1.18 (GND), U1.23 (GND), U1.28 (GND), U1.33 (AGND), U1.38 (GND), U10.10 (GND), U11.10 (GND), U11.19 (CE), U12.10 (GND), U12.19 (CE), U13.9 (A7), U13.10 (GND), U13.19 (CE), U14.1 (GND), U15.7 (GND), U15.9 (3A), U15.10 (3B), U15.12 (4A), U15.13 (4B)
HALT_CART: P1.3 (~HALT), Q2.3 (D), R1.2
HALT_GATE: R8.1, U1.32 (GP27/GP41)
NMI_CART: P1.4 (~NMI), Q3.3 (D), R2.2
NMI_DRV: J3.3, JP5.3 (B), R15.1, U1.GP32
OE_BUS: JP2.1 (A), R11.2, TP1.1 (1_1), U1.31 (GP26/GP40)
OE_BUS_RAW: R11.1, U15.6 (2Y)
OE_FW: JP2.3 (B), U1.GP31
PICO_3V3_EN: R4.2, U1.37 (3V3_EN)
PICO_P34: J2.2, J3.2, JP3.2 (C), JP5.2 (C), U1.34 (GP28/GP42)
PICO_RUN: R9.2, R10.2, U1.30 (RUN)
Q_BUF: U1.GP27, U13.16 (B2)
Q_CART: JP4.1 (A), P1.7 (Q), U13.4 (A2)
RESET_BUF: R9.1, U13.14 (B4)
RESET_CART: P1.5 (~RESET), R3.2, U13.6 (A4)
RW_BUF: R12.2, TP2.1 (1_1), U1.29 (GPIO22), U10.1 (A->B)
RW_BUF_RAW: R12.1, U12.12 (B6)
RW_CART: P1.18 (R/~W), U12.8 (A6)
SCS_BUF: TP4.1 (1_1), U1.GP25, U13.18 (B0), U15.2 (1B)
SCS_CART: P1.36 (~SCS), U13.2 (A0)
SEL_N: U15.3 (1Y), U15.4 (2A)
SLENB_BUF: U1.GP28, U13.15 (B3)
SLENB_CART: P1.40 (~SLENB), R23.2, U13.5 (A3)
SND_CART: P1.35 (SND), R21.2, R22.1, TP7.1 (1_1)
U10_OE: JP2.2 (C), R25.2, U10.19 (CE)
VSYS_PICO: C12.1, D2.1 (K), R4.1, U1.39 (VSYS)

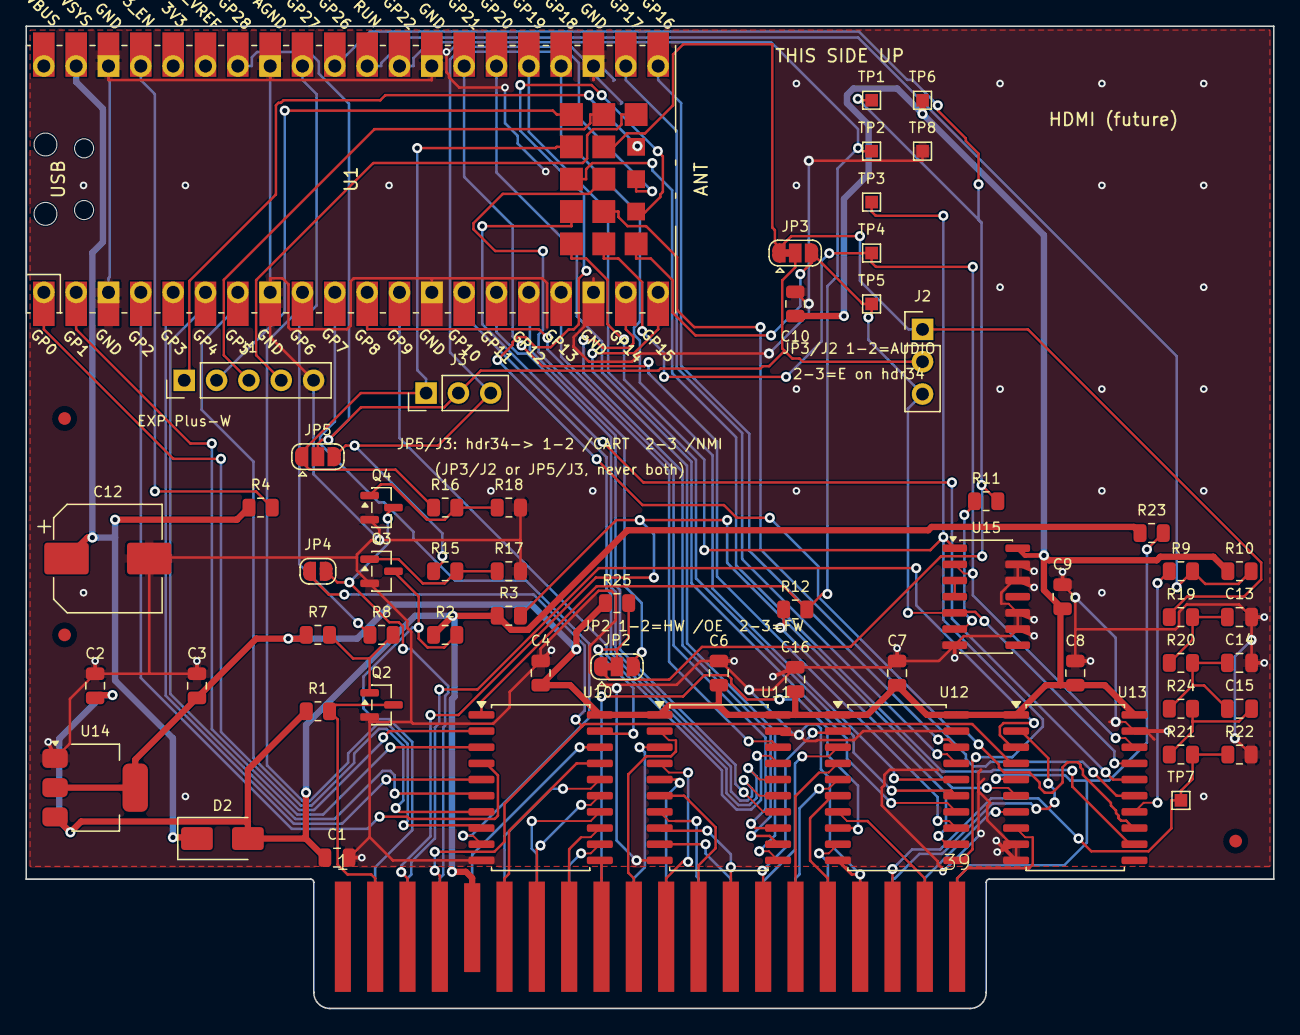
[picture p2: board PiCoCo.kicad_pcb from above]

Board: 2 copper layers, 98.0 x 77.2 mm, 65 parts (0 on the bottom side), 93 nets.

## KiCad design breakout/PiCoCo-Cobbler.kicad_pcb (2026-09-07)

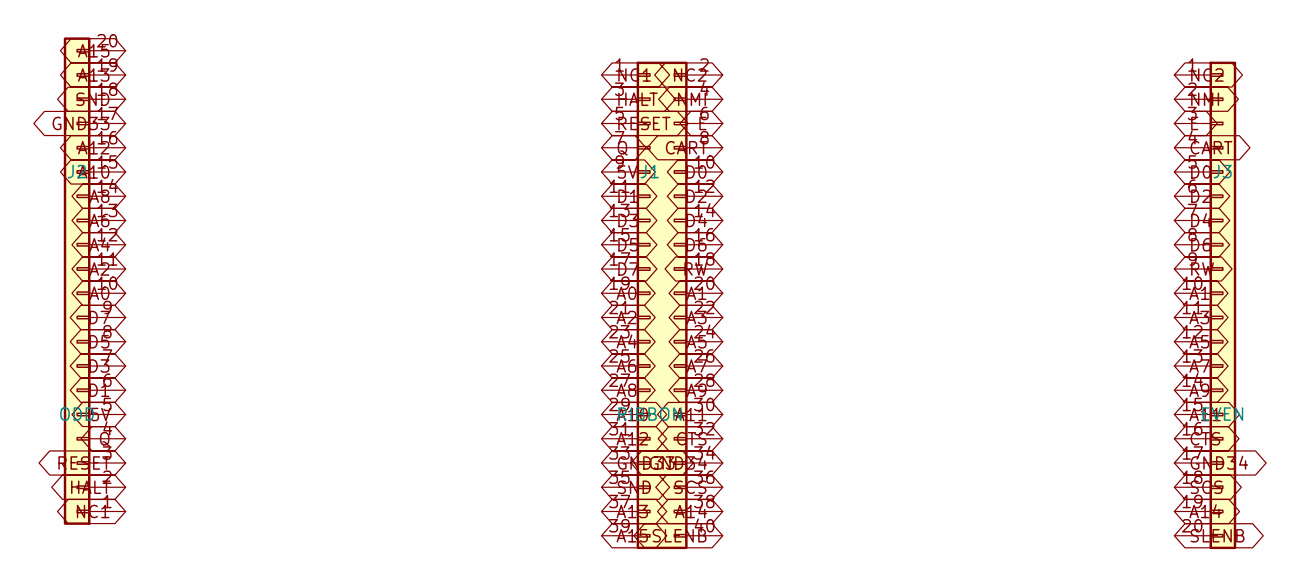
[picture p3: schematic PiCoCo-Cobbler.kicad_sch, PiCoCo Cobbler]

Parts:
J1: RIBBON; IDC-Header_2x20_P2.54mm_Vertical
J2: ODD; PinHeader_1x20_P2.54mm_Vertical
J3: EVEN; PinHeader_1x20_P2.54mm_Vertical

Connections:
5V: J1.9, J2.5
A0: J1.19, J2.10
A1: J1.20, J3.10
A2: J1.21, J2.11
A3: J1.22, J3.11
A4: J1.23, J2.12
A5: J1.24, J3.12
A6: J1.25, J2.13
A7: J1.26, J3.13
A8: J1.27, J2.14
A9: J1.28, J3.14
A10: J1.29, J2.15
A11: J1.30, J3.15
A12: J1.31, J2.16
A13: J1.37, J2.19
A14: J1.38, J3.19
A15: J1.39, J2.20
CART: J1.8, J3.4
CTS: J1.32, J3.16
D0: J1.10, J3.5
D1: J1.11, J2.6
D2: J1.12, J3.6
D3: J1.13, J2.7
D4: J1.14, J3.7
D5: J1.15, J2.8
D6: J1.16, J3.8
D7: J1.17, J2.9
E: J1.6, J3.3
GND33: J1.33, J2.17
GND34: J1.34, J3.17
HALT: J1.3, J2.2
NC1: J1.1, J2.1
NC2: J1.2, J3.1
NMI: J1.4, J3.2
Q: J1.7, J2.4
RESET: J1.5, J2.3
RW: J1.18, J3.9
SCS: J1.36, J3.18
SLENB: J1.40, J3.20
SND: J1.35, J2.18

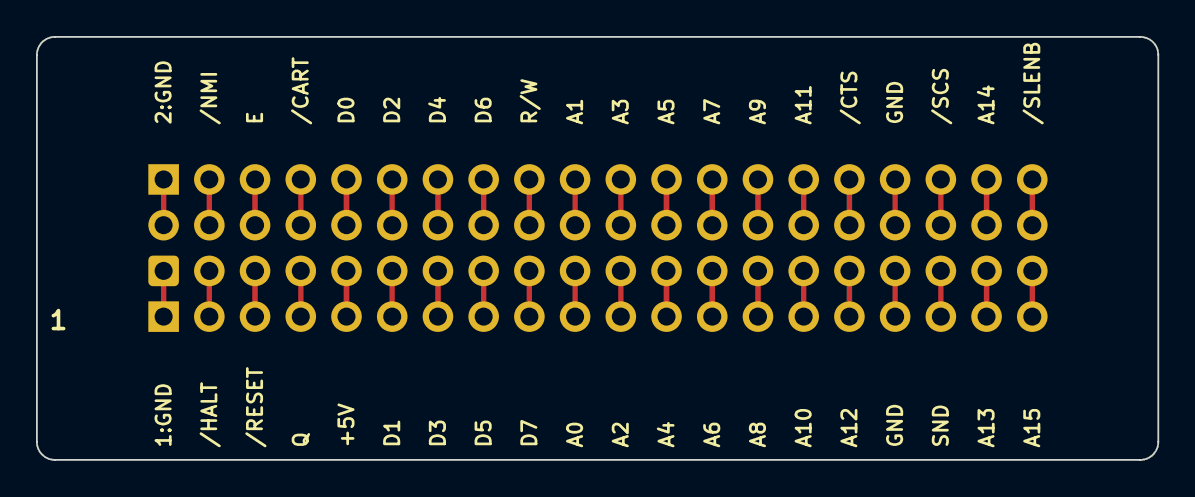
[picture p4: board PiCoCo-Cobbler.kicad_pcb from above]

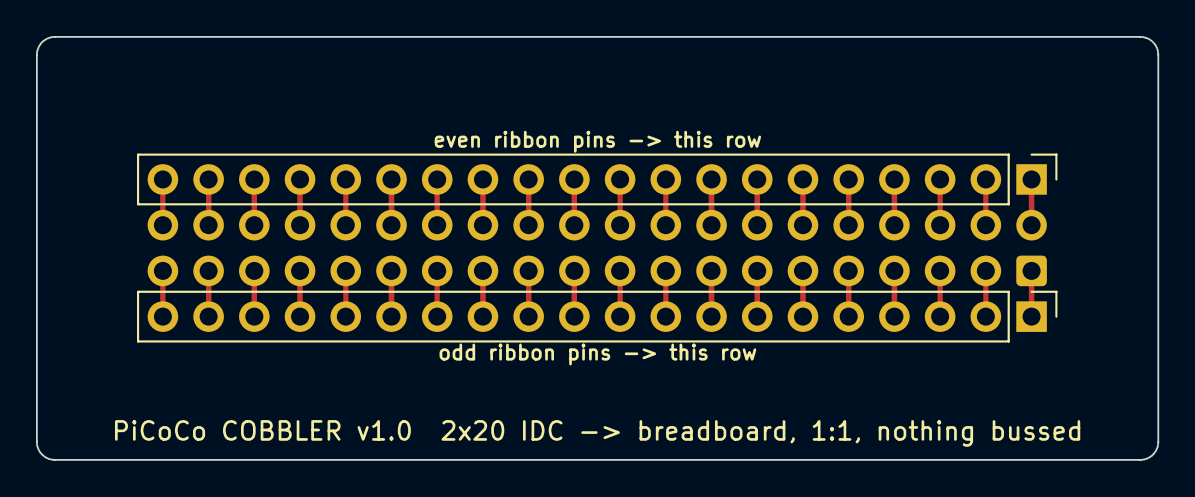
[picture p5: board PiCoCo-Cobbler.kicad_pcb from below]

Board: 2 copper layers, 62.3 x 23.5 mm, 3 parts (2 on the bottom side), 40 nets.

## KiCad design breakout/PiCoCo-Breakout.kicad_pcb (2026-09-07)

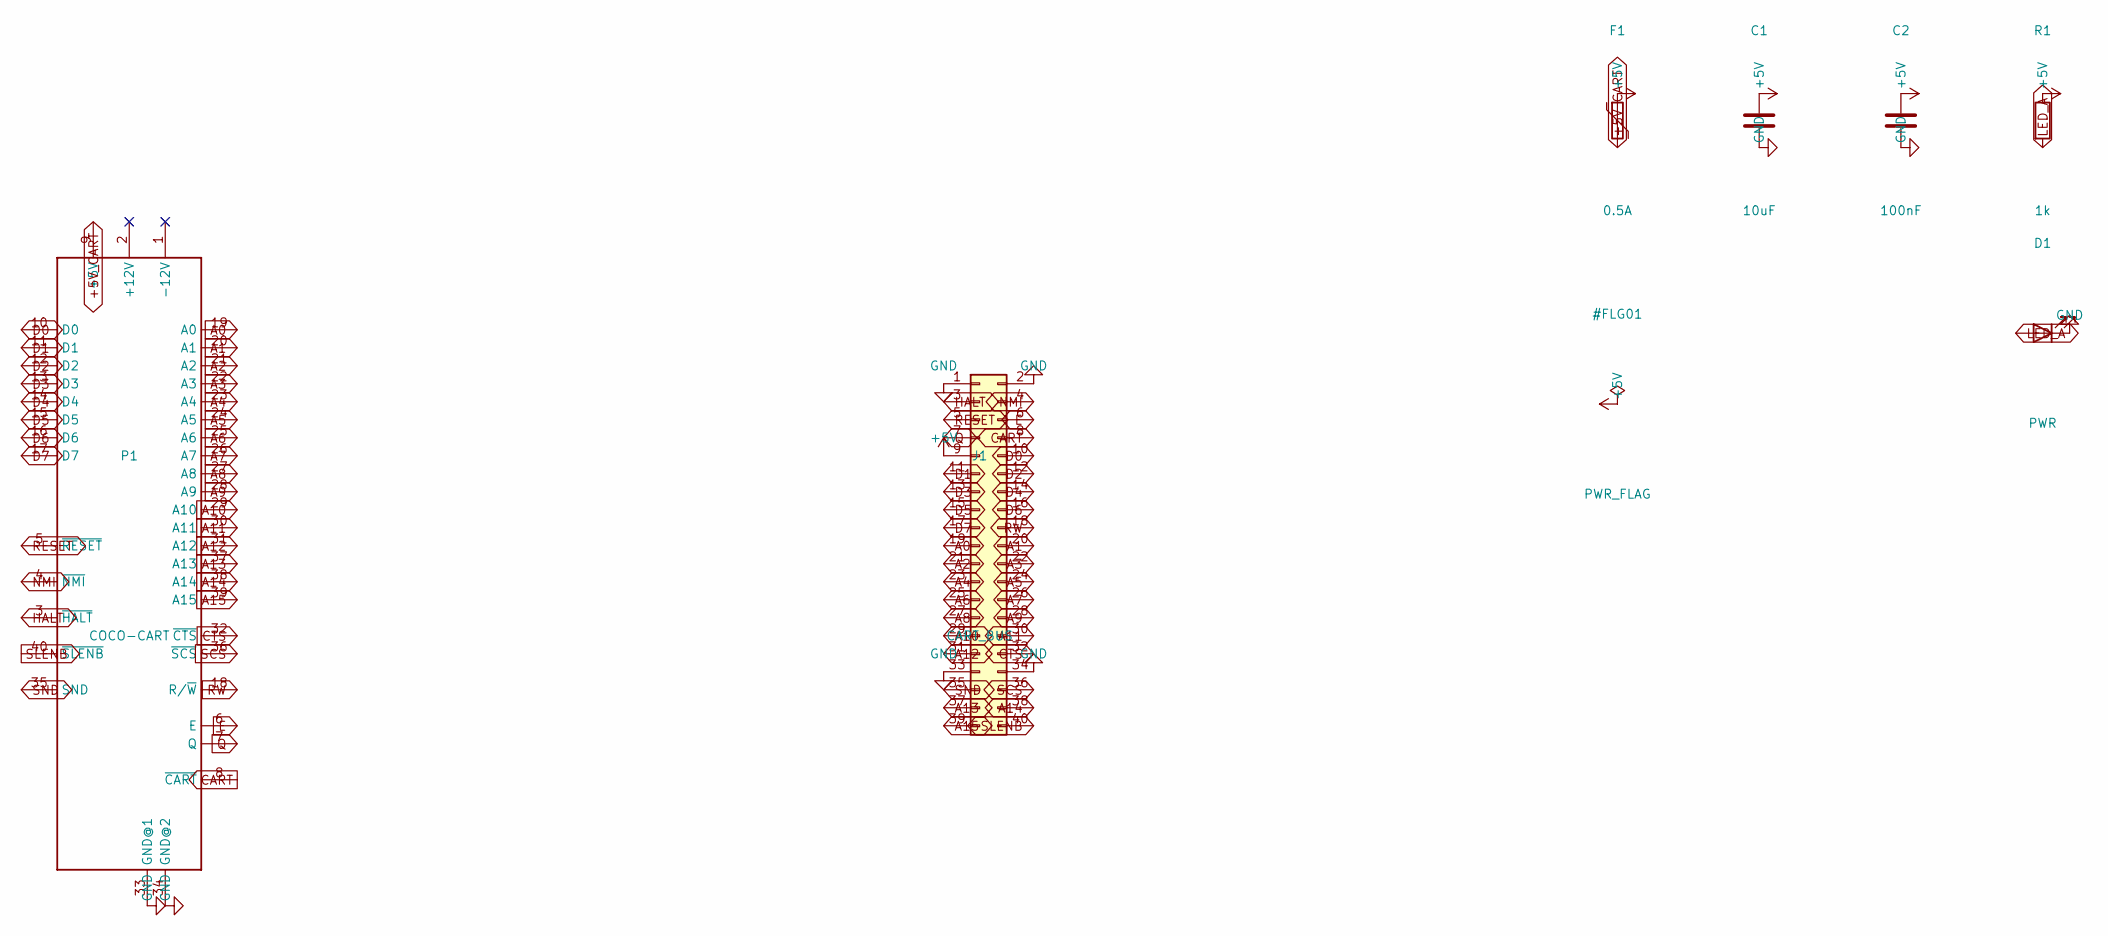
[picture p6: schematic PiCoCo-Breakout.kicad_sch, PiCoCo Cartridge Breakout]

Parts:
C1: 10uF; C_0805_2012Metric
C2: 100nF; C_0805_2012Metric
D1: PWR; LED_0805_2012Metric
F1: 0.5A; Fuse_1812_4532Metric
J1: CART_BUS; IDC-Header_2x20_P2.54mm_Vertical
P1: COCO-CART; COCO-CART-FINGERS
R1: 1k; R_0805_2012Metric

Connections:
+5V: C1.1, C2.1, F1.1, J1.9, R1.1
+5V_CART: F1.2, P1.9 (+5V)
A0: J1.19, P1.19 (A0)
A1: J1.20, P1.20 (A1)
A2: J1.21, P1.21 (A2)
A3: J1.22, P1.22 (A3)
A4: J1.23, P1.23 (A4)
A5: J1.24, P1.24 (A5)
A6: J1.25, P1.25 (A6)
A7: J1.26, P1.26 (A7)
A8: J1.27, P1.27 (A8)
A9: J1.28, P1.28 (A9)
A10: J1.29, P1.29 (A10)
A11: J1.30, P1.30 (A11)
A12: J1.31, P1.31 (A12)
A13: J1.37, P1.37 (A13)
A14: J1.38, P1.38 (A14)
A15: J1.39, P1.39 (A15)
CART: J1.8, P1.8 (~CART)
CTS: J1.32, P1.32 (~CTS)
D0: J1.10, P1.10 (D0)
D1: J1.11, P1.11 (D1)
D2: J1.12, P1.12 (D2)
D3: J1.13, P1.13 (D3)
D4: J1.14, P1.14 (D4)
D5: J1.15, P1.15 (D5)
D6: J1.16, P1.16 (D6)
D7: J1.17, P1.17 (D7)
E: J1.6, P1.6 (E)
GND: C1.2, C2.2, D1.1 (K), J1.1, J1.2, J1.33, J1.34, P1.33 (GND@1), P1.34 (GND@2)
HALT: J1.3, P1.3 (~HALT)
LED_A: D1.2 (A), R1.2
NMI: J1.4, P1.4 (~NMI)
Q: J1.7, P1.7 (Q)
RESET: J1.5, P1.5 (~RESET)
RW: J1.18, P1.18 (R/~W)
SCS: J1.36, P1.36 (~SCS)
SLENB: J1.40, P1.40 (~SLENB)
SND: J1.35, P1.35 (SND)

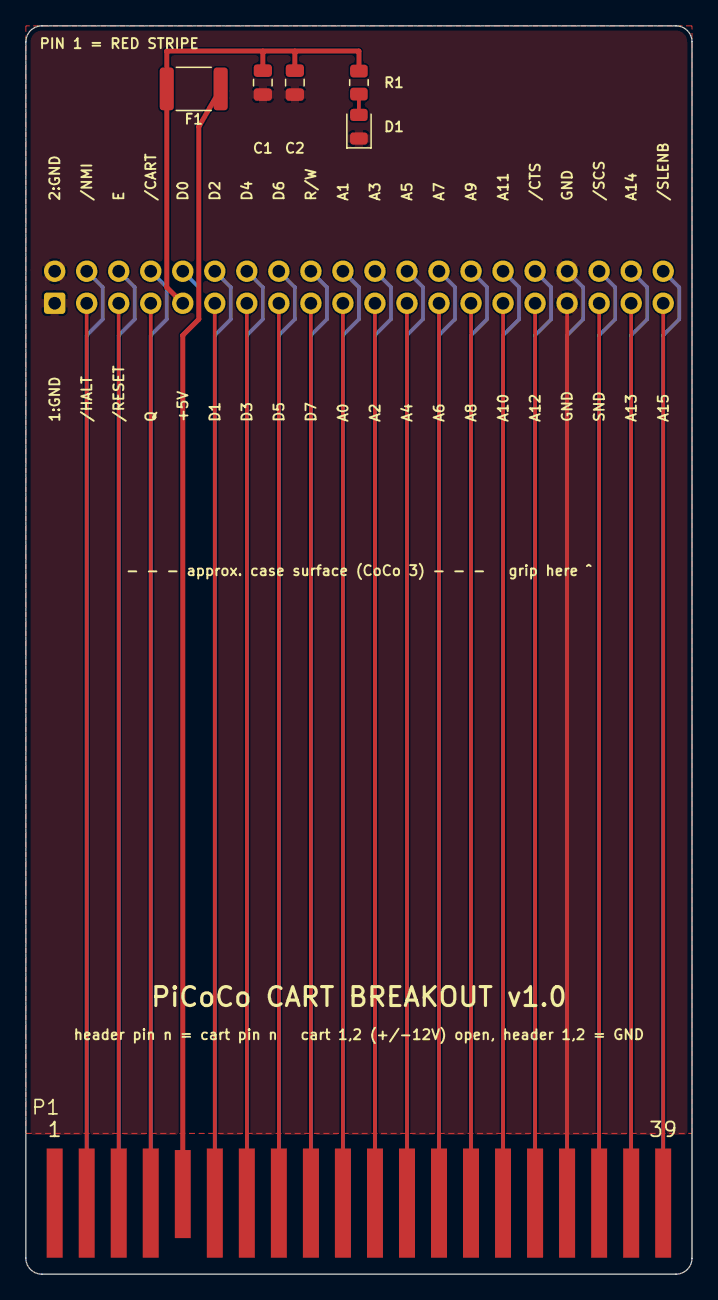
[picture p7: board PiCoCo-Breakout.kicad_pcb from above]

Board: 2 copper layers, 52.8 x 99.0 mm, 7 parts (0 on the bottom side), 39 nets.

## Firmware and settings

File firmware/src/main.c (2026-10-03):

#include "pico/stdlib.h"
#include "pico/multicore.h"
#include "hardware/watchdog.h"
#include <string.h>
#include "tusb.h"
#include PICOCO_BOARD_H
#include "bus.h"
#include "bus_engine.h"
#include "device.h"
#include "rom.h"
#include "becker.h"
#include "dw.h"
#include "dw_store.h"
#include "log.h"
#include "console.h"
#include "mode.h"
#include "plat.h"
#include "fs_flash.h"
#include "crash.h"
#include "net.h"

static dw_server g_dw;
static dw_store  g_store;

static uint32_t mode_get_u32(void) { return (uint32_t)mode_get(); }

static void console_out(void *ctx, const char *s) {
    (void)ctx;
    if (!tud_cdc_n_connected(1)) return;              /* drop when nobody is listening */
    size_t len = strlen(s), off = 0;
    while (off < len) {
        uint32_t avail = tud_cdc_n_write_available(1);
        if (avail == 0) {
            /* ponytail: bounded 50 ms wait for the host to drain its FIFO
             * (status/stats/trace dump can exceed the 512-byte TX buffer in
             * one console_feed call); past the deadline drop the rest rather
             * than block the main loop indefinitely. */
            uint32_t deadline = plat_now_ms() + 50;
            // ponytail: re-enters tud_task(); safe only while no TinyUSB callback prints or logs-with-drain
            do { tud_task(); watchdog_update(); avail = tud_cdc_n_write_available(1); }
            while (avail == 0 && plat_now_ms() < deadline);
            if (avail == 0) break;
        }
        uint32_t chunk = avail < (uint32_t)(len - off) ? avail : (uint32_t)(len - off);
        off += tud_cdc_n_write(1, s + off, chunk);
        tud_cdc_n_write_flush(1);
    }
}
static void gpio_setup(void) {
    for (int g = 0; g < 48; g++) {
        if (PICOCO_INPUT_MASK & (1ULL << g)) { gpio_init(g); gpio_set_dir(g, GPIO_IN); gpio_pull_up(g); }
    /* D0-D7 idle LOW, not high: U10 is enabled by hardware (E-qualified /OE) from the
     * start of every cart read, so whatever the Pico's data pads hold before core1
     * drives them is what the CoCo sees if the drive lands late. Pulled up that was
     * 0xFF, whose bit 1 reads as Becker "data ready": one late $FF41 poll made the
     * CoCo read a phantom byte and desynced the whole stream (PCB bench 2026-09-30,
     * 1.79 MHz). Pulled down a late poll reads 0x00, not ready, and is retried. */
    for (int g = PIN_D0; g < PIN_D0 + 8; g++) gpio_pull_down(g);
    }
    gpio_init(PIN_HALT); gpio_put(PIN_HALT, 1); gpio_set_dir(PIN_HALT, GPIO_OUT);   /* latch the value before enabling the output so /HALT never glitches low; keep it asserted until released after core1 launch, below */
#ifdef PIN_CART_DRV
    gpio_init(PIN_CART_DRV); gpio_set_dir(PIN_CART_DRV, GPIO_OUT); gpio_put(PIN_CART_DRV, 0);   /* keep /CART released (Q4 off) */
#endif
#ifdef PIN_OE_FW
    gpio_init(PIN_OE_FW); gpio_put(PIN_OE_FW, 1); gpio_set_dir(PIN_OE_FW, GPIO_OUT);   /* buffer disabled until core1 selects a cycle */
#endif
#ifdef PIN_LED
    gpio_init(PIN_LED);  gpio_set_dir(PIN_LED, GPIO_OUT);
#endif
}
int main(void) {
    gpio_setup();
    bool dbl_reset = plat_double_reset();
    tusb_init();
    log_init();
    bus_init(); device_reset(); rom_init(); becker_init(); device_init_all();
    dw_store_fatfs_init(&g_store);
    dw_init(&g_dw, &g_store, mode_dw_send, NULL);
    console_init(console_out, NULL, &g_dw, &g_store);
    net_init();
    bus_engine_init();   /* after net_init: the cyw43 driver claims PIO2 (GPIO base 16) first */
    /* core1 straight after the event stream starts, so no event waits unread
     * through the config replay and the net hold (more than 2048 would lap
     * the ring). Every hook is registered above; the config's rom load and
     * bank changes take the engine lock (rom.c). /HALT stays held until below. */
    multicore_launch_core1(bus_core1_main);
#ifdef PICOCO_HAVE_NET
    net_dw = &g_dw;
#endif
    crash_init();
    crash_mode_hook = mode_get_u32;
    plat_reset_latch();   /* before watchdog_enable() below clobbers the marker it reads */
    watchdog_enable(8000, true);
    LOG_I(LOG_M_MAIN, "boot, reset log %u", (unsigned)plat_double_reset_seen());
    if (fs_flash_mount() == 0) {
        int n = console_run_config();
        if (n < 0) LOG_I(LOG_M_MAIN, "fs ok, config: none");
        else LOG_I(LOG_M_MAIN, "fs ok, config lines %d", n);
    } else {
        LOG_E(LOG_M_FS, "fs mount failed");
    }
    if (dbl_reset) {
        console_boot_manager();
        LOG_I(LOG_M_MAIN, "double reset: manager for this boot");
    }
    /* becker net in the config: hold /HALT (already asserted by the boot
     * pull-up) until the server socket is up, at most NET_BOOT_HOLD_MS, so a
     * CoCo never sees a half-connected board. Fall back to native otherwise:
     * the saved config still says net and the next boot tries again. */
    if (mode_get() == MODE_NET) {
        uint32_t t0 = plat_now_ms();
        while (net_state() != NET_UP && plat_now_ms() - t0 < NET_BOOT_HOLD_MS) {
            plat_double_reset_tick(plat_now_ms());
            tud_task();
            net_poll(plat_now_ms());
            watchdog_update();
        }
        if (net_state() == NET_UP) {
            LOG_I(LOG_M_MAIN, "net up in %u ms", (unsigned)(plat_now_ms() - t0));
        } else {
            LOG_I(LOG_M_MAIN, "net failed (%s), native fallback", net_last_error()[0] ? net_last_error() : "timeout");
            mode_set(MODE_NATIVE);
            console_set_boot_mode(MODE_NET);   /* keep the saved intent */
        }
    }
    int64_t rtc;
    if (plat_rtc_get(&rtc)) dw_time_set(&g_dw, rtc, plat_now_ms());
    gpio_put(PIN_HALT, 0);   /* release /HALT: spec 8.1 */
    LOG_I(LOG_M_MAIN, "core1 up, halt released, bus cycles %u", (unsigned)bus_stats.cycles);   /* nonzero: selects during the hold */
#ifdef PIN_CART_DRV
    /* Autostart paks expect /CART pulsing after reset (a real pak ties it to
     * Q). Toggle Q4 for 500 ms after the /HALT release so Color BASIC's
     * cart check sees an edge after it has initialised the PIA; DOS ROMs
     * ("DK") never get this, they would jump to $C000 as code. /RESET drives
     * the Pico's RUN pin through U13/R9 (hardware-design.md §4.5), so a CoCo
     * reset-button press reboots the Pico too and repeats this whole boot
     * sequence, pulse included — this is not power-on/Pico-reboot only. */
    /* Not after a double RESET: the manager is a DK image, and /CART would send BASIC to $C000. */
    uint32_t cart_until = (rom_cart_wanted() && !dbl_reset) ? plat_now_ms() + 500 : 0;
#endif
#ifdef PIN_LED
    uint32_t last_blink = 0; bool led = false;
#endif
    for (;;) {
        tud_task();
        uint32_t now = plat_now_ms();
        plat_double_reset_tick(now);
        mode_pump(&g_dw, now);
        bus_engine_tick(now);
        net_poll(now);
#ifdef PIN_CART_DRV
        if (cart_until) {
            if (now < cart_until) gpio_put(PIN_CART_DRV, now & 1);
            else { gpio_put(PIN_CART_DRV, 0); cart_until = 0; }
        }
#endif
        if (tud_cdc_n_available(1)) { uint8_t b[64]; uint32_t n = tud_cdc_n_read(1, b, sizeof b); console_feed(b, n); }
        if (tud_cdc_n_connected(1)) {
            /* Only drain (i.e. pop) log lines with a host attached, so boot
             * lines survive a reboot's reconnect gap for "log dump". */
            char lb[256]; size_t ln = log_drain(lb, sizeof lb - 1);
            if (ln) { lb[ln] = 0; console_out(NULL, lb); }
        }
#ifdef PIN_LED
        if (fs_flash_exporting()) {
            gpio_put(PIN_LED, 1);   /* solid while the USB drive is exported */
        } else {
            uint32_t period = mode_get() == MODE_NATIVE || mode_get() == MODE_NET ? 250 : 500;  /* 2 Hz native, 1 Hz otherwise */
            if (now - last_blink >= period) { last_blink = now; led = !led; gpio_put(PIN_LED, led); }
        }
#endif
        watchdog_update();
    }
}

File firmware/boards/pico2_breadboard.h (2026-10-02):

#pragma once
/* PiCoCo wiring for a Raspberry Pi Pico 2 (RP2350A module) — the breadboard
 * bring-up rig and also the v2.3.1 PCB's Pico 2 build.
 * See docs/firmware-architecture.md sec 3.2 for the pin table and PIO rationale. */
#include "pico/stdlib.h"   /* pulls in the SDK's boards/pico2.h, defining PICO_DEFAULT_LED_PIN */

#define PIN_D0      0    /* D0..D7  = GP0..GP7 */
#define PIN_A0      8    /* A0..A13 = GP8..GP21 */
#define PIN_RW      22
#define PIN_OE_BUS  26
#define PIN_HALT    27   /* HALT_GATE: HIGH holds /HALT low (Q2 on) */
#define PIN_LED     PICO_DEFAULT_LED_PIN
/* GP28 is AUDIO_PWM by default as of v2.3.1 (JP3 1-2) — no sound firmware yet
 * (roadmap item 11), so it is left uninitialised: neither driven nor pulled.
 * GP26/GP8-22 are taken over by PIO1 during `bus selftest` only (fake6809.c). */

/* Pull-up input pins for main.c's gpio_setup(): D0-7, A0-13, /R/W, OE_BUS. */
#define PICOCO_INPUT_MASK ((0xFFULL << PIN_D0) | (0x3FFFULL << PIN_A0) | (1ULL << PIN_RW) | (1ULL << PIN_OE_BUS))


/* On-flash FAT filesystem: firmware occupies 0x000000..0x17FFFF, this
 * partition is the rest of the Pico 2's 4 MB flash (see fs_flash.h). */
#define PICOCO_FS_OFFSET 0x180000u
#define PICOCO_FS_SIZE   0x280000u   /* FAT12, 640 clusters at 4 KB each */

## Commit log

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2026-09-07 firmware: DriveWire server core (parser, control ops, READ, WRITE)
    Adds dw.h/dw_server.c implementing the DriveWire wire protocol state
    machine: byte-at-a-time parser (dw_feed) driven by a per-opcode
    payload-length table, dispatch for NOP/TERM/RESETx/INIT/DWINIT/TIME/
    READ/REREAD/WRITE/REWRITE, HDB-DOS drive-by-LSN splitting, mount/eject,
    and a 250ms payload timeout via dw_tick. Recognizes but defers the
    READEX/serial/NAMEOBJ opcode family for Task 4 to extend without
    reshaping the parser.
    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
2026-09-08 firmware: USB composite device, console over CDC1, platform basics, watchdog
    Adds the TinyUSB composite device (CDC0 DriveWire bridge, CDC1 console,
    MSC stubbed as no-medium until Task 4), plat_pico.c implementing every
    plat_* hook, and main.c wiring bus/device/dw/console/mode together with
    a watchdog and LED heartbeat. dw_store gets a static none_ops backend
    (open/create/read/write/size/sync all fail cleanly) so DriveWire mount
    and ROM/capture load paths error out instead of touching a NULL store
    until Task 3 lands FatFS. CMake shares CORE_SRC between the host and
    Pico targets and version-stamps both builds.
    Claude-Session: https://c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
    [main.c, pico2_breadboard.h, plat_pico.c]
2026-09-08 firmware: fix HALT-gate and console drain bugs from Task 2 review
    plat_smoke's GPIO restore loop left PIN_HALT (GP27) as an input, which
    silently no-ops plat_halt() until reboot; it now skips PIN_HALT in the
    restore and re-asserts it as an output driven high, matching the boot-time
    invariant. The same loop never toggled PIN_LED (GP25, excluded as
    "internal" for bus purposes but also the on-board LED) so smoke gave no
    visible feedback; it now blinks the LED alongside the bus toggle.
    console_out (CDC1) wrote the whole reply in one non-chunked call, so any
    console output past TinyUSB's 512-byte TX FIFO (status/stats/trace dump)
    was silently dropped. It now writes in FIFO-sized chunks and, when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
    [main.c, pico2_breadboard.h, plat_pico.c]
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2026-09-08 firmware: fix FatFS lock cap, flash n=0 underflow, core0 stack, pconsole.py
    Review fixes for the FatFS/dw_store_fatfs/dw-selftest task:
    - FF_FS_LOCK raised 4->8 (pool of 6 FIL slots + an open dir was already
    over the old cap, so dw capture/fs ls could fail with 4 disks mounted).
    - fs_flash_read_blocks/fs_flash_write_blocks reject n==0 before the bounds
    check, which otherwise underflowed and could erase the whole partition.
    - Core0 stack raised 2 KB->4 KB via PICO_STACK_SIZE, plus static'd a few
    console buffers that were still on that stack; verified from the link
    map, not just the define.
    - pconsole.py opens the port O_NONBLOCK so it doesn't hang waiting for
    carrier detect on macOS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
    [plat_pico.c]
2026-09-08 firmware: USB mass storage export of the flash FAT volume
    fs export unmounts FatFS and presents the flash partition as a PICOCO
    volume over USB MSC (refused while any DriveWire drive is mounted); fs
    import re-mounts. LED goes solid while exporting; status reports "usb
    ejected" after the host ejects the volume. Verified end to end on target:
    export, drag a .dsk on, import, dw mount + selftest, reboot persistence.
    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
    [main.c, plat_pico.c]
2026-09-08 firmware: fix capture hole in fs export/format, guard commands during export
    fs format/export now also refuse while a "dw capture" file is open, not
    just while a DriveWire drive is mounted (fs_busy_reason() covers both).
    fs/dw commands other than "fs import" now refuse outright while exporting,
    so nothing can race FatFS mid-USB-transfer. Minor cleanups from review:
    plat_fs_export clears the ejected flag on both directions, fs_flash_export
    reuses fs_flash_unmount(), and MSC read10/write10 share one scratch buffer.
    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
    [plat_pico.c]
2026-09-08 firmware: core1 bus loop, halt release, crash record, bus drive
    Adds the flash-free core1 cart-bus polling loop (bus_core1_main), releases
    /HALT once it's running, records HardFault/panic info in uninitialized SRAM
    so it survives the watchdog reboot, and gates driving D0..D7 behind a new
    bus drive on|off console switch so bring-up can start capture-only.
    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
    [main.c]
2026-09-08 firmware: fix Task 5 review findings (panic pc, watchdog vs reboot, SRAM fault path)
    Two correctness bugs from review: picoco_panic recorded the SDK's assembly
    thunk address instead of the real panic() caller (needed
    PICO_PANIC_FUNCTION_DOES_NOT_RETURN=1 + noreturn), and plat_last_reset
    always reported "watchdog" for any reset because main.c's own
    watchdog_enable() call re-stamps the marker before any console command can
    read it - now latched before that call so a commanded reboot correctly
    reads "reboot". Also moves the hardfault path into SRAM, only drains the
    log ring when a host is attached so boot lines survive a reconnect, narrows
    plat_smoke to the pins the Pico actually owns, adds a h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
    [main.c, plat_pico.c]
2026-09-08 firmware: final review fixes (import eject guard, stack guards, name length, version, minors)
    Applies the whole-branch review's fix list before merge: fs import now
    refuses until the PICOCO volume is ejected on the host, the Pico build
    enables SDK 2.3.1 per-core MPU stack guards, dw_disk_open rejects
    over-long mount names at mount time instead of truncating them, and
    the version bumps to 0.3-pico. Plus one-line fixes: crash record magic
    written last so a partial record self-invalidates, rom_load_mem's 16K
    path never touches becker's two bus_table indices, a smoke-duration
    comment fix, a watchdog pet per flash block outside the interrupts-off
    window, a clearer "config: none" boot log, rom loa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
    [main.c, plat_pico.c]
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2026-09-17 kicad: v2.3 placement, antenna and HDMI rule areas, silkscreen
    Placement table for the v2.3 refresh (Pico-Carrier module, LVC245/LVC00
    buffers, sound stage, JP2/JP3, fiducials), antenna and HDMI-reserve
    keepout zones, and silkscreen texts via place_pcb.py's add_board_extras().
    Deviations from the task-4 brief, found via measured courtyard/pad
    geometry after placement (not guessed):
    - U14/C1 moved +/-3mm in x; D2's 7mm-wide courtyard didn't fit the
    brief's gap between them.
    - Decoupling caps C4/C6/C7/C8 moved from y=84.0 to y=83.0; the buffer
    ICs' courtyard starts at y=85.35, so y=84.0 clipped it by ~0.35mm.
    - JP3/C10 moved +8mm in x; at the brief's x=152 both sat inside U1's
    courtyard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
    [PiCoCo.kicad_pcb]
2026-09-17 kicad: place_pcb rotates pad/text angles with the footprint; drop MTG1; strip debug silk; board text fixes
    F1: place_pcb.py's PLACEMENT-driven rotation only updated a footprint's own
    (at X Y rot); KiCad stores every pad/fp_text/property (at x y [angle]) as an
    ABSOLUTE angle, so pad copper/text shapes went stale relative to the newly
    rotated footprint (the 76 U1-only shorting_items and every rotated 0805's
    DRC noise). Added _rotate_child_angles() (adds the rotation delta to every
    child's angle, inserting one where absent; positions are untouched, they're
    footprint-local and KiCad reinterprets them under the new rotation itself)
    and an assert-based self-check that every pad's absolute angle ma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
    [PiCoCo.kicad_sch]
2026-09-17 kicad: v2.3 placement on the re-synced board, DRC error-free before routing
    Ruling (b) applied: place_pcb.py now SETS every placed footprint's pad,
    fp_text and property angles to the footprint's own target rotation directly
    (not delta-added to whatever was on file), since every part on this board
    has zero relative pad rotation in its library copy. This self-heals stale
    angles regardless of whether the footprint's own rotation is changing this
    run (the R10/C10 concern from the prior round), while leaving
    already-correct footprints byte-identical (angle only rewritten when it
    differs from the target). Verified with unit tests covering all four cases:
    already-at-target no-op, stale-angle self-h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
    [PiCoCo.kicad_pcb]
2026-09-17 kicad: placement fixes from review (text angles by delta, legends off the module, FID1, text replace)
    F1 IMPORTANT: ruling (b) from the prior round was wrong for fp_text/property
    angles. Pico-Carrier's 40 pin labels are 45deg relative to the footprint,
    and reference/value auto-text is 180deg relative on some parts; setting
    every child to the footprint's absolute target angle flattened those
    relative offsets (most of the prior round's silk warnings). New rule:
    pads -> SET to the target rotation (unchanged, correct for pads on this
    board). fp_text/property -> ADD (target - old_footprint_rotation) mod 360,
    preserving whatever relative angle KiCad wrote them with at sync time. Pad
    self-check kep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
    [PiCoCo.kicad_pcb, PiCoCo.kicad_sch]
2026-09-17 kicad: place_pcb takes text angles from the library; U1 pin labels restored
    F1 re-review finding: the prior round's ADD-delta rule computed delta from
    the footprint's rotation as read from the FILE, which cannot heal a board
    an earlier run already flattened -- if the file's rotation already equals
    the target, delta is 0 and a stale value stays stale forever. On the real
    (round-2-then-round-3) board this manifested as U1's 45 fp_text pin labels
    sitting at 90 instead of 135.
    Replaced the delta rule: for every fp_text/property child, look up its
    own angle in the footprint's LIBRARY .kicad_mod file (not the placed
    instance) and compute `(target_rot + library_relative_angle) mod 360`
    directly. _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
    [PiCoCo.kicad_pcb]
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2026-09-18 kicad: v2.3 fully routed, GND pours, DRC clean
    - Default netclass 0.20 mm track / 0.15 mm clearance (was 0.25/0.20): lets
    Freerouting close 16 -> 7 nets; vias stay 0.8/0.4 mm.
    - place_pcb: track/via keepouts round U1's four NPTH holes (hole clearance is
    not expressible in a Specctra DSN).
    - tools/grid_route.py: A* grid router on pcbnew shape collisions; finished
    the 7 nets Freerouting could not (rip-up of U11's address stubs and the
    A6_BUF tail so U11 pin 10 GND could escape).
    - tools/pour.py: GND pours both layers; tools/gnd_fix.py: links stray GND
    clusters (pads, vias, tracks, pour islands) and starved thermals.
    - DRC (--severity-all --schematic-parity): 0 errors, 0 unconnected,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
    [PiCoCo.kicad_pcb]
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2026-09-18 kicad: review fixes for the routing tools and design rules
    - grid_route.py: --pair only (no stale HINTS table), refills zones before
    saving, exit 1 on failure, documents the grid_route -> pour -> gnd_fix order.
    - gnd_fix.py: exit 1 when a cluster stays open, empty-candidate guard, hint
    when --drc is omitted.
    - pour.py: pour outline = board outline inset 0.3 mm, cut 1 mm above the
    finger area read from P1's rule areas (was a hardcoded 99.7); edit the
    zone's own outline (SetOutline hands over ownership and segfaults).
    - Design rules: min track 0.127, min clearance 0.127, copper-to-edge 0.2
    (JLC floor). Re-poured; a redundant stitch via under U11 pin 10 removed.
    - DRC --severity-all -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
    [PiCoCo.kicad_pcb]
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2026-09-18 v2.3.1: body grown 12 mm, JP3 audio default, pre-order fixes (schematic, outline, docs)
    Measured CoCo 3 opening 114.3 x 30.2 mm, connector face 43 mm inside the
    case: the 98 mm body fits, but the module USB-C sat on the case surface.
    Body is now 98 x 67.16 mm (+10.16 mm tongue); module, TPs, JP3, HDMI
    reserve move up 12 mm.
    Schematic (gen_schematic.py): R7 10k (RP2350 reset pull-down beat 100k),
    R10 DNP (held RUN low when USB-only), R3 populated, R23 10k pull-up on
    SLENB_CART (pin 40 is cart->CoCo), R25 10k pull-up on U10_OE, C15 1uF DNP
    in series with R24 0R bypass (true AC-coupling option), JP4 Q->/CART
    solder jumper (autostart tie), TP8 GND, FID3, JP3 pin 1 = AUDIO_PWM
    (audio default), 1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
    [PiCoCo.kicad_sch]
2026-09-18 kicad: v2.3.1 routed on the grown outline, DRC clean, fab package regenerated
    Freerouting (100 passes, 0.20/0.15 netclass) + tools/finish_route.py (new
    driver: strip GND, grid-route the leftovers, restore GND, pour, close GND,
    DRC). grid_route via placement now honours hole-to-hole spacing across
    nets. Cart GND/+5V neck tracks widened to 0.5 mm.
    DRC --severity-all --schematic-parity: 0 errors, 0 unconnected, 0 parity,
    61 silk warnings. BOM 16 lines, CPL 34 parts, module stencil 55 apertures,
    production paste 177.
    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
    [PiCoCo-BOM-jlc.csv, PiCoCo.kicad_pcb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]
2026-09-18 v2.3.1: silk revision, exact dimensions, bare-board README, review nits
    - Back silk reads v2.3.1; checklist/spec/docs say 98 x 77.2 mm overall
    (67.0 mm body + 10.16 mm tongue), matching Edge.Cuts.
    - README.md: orientation, power-off insertion, module mounting and the
    Pico 2 tape note, JP2/JP3/JP4 defaults, DNP list, TP map, flashing incl.
    BOOTSEL + CoCo RESET, images, Multi-Pak note.
    - gen_schematic: R25 comment corrected. Fab package regenerated (silk only).
    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
    [PiCoCo.kicad_pcb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]
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2026-09-19 kicad: v2.3.1 routed with the quality changes; GND stitched; fab package regenerated
    - Re-routed from scratch (Freerouting + finish_route) with JP5, J1 (left strip at
    112,60), C16, the 0.5 mm Power netclass and the x-widened antenna keepout.
    - gnd_stitch: GND via within 1.0-1.6 mm of every decoupling cap GND pad (was
    5-15 mm), 60 GND vias total (0.79/cm2, was 0.53); U1 pin 13 solid-connected.
    - DRC --severity-all --schematic-parity: 0 errors, 0 unconnected, 0 parity,
    30 silk warnings. BOM 18 lines / CPL 38 parts.
    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
    [PiCoCo-BOM-jlc.csv, PiCoCo.kicad_pcb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]
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2026-09-20 v2.3.1: J2/J3 DNP 1x3 pin-header twins of JP3/JP5 (movable shunt option)
    Same nets as the solder jumpers; fit at most one of each pair. Re-routed;
    DRC 0 errors / 0 unconnected / 0 parity; GND coverage under the bus 40%
    (was 27%). BOM/CPL unchanged (17 lines / 38 parts, headers are DNP).
    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
    [PiCoCo.kicad_pcb, PiCoCo.kicad_sch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]
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2026-09-23 firmware: latch /HALT before enabling its output, not after
    gpio_put(PIN_HALT, 1) ran after gpio_set_dir(PIN_HALT, GPIO_OUT), so the
    pin could briefly drive whatever gpio_init() left in the output latch
    (low) before the put took effect. Set the latch first, then switch to
    output, so /HALT never glitches low at boot.
    [main.c]
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2026-09-24 coco: main screen - browse, mount, eject, new, save
    Adds ui.c/ui.h (the 32x16 browse/mount/eject/new/save screen), a Task-14
    stub boot.c/boot.h, and wires main.c to ui_run(). Fixes two bugs found
    during on-device XRoar verification: a real CMOC codegen bug where
    `!func(...)` used inline miscompiles (parse.c's .ROM filter was silently
    passing ROMs through; switched to `func(...) == 0`), and a naming
    collision between the brief's `cls()` and CMOC's own `coco.h` cls(byte)
    (renamed ours to clear_screen()).
    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
    [main.c]
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2026-09-28 firmware: refuse cart on/off without a Plus-W /CART pin; bench ctest opt-in
    - console.c: cmd_cart refuses "on"/"off" with "cart: needs Plus-W (JP5 on
    a Pico 2)" when PICOCO_BOARD_H is defined but the board header has no
    PIN_CART_DRV (i.e. a Pico 2 build). "auto" and the bare query still work
    on both boards; the host build defines no PICOCO_BOARD_H so its
    behaviour, and test_console, are unchanged.
    - console.c: fix the "bus selftest" host-build refusal text to "pico only
    (host build)" — PICOCO_HAVE_FAKE6809 is set for both Pico boards now,
    not just the Pico 2, so the old "not Plus-W or host" wording was wrong.
    - CMakeLists.txt: add PICOCO_BENCH (default OFF) and register the ben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
    [main.c, plusw.h]
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2026-09-28 firmware: selftest burst response sweep; counter-race waits; OE_BUS rescue stat; rom_off on failed banked load
    [fake6809.c]
2026-09-30 bench: bridge mode, latency limit, AON clock, CoCo manager on the CoCo 3
    Breadboard session 2026-09-29 with firmware 1.2 on a Pico 2:
    - becker_relay.py: CDC0 <-> TCP relay with --delay/--jitter for latency
    tests. Bridge mode passes against picoco-host and DriveWire 4.3.6p;
    a remote server must answer within ~200 ms round trip or the server's
    per-op timeout drops the READEX and the CoCo hangs (documented).
    - plat_rtc on the Pico now uses pico_aon_timer (plan Task 8): the clock
    survives a watchdog reboot and a BOOTSEL reflash.
    - dw_mount returns -3 when the image is already open read-write in another
    drive (FatFS FS_LOCK refuses the reopen); console says "already mounted".
    Host tes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
    [plat_pico.c]
2026-09-30 firmware: selftest drains stale write events before its baselines; names the first mismatch
    Bench 2026-09-29 on a bare Pico 2 (bench.py): 12/13, write_data_captured
    failed because a stray idx-0 cycle from the pin takeover (~130 us before the
    first real cycle, R/W random) sat at the head of the write ring. The Plus-W
    never saw it since its decode also needs /CTS or /SCS low. Drain the ring
    where cyc0/wr0 are captured, and print got/want for the first mismatch.
    After the fix: 13/13 three runs in a row, read response ~264 ns after
    OE_BUS fell.
    Claude-Session: https://claude.ai/code/session_01ATZy2AnSdF2UqmyFpvSTUB
    [fake6809.c]
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2026-10-01 firmware: core1 precomputes the read response; D0-D7 idle low; PCB bring-up log
    First v2.3.1 PCB (Pico 2, CoCo 3) passed bring-up 2026-09-30, but the
    1.79 MHz HDB-DOS ROM (hdbdw3bc3) intermittently desynced the Becker
    stream: one underrun, pushes = reads + 1, every later sector failed its
    checksum. Two causes:
    - The Pico 2 core1 read path (sample, 70 ns resample, lookup, drive) put
    data on the bus ~245 ns after E rose; at 1.79 MHz E is high 279 ns, so
    timing tails landed in the 6809E latch window. +33 ns reproduced it on
    the first poll.
    - D0-D7 idled with pull-ups, so a late $FF41 poll showed the CoCo 0xFF
    through the hardware-enabled U10, and 0xFF has the Becker ready bit
    set: a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
    [main.c]
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2026-10-02 firmware: double RESET loads the manager for one boot
    Claude-Session: https://claude.ai/code/session_018Kxf6M2Y3x8KSxMVEtm3kk
    [main.c, plat_pico.c]
2026-10-02 firmware: double RESET marker in flash, 2 s window; CoCo 3 bench results
    Bench 2026-10-01/02: a CoCo RESET (RUN pin) clears main SRAM and the
    POWMAN scratch registers on this board, so the marker is now a byte log in
    its own flash sector below the filesystem: one byte per boot ("armed"),
    one more when the window passes. A hit holds until the window closes, and
    a 150 ms debounce keeps a chattering RESET line from arming it. The boot
    log line shows the log count. Window is 2 s of real time: the Pico
    releases /HALT ~3 ms after reset (the log stamps are microseconds).
    TEST_PLAN J.3: CoCo 3 (6309, 2 MB) read-path regression at 0.89 and
    1.79 MHz, manager keys, HDB-DOS and pak launches, double RES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
    [main.c, plat_pico.c]
2026-10-02 rom manager: CoCo 3 exits go slow and clear $FEED; header; carttest key stop; reboot disarms the reset marker; docs
    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
    [plat_pico.c]
2026-10-02 rom manager: no /CART pulse after a double RESET; stale doc lines
    Final review of the CoCo 3 batch: the manager is a DK image, so the
    autostart pulse must not follow a double RESET (Plus-W). README no
    longer says a CoCo 3 cannot launch; TEST_PLAN says 2 s; comments.
    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
    [main.c]
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2026-10-02 selftest fast: DMA-fed back-to-back 1.79/0.89 MHz read bursts (Pico 2)
    fake6809_fast on PIO1, clkdiv 1, one TX word per cycle by DMA, samples
    captured by DMA: cycle 84 clk (42 high / 42 low), address setup 25 clk,
    programmable sample point and release-check point. Baseline on the CPU
    loop: 1.79 MHz back-to-back fails on ~4095/4096 cycles at 240 ns;
    0.89 MHz passes, response_clk 44-48.
    pconsole.py: PCONSOLE_TIMEOUT env var for long commands.
    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
    [fake6809.c]
2026-10-02 Pico 2: PIO + DMA read engine replaces the core1 CPU loop (spike)
    One PIO0 SM pushes the table byte's address (base>>14<<14 | A13..A0)
    on every selected read; DMA A moves it into DMA B's READ_ADDR_TRIG,
    DMA B copies the byte into the TX FIFO, the SM drives it until OE_BUS
    rises, then drives low and releases (E9). bus_table and rom_banks are
    16 KB aligned; bus_set_rom_base() re-points the SM from core0.
    core1 idles. No hooks, writes, trace or counters on this build: the
    Becker port does not work. Old loop: tag fw-1.4-cpu-loop.
    selftest fast: 0/4096 mismatches at 240 ns, response_clk 20 (133 ns)
    at 1.79 MHz, 19 at 0.89 MHz. Legacy selftest skips its write/hook
    checks on this build. Knobs: bus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
    [fake6809.c]
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2026-10-02 Plus-W: PIO + DMA engine with a cross-block OE_BUS helper; CPU loop removed
    Read SM in PIO0 as on the Pico 2 (order B), first wait "wait 1 irq 0" and
    both end waits "wait 1 irq 2". bus_sel_pw in PIO2 (GPIO base 16, shared
    with the cyw43 driver) watches OE_BUS on GP40 and raises PIO0 flags 0/1/2
    with "irq next". Read SM and helper start and stop in one CTRL write
    (PIO2 is PIO0's prev). "bus engine trig pin" on the Plus-W is a
    calibration mode on E itself (no decode).
    engine_stop runs from SRAM with interrupts off: from flash, the first
    stop after the XIP cache was cleared out stalled between the SM disable
    and the release and held a byte through two cycles (1 spurious drive).
    Removed with t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
    [fake6809.c, pico2_breadboard.h, plusw.h]
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2026-10-02 engine: bank register read after the trigger; a bank switch is one exec, no pause
    - bus_read: `in x, 3` moves from top to after the start wait (1 clk per read:
    Pico 2 22, Plus-W 29 raw / 24 corrected). The constant part (`mov isr, y`)
    stays precomputed.
    - bus_engine_set_bank_locked: bus_bank and one exec'd `set x` under the lock.
    No pause, no PC read, no jump; erunning goes.
    - Self-test: switch bursts alternate banks 0/1 and score every read as old
    bank, new bank or bad against each switch's RX-progress window; each exec is
    placed at a random phase by the cycle counter (SRAM helper) and the cycle it
    lands in is tallied old/new by phase. Both boards: 0 bad, 0 wrong bank, the
    lan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
    [bus_engine.c, fake6809.c]
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2026-10-02 engine: stall guard, capture-only mode
    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
    [bus_engine.c, fake6809.c]
2026-10-03 engine: final-review minors; start-wait cap fails safe; event SM seeds x between cycles
    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
    [bus_engine.c, fake6809.c, main.c]
2026-10-03 engine: log the engine state and freeze the trace on a stall restart
    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
    [bus_engine.c]
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2026-10-03 engine: stall guard requires the SM to dwell at pull; count duplicate read events
    A short OE_BUS high blip near the end of a cycle makes the read SM re-push
    and pass through `pull` after the cycle is over; on a bench CoCo 2 that met
    the guard on two ticks in a row while reads were served correctly in
    between, and the restart crashed the CoCo. A lost pointer parks the SM for
    good, so a tick now counts only after 32 consecutive PC reads at `pull`.
    `event_dup` counts a read event identical to the one before it, the event
    SM's signature of the same blips (~7 % on that CoCo 2, 0 on the CoCo 3).
    Claude-Session: https://claude.ai/code/sessio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
    [bus_engine.c]
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

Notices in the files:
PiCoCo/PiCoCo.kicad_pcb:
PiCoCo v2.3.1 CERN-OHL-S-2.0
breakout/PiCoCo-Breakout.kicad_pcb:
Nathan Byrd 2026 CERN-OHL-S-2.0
